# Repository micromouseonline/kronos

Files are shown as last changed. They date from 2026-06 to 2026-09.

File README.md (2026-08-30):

# KRONOS: Hardware-Synchronized Robotic Timing Gates

**KRONOS** is a distributed, microsecond-accurate wireless robotic timing gate ecosystem built on the ESP32 platform. It is designed for high-performance track automation and precision race scoring without the need for physical connection cables.

---

## Technical Highlights

* **Hardware-Level Precision:** Achieves an average tracking accuracy gap of $2.36\,\mu\text{s}$ (with a worst-case variance of $55\,\mu\text{s}$) by anchoring remote nodes to the 1 MHz Timing Synchronization Function (TSF) clock embedded directly within Wi-Fi beacon frames.
* **Self-Healing Clock Recovery:** Eradicates tracking errors from network drops or stack resets. If a node misses AP beacons, an autonomous audit engine seamlessly reconstructs missing timestamps using a disciplined internal monotonic processor clock (`esp_timer_get_time()`).
* **Asynchronous FreeRTOS Queues:** Decouples physical event capturing from network transmission. Pins use high-speed hardware interrupts to instantly cache telemetry into RAM queues, safely buffering rapid-fire bursts down to $35\text{ ms}$ intervals.
* **Resilient Network Architecture:** Uses HTTP over TCP (`HERMES` protocol) to guarantee delivery. Variable transport latencies or retransmission lags become irrelevant because the hardware event timestamp is baked directly into the packet payload.

---

## Naming Conventions & System Layers

* **KRONOS:** The overall distributed wireless network topology and codebase.
* **HADES:** The central PC software hosting the database, event management and scoring system. *(planned, not in this repo)*
* **ATLAS:** The standalone Wi-Fi Access Point acting as the authoritative field master clock, and providing a private WiFi BSSID.
* **CERBERUS:** The multi-threaded gate edge hardware/software handling gate messages and clock audits.
* **HESPERUS:** The physical maze/track gate sensor modules.
* **HERMES:** The concise HTTP application-layer packet payload protocol.
* **ARES:** The pulse generator that stimulates the gates during testing.
* **ARGUS:** The hundred-eyed giant that collects and analyses gate data. *(planned, not in this repo)*

---

## Quick Start & Hardware Setup

### 1. Prerequisites

* **Access Point (`ATLAS`):** Any standard domestic or portable router configured as a standalone network subnet.
* **Gate Nodes:** Dual-core ESP32 or ESP32-S3 boards (standard single-core variants like the C3 require Level 2+ high-priority interrupt configurations to minimize jitter).
* **Sensors (`HESPERUS`):** Photodiode or laser break-beam circuits wired to the designated edge input pins.

### 2. Network Provisioning

The central `HADES` web server must be mapped to a fixed, unmoving network coordinate via a DHCP reservation or static IP mapping. Alternatively, the system might use multicast DNS (`mDNS`), allowing gates to dynamically connect via a hostname (e.g., `http://timing.local`).

### 3. Visual Diagnostics on Track

Onboard LEDs can provide real-time state confirmation without an attached serial monitor e.g.
* **LED Off:** System operating normally; network clearing traffic flawlessly.
* **LED Solid On:** Wi-Fi link down or server stalling; data packets are currently backing up safely inside the internal FreeRTOS memory queue.

The gate hardware supports BLE - this could be used as an independent diagnostic channel.

---

## For More Information

For detailed clock calibration formulas, circuit diagrams, power management deep-dives (Wi-Fi Modem Sleep configurations), and field-trial telemetry logs, please refer to our full [**System Architecture Documentation Page**](docs/KRONOS-SYNCHRONIZED-TIMING-GATES-ARCHITECTURE.md).

For the network provisioning approach (config-portal Wi-Fi setup, mDNS discovery), see [**docs/PROVISIONING.md**](docs/PROVISIONING.md). For the proposed application-level delivery-reliability scheme, see [**docs/RELIABILITY.md**](docs/RELIABILITY.md).

For how the PlatformIO build environments are structured and composed (board/feature configuration, adding a new board), see [**PLATFORMIO.md**](PLATFORMIO.md); for the manual Arduino IDE conversion fallback, see [**ARDUINO.md**](ARDUINO.md).

For CERBERUS specifically — the gate controller sub-project, its architecture, race state machine, and an operator's guide to running a race day — see [**cerberus-gate-controller/docs/**](cerberus-gate-controller/docs/), starting with [`SYSTEM-DESCRIPTION.md`](cerberus-gate-controller/docs/SYSTEM-DESCRIPTION.md) and [`OPERATOR-GUIDE.md`](cerberus-gate-controller/docs/OPERATOR-GUIDE.md).

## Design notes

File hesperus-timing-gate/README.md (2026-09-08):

# hesperus-timing-gate

ESP32 firmware for the two-gate infrared timing system's gate boards.
Gates synchronise timing via Wi-Fi TSF and report `TRIGGER_A`/`TRIGGER_B`
events to `cerberus-gate-controller` over a persistent WebSocket
connection, with dynamic EMA-weighted clock disciplining against drift.

See [CLAUDE.md](CLAUDE.md) for firmware design details and
[../PLATFORMIO.md](../PLATFORMIO.md) for the workspace build guide.

## Targets

| PlatformIO env | Board |
|---|---|
| hesperus-gate-s3-zero | Waveshare/generic ESP32-S3-Zero |
| hesperus-gate-s3-super-mini | ESP32-S3 Super Mini |

## Build

```
pio run -e hesperus-gate-s3-zero
pio run -e hesperus-gate-s3-zero -t upload
```
from `firmware/`.

## Flashing and serial access (ESP32-S3 boards)

The S3 boards (`hesperus-gate-s3-zero`, `hesperus-gate-s3-super-mini`) use
native USB CDC rather than a USB-serial bridge chip, so the port can be
fiddly to get back after a reflash. `boards.ini` already sets:

```ini
build_flags =
  -D ARDUINO_USB_CDC_ON_BOOT=1    ; Enable USB CDC (virtual COM port) at boot
  -D ARDUINO_USB_MODE=1           ; Select device mode for USB (value 1 = device)
  -D ARDUINO_TINYUSB=1            ; Use TinyUSB stack for native USB functionality
```

If the port doesn't come back after flashing, a manual reset or power
cycle gets it to a known state.

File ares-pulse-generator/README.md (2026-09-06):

# ares-pulse-generator

ESP32-S3/C3 bench tool that simulates photodiode/beam-break triggers into
a real `hesperus-timing-gate` board under test, by driving three
active-low GPIO outputs (`TRG_ARM`/`TRG_START`/`TRG_GOAL`). Trials are
runtime-selectable over serial (`list`/`run`/`arm`/`status`) or fired by a
physical button against whatever trial is currently armed.

See [CLAUDE.md](CLAUDE.md) for firmware design details and
[../PLATFORMIO.md](../PLATFORMIO.md) for the workspace build guide.

**Note:** since hesperus's `base_s3_zero`/`base_s3_super_mini` boards moved
to the analogue dual-EMA beam-break path (`beam-sensor.h`), ARES's digital
pulse output can no longer trigger those boards — see `TODO.md`'s
`ares-pulse-generator` section.

## Targets

| PlatformIO env | Board |
|---|---|
| ares-pulser-s3-zero | Waveshare/generic ESP32-S3-Zero |
| ares-pulser-s3-super-mini | ESP32-S3 Super Mini |
| ares-pulser-c3-super-mini | ESP32-C3 Super Mini |
| ares-pulser-c3-xiao | Seeed XIAO ESP32-C3 |

## Build

```
pio run -e ares-pulser-s3-zero
pio run -e ares-pulser-s3-zero -t upload
```
from `firmware/`.

## Flashing and serial access (ESP32-S3 boards)

The S3 boards (`ares-pulser-s3-zero`, `ares-pulser-s3-super-mini`) use
native USB CDC rather than a USB-serial bridge chip, so the port can be
fiddly to get back after a reflash. `boards.ini` already sets:

```ini
build_flags =
  -D ARDUINO_USB_CDC_ON_BOOT=1    ; Enable USB CDC (virtual COM port) at boot
  -D ARDUINO_USB_MODE=1           ; Select device mode for USB (value 1 = device)
  -D ARDUINO_TINYUSB=1            ; Use TinyUSB stack for native USB functionality
```

If the port doesn't come back after flashing, a manual reset or power
cycle gets it to a known state. The C3 envs don't set `ARDUINO_TINYUSB`
and aren't affected by this quirk.

**Also note:** resetting the ARES board while wired directly to a pair of
hesperus boards can produce a spurious trigger glitch on both gates — make
sure it has fully reset before starting a trial or a new log (bench-test
tooling only, no bearing on production use; see `TODO.md`).

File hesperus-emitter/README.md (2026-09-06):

# hesperus-emitter

ESP32-S3-Zero bench emitter: a button-driven, deep-sleeping stimulus box
for the emitter side of a Hesperus gate. It shares its enclosure with
`hesperus-timing-gate` but carries a much simpler board.

See [CLAUDE.md](CLAUDE.md) for firmware design details and
[../PLATFORMIO.md](../PLATFORMIO.md) for the workspace build guide.

## Build

```
pio run
pio run -t upload
```
from `firmware/`.

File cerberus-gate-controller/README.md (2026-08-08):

# cerberus-gate-controller

ESP32 gate-timer controller with a touchscreen UI. Race commands (ARM,
START, GOAL, new mouse) are driven by a physical NeoKey 1x4 keypad, or
remotely over serial/HTTP; touch drives on-screen navigation only, not
race commands. Shared input system across four board targets. There is
no Supervisor/menu state machine -- race progress is tracked entirely by
`RaceState`, decoupled from screen navigation.

See `docs/OPERATOR-GUIDE.md` for how to run a race day, and
`docs/SYSTEM-DESCRIPTION.md` for the full architecture.

## What it illustrates

- **Producer-agnostic input dispatch** -- physical NeoKey buttons (and,
  in code, an unused GPIO-button path) all post the same `ButtonID`
  events into one FreeRTOS queue from a Core-1 polling task. The main task
  drains the queue and dispatches through a single handler, so
  application logic never knows which physical device generated a press.
  See `docs/INPUT-SYSTEM.md` for the full design.
- **Runtime hardware presence detection** -- the NeoKey module is optional
  on every board; a background task probes for it non-blockingly and the
  rest of the app degrades to silent no-ops if it's absent or unplugged.
- **Multi-target board config** -- `platformio.ini` extends shared base
  environments from `boards.ini`; board-specific pins and display
  driver selection live in `lib/boards/`.
- **Runtime touch calibration** -- resistive-touch boards (XPT2046) persist
  a calibration to NVS and fall back to an interactive wizard if none is
  stored (`touch-calibration.h`).

## Targets

| PlatformIO env | Board |
|---|---|
| cerberus-esp32-s3-cyd-touch-freenove | Freenove FNK0104B ESP32-S3 CYD |
| cerberus-cyd2usb-diymalls-ili9341 | CYD2USB (DIYMalls, ILI9341 panel) |
| cerberus-cyd2usb-diymalls-st7789 | CYD2USB (DIYMalls, ST7789 panel) |
| cerberus-jc2432w328c | JC2432W328C |

## Build

From the command line, something like:

```
pio run -e cerberus-esp32-s3-cyd-touch-freenove
pio run -e cerberus-esp32-s3-cyd-touch-freenove -t upload
```

See the [workspace build guide](../PLATFORMIO.md) for details on targeting
different boards, and `docs/INPUT-SYSTEM.md` for how the input/dispatch
layer works.

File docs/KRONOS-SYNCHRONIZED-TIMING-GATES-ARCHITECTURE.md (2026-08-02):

# ESP32 Wi-Fi Timing Gates: A Hardware-Synchronized Architecture

> **Abstract** - Distributed timing architectures deployed across wireless networks typically suffer from variable network transport latency and operating system jitter. This paper presents **KRONOS**, a hardware-synchronized, microsecond-accurate robotic timing gate ecosystem built on the ESP32 platform. Rather than relying on standard network time synchronization protocols, the system anchors remote nodes to a centralized hardware clock timeline by capturing raw Timing Synchronization Function (TSF) timestamps embedded directly within local Wi-Fi beacon frames. To mitigate wireless stack resets and airtime contention, the edge firmware (**CERBERUS**) implements a multi-threaded FreeRTOS queue architecture decoupled from a secondary, autonomous self-healing processor clock audit engine. Empirical field trials across a dedicated local access point have demonstrated a system-wide pairing reliability of 100% over extended operational windows, maintaining a mean tracking accuracy gap of $2.36\,\mu\text{s}$ and a worst-case maximum variance of $55\,\mu\text{s}$.

---

**KRONOS** is a highly resilient, distributed hardware-synchronized timing ecosystem engineered for high-performance robotic track automation and precision race scoring. At its core, the system shifts the burden of microsecond synchronization away from complex software algorithms and hands it directly to the physical layer of your wireless infrastructure. By leveraging the native 1 MHz Timing Synchronization Function (TSF) counters broadcast inside standard Wi-Fi beacon frames, the system establishes an immutable, synchronized field timeline. Whether tracking rapid-fire beam breaks on the track surface or bridging asynchronous network outages across the wireless spectrum, this architecture ensures that timing metrics are captured instantly, buffered securely, and recorded accurately. This document outlines the structural framework, naming conventions, firmware logic, and backend configurations that allow the system to maintain a sub-100 microsecond timing accuracy without physical connection cables.

---

## System Hierarchy & Component Roles

To navigate this documentation, the architecture is broken down into eight discrete layers named after classical mythology (because I could), establishing a clear chain of command from physical track sensors to the master scoreboard:

* **KRONOS** (*Keep‑alive Resilient Orchestration for Networked Optical Systems*): **The Overall Ecosystem.** Represents the complete network topology, the combined codebases, and the mathematical clock calibration models working as one unified system.
* **HADES** (*Host Automation, Detection, Event Scoring*): **The Central PC Software.** The lord of the central network; it hosts the database, runs the retrospective sliding-window pairing algorithms, and maintains the official scoreboard.
* **ATLAS** (*Access‑point Time‑Locking and Authoritative Synchronization*): **The Wi-Fi Access Point.** The absolute ruler of time on the track. Through hardware TSF beacon frames, it dictates the master timeline and physically ferries data packets across the air.
* **CERBERUS** (*Clock‑disciplined Event Recorder & Bridge for ESP‑based Race Unit Synchronization*): **The Gate Controller.** The multi-threaded FreeRTOS application monitoring the gates. It handles hardware interrupts, executes continuous clock sanity audits, and caches events in RAM during network drops. It collates raw gate notifications into clean split and lap times. It can act as a stand-alone scoring device if needed.
* **HESPERUS** (Hardware for ESP‑based Sensor Precision Events and Reliable Uplink Signals): **The Physical Sensor Gates.**  The independant gate hardware and edge software. They control and monitor the individual maze/track sensors, tag events with microsecond-accurate timestamps and sends notifications to the gate controller.
* **HERMES** (*Hyper-accurate ESP32 Remote Measurement Exchange System*): **The Communication Protocol.** The application-layer HTTP packet layout that swiftly carries microsecond timestamps from the individual HESPERUS gates to CERBERUS for processing into event times..
* **ARES**: **The Pulse Generator.** Stimulates the gates with reference triggers during testing and calibration.
* **ARGUS**: **The Data Collector.** The hundred-eyed giant that collects and analyses gate data. Not yet implemented.

## Introduction

Wi-Fi Access Points (APs) generate beacon frames to advertise their presence approximately 10 times per second. While this rate is not strictly guaranteed - especially in congested wireless environments - it would be highly unusual not to receive a beacon frame at least once per second.

Among the critical metadata contained within a standard beacon frame is the **Timing Synchronization Function (TSF)** timestamp.

The TSF keeps the internal timers of all client stations (STAs) within the same Basic Service Set Identifier (BSSID) - meaning those connected to the same access point - in close synchronization. The AP and each connected station maintain an internal 64-bit counter that increments at $1\text{ MHz}$. Left unmanaged, these individual clocks would inevitably drift apart due to differences in local crystal oscillators.

However, whenever a station intercepts a beacon frame, it automatically updates its local TSF counter with the authoritative value provided by the AP. This hardware-level mechanism ensures that all stations maintain an internal clock likely to match within a few tens of microseconds, and frequently within less than ten microseconds.

With 64 bits of headroom, this microsecond counter will not wrap around for more than 500,000 years. While the absolute value of the counter holds no useful meaning on its own - typically resetting to zero whenever the AP reboots - its relative value across multiple units is highly valuable for distributed event tracking.

---

## Sources of Error

Maintaining the local TSF counter is handled entirely at the silicon and network-stack layer; client software requires no manual overhead to ensure correct operation. As noted, although beacon frames may arrive irregularly due to airtime contention, an individual station's clock will not drift by more than a few microseconds over a one-second window.

However, capturing this value in software introduces real-world variables:

* **Operating System Jitter:** In standard ESP32 deployments, the Wi-Fi drivers run on FreeRTOS, with the core wireless network components typically bound to Core 0. Because FreeRTOS may be executing an alternate application task at the exact millisecond a physical event occurs, task-switching overhead can introduce a latency of several microseconds.
* **Hardware Interrupt Latency:** Even when bypassing FreeRTOS task scheduling by deploying a direct hardware interrupt service routine (ISR) to detect the gate trigger, a small execution latency remains. Furthermore, fetching the internal counter register itself takes a couple of microseconds. This latency can be drastically minimized by utilizing the `IRAM_ATTR` macro, forcing the compiler to place the ISR code directly into fast internal RAM rather than executing it out of slow flash memory.
* **Single-Core Constraints:** Single-core variants, such as the ESP32-C3, must process all application code and Wi-Fi drivers on the same CPU core. This inherently increases worst-case jitter compared to dual-core architectures like the standard ESP32 or ESP32-S3. To safeguard timing accuracy on single-core variants, it is highly recommended to configure **High-Priority Interrupts** (Level 2 or above) to allow the timing gate to preempt active network stack processes.

Because the counter remains easily readable in code, it serves as an ideal, immutable timestamp for any local client event. Since all stations locked to the same AP share a synchronized hardware counter, the system can reliably determine the exact time delta between widely separated clients to the identical degree of precision.

While individual client latencies and hardware jitter add up mathematically when calculating the true period between remote events, employing standard embedded best practices makes it relatively easy to guarantee an overall system error of less than $100\,\mu\text{s}$, and frequently better than $50\,\mu\text{s}$.

Once the TSF counter value is latched during an event, the remaining application code can take a relaxed approach to processing and transmitting the data - provided a rapid succession of events does not overwhelm the buffer. Even in high-frequency scenarios, a standard FreeRTOS queue can safely buffer timestamps and event IDs to be systematically offloaded by a secondary networking task. The only strict rule is that the long-term average rate of incoming events does not exceed the network's average transmission throughput.

---

## Power Management

Running an ESP32 with its radio continuously enabled draws more current than is preferable for a long-term, battery-powered field deployment. For example, an ESP32-S3 with an active radio transmitting short HTTP requests once per second will draw an average of $50\text{ to }70\text{ mA}$.

If this power load is too steep for the target battery capacity, the remote station can be configured to use **Wi-Fi Modem Sleep**. In this mode, the power-hungry RF circuitry is placed into a low-power state between beacon intervals while keeping the internal hardware TSF counter fully operational. The chip automatically wakes up its receiver just in time to listen for the scheduled beacon frame - a task it coordinates using the TSF clock itself, which is exactly what the feature was natively designed to do.

Utilizing Wi-Fi Modem Sleep can drop average current draw down to as little as a quarter of standard active listening mode. Meanwhile, the localized event detection logic continues to operate unimpeded, instantly waking the radio to transmit logged events before returning the chip safely back to sleep.

---

## Reporting Events

The remote timing gates act as decentralized, battery-operated nodes. Because they rely on a central Wi-Fi access point for microsecond-accurate time synchronization, it is highly practical to use that same established wireless link to report timing data back to a central master station.

These data reports are encapsulated within Transmission Control Protocol (TCP) packets. A defining feature of TCP, compared to the simpler User Datagram Protocol (UDP), is its connection-oriented nature: packets cannot silently vanish without the sender's explicit knowledge. Once sent, the TCP protocol automatically manages handshakes, sequencing, and retransmissions, guaranteeing successful delivery or providing an immediate notification of hardware connection failure.

That absolute transport reliability comes at a chronological cost: there is no obvious way to predict exactly how long a TCP packet takes to arrive and be processed by the receiver, especially if wireless congestion forces packet retransmissions.

However, because the system embeds the locally latched 64-bit TSF event timestamp directly into the packet payload, variable network transport latency becomes completely irrelevant. Whether the message takes $5\text{ milliseconds}$ to clear the air or is delayed by a major network glitch for $500\text{ milliseconds}$, the enclosed timestamp tells the receiver precisely when the physical event occurred.

### Application Layer: HTTP

Knowing that the Wi-Fi stack guarantees data delivery via TCP satisfies only part of the development lifecycle; designing custom, robust communication protocols from scratch is a complex and error-prone engineering challenge. It is far more efficient to layer a highly common, well-established application protocol on top of TCP. For this system, the most logical choice is Hypertext Transfer Protocol (HTTP).

Using a foundational HTTP `GET` request, a remote gate packages its data into a simple, human-readable text URL string containing parameters such as the Gate ID, the microsecond-accurate timestamp, the target BSSID, the calculation clock mode, and the trigger type string. This string is transmitted to a local web server at a known address. The web server parses the incoming request, handles the underlying database or timing logic, and returns a standard response.

This model establishes a double layer of operational guarantees:

1. **The Transport Layer (TCP):** Confirms the physical data packets arrived at the destination network stack.
2. **The Application Layer (HTTP):** Employs standard status codes (e.g., `200 OK`) to confirm that the server software successfully received, interpreted, and validated the data message.

As an added benefit, the server's HTTP reply can pass custom text payloads back to the remote gate, providing a built-in channel for remote commands, status updates, or system diagnostics.

To ensure the remote gate's radio is not powered up any longer than necessary, messages should be kept highly concise. While creating and tearing down a standard TCP/HTTP connection involves a handful of auxiliary overhead packets, the entire transaction should still conclude within a few milliseconds under normal conditions.

### Web Server

With the remote gates successfully capturing and communicating high-accuracy timestamps, the central collecting device functions purely as a web server. In principle, this server could reside anywhere in the world via the internet. Practically, however, it should be deployed locally on the exact same Wi-Fi subnet. A local topology completely eliminates external internet overhead, removes reliance on cellular or WAN connectivity in the field, and ensures a highly secure, closed ecosystem.

The local collecting web server can be tailored precisely to the scope of the event. At its most basic, it can comprise a simple Python script running on a Raspberry Pi or a low-power laptop. Alternatively, it can run efficiently on another microcontroller, such as an ESP32-based **Cheap Yellow Display (CYD)** programmed in C++.

Depending on available processing resources, this web server can host the entire race-management system independently. For more lightweight hardware implementations, it can serve as a local bridge controller, parsing the incoming Wi-Fi messages and streaming them over a physical serial port to a host computer running comprehensive desktop scoring software.

A useful side-effect of deploying an HTTP web server to collect and process data is that other devices on the same local network can seamlessly query the server for parallel applications. Depending on the server's backend configuration, it can concurrently stream data to local secondary displays to show live runtimes, or populate an interactive, real-time leaderboard for spectators and officials.

---

## Provisioning

A dedicated local Wi-Fi network is easy to establish using almost any inexpensive, commercial domestic router configured as a standalone Access Point. The router handles broadcasting the BSSID, managing a clean wireless channel, dynamically allocating local IP addresses to clients, and ensuring seamless device intercommunication.

A dedicated commercial router will offer significantly better antenna arrays and RF performance than a software-defined access point hosted on an embedded computer like a Raspberry Pi. While a single Raspberry Pi *could* technically act as both the network AP and the collecting web server, separating these roles into distinct hardware enclosures enhances overall system resilience and flexibility - even if it makes the physical field setup slightly more burdensome.

Network addressing requires careful design. The remote gates must know the exact IP address of the web server to direct their HTTP requests. Conversely, the web server does not need prior knowledge of the gates' IP addresses because every incoming HTTP message payload includes an identifying token. The management software can dynamically map that unique identifier to a physical track location, such as `"Start Gate"` or `"Finish Gate"`.

Consequently, the web server must be assigned a fixed, unmoving IP address, which is easily configured on any standard access point using a static IP mapping or a DHCP reservation.

An elegant alternative is utilizing a dynamic local protocol such as **multicast DNS (mDNS)**. Under this architecture, the web server advertises its friendly name on the local subnet (e.g., `http://timing.local`). The remote gates locate the server dynamically by its hostname rather than a hardcoded numerical address, making the entire ecosystem truly plug-and-play. Support for mDNS is natively built directly into the core ESP32 Wi-Fi stack.

---

## Initial Baseline Testing

To evaluate empirical system reliability, an isolation test was executed using two identical ESP32-S3 boards connected to a shared 1PPS (Pulse Per Second) hardware signal generator. The boards acted as simulated timing gates, generating an HTTP `GET` request containing a copy of the locally latched TSF counter on every incoming hardware edge.

A host PC running on the same local Wi-Fi network executed a Python script acting as the collection web server. The script evaluated pairing metrics by matching concurrent entries from both gates. A valid pair was defined as two incoming requests (one from each gate) whose internal TSF timestamps differed by less than $200\text{ ms}$. This $200\text{ ms}$ threshold provides a safety buffer orders of magnitude wider than any expected network transmission variance generated by a simultaneous event.

Under this framework, pairing failures indicate lost data payloads or server-side processing bottlenecks. Because the requests travel over TCP, genuine packet drops are managed automatically by the lower-level network interface card (NIC) stacks, making complete message dropouts exceedingly rare.

### Empirical Results and Discovery

Following $14\text{ hours}$ of continuous operation across a standard domestic Wi-Fi network comprising $52,200\text{ successful pairs}$, the system logged **121 failed matches**. While this corresponds to a seemingly minor $0.23\%$ error rate, an ideal hardware-synchronized architecture requires zero systematic failures.

Forensic analysis of the server logs revealed three distinct root causes behind these missed pairings:

1. **Server-Side Thread Bottlenecks:** Standard Python environments are bound by the Global Interpreter Lock (GIL). A combination of console logging bottlenecks and thread scheduling latency can cause the script to momentarily stall, failing to process sequential incoming data within the matching loop window.
2. **Network Layer TCP Retransmission Lag:** In a contested RF environment, momentary Wi-Fi link degradation forces the lower network stack to enter automatic retry loops. While the data is never lost, it can be delayed anywhere from $200\text{ to }1000\text{ ms}$. By the time the delayed request reaches the server, its partner has already been evaluated and flagged as unmatched.
3. **Wi-Fi Subsystem Resets (The Primary Error Source):** The single most disruptive anomaly observed was a localized clock reset within the ESP32 Wi-Fi stack. If a client station misses consecutive AP beacon frames or undergoes an internal radio re-association, the network stack temporarily uninitializes the virtual interface. Upon recovery, the local TSF register is cleared to **zero** while the hardware waits for a fresh beacon frame to resynchronize its timeline. Events recorded during this recovery window contain an invalid TSF value of zero, breaking the server's pairing algorithms and creating cascading tracking errors.

---

## High-Frequency Gate Handling & Time Recovery

A single gate board may support multiple asymmetrical trigger inputs. For example, a start cell controller must process both a proximity/presence detector and an explicit start sensor. Consider a high-performance robot returning to a start cell: accelerating or decelerating at $20\text{ m/s}^2$ allows a vehicle traveling at $2.5\text{ m/s}$ to come to a complete stop within $168\text{ mm}$. Under these real-world mechanics, the robot will trip the presence sensor a mere **$35\text{ ms}$** after cross-cutting the primary start beam.

To handle rapid-fire bursts on the order of a few tens of milliseconds, the gate must decouple physical event recording from data transmission. Pin interrupts must be aggressively debounced within a safe hardware-compatible lockout window ($20\text{ ms}$ or $20,000\,\mu\text{s}$) to avoid missing back-to-back entries while throwing out mechanical contact noise.

Leveraging FreeRTOS, the hardware interrupt service routine (ISR) instantly captures telemetry metrics, packages them into a `GateEvent` data structure, and pushes them onto an internal **FreeRTOS Queue** (`networkQueue`) sizing up to 10 events. A detached network worker task running at an elevated priority (Priority 2) systematically processes this queue at its own pace. This design allows the edge node to capture bursts of events at microsecond intervals, streaming them out over HTTP as network bandwidth permits without stalling the physical sensors.

### Autonomous Self-Healing Clock Recovery

To completely eliminate the temporal errors caused by Wi-Fi stack resets and zeroed counters, the edge firmware employs a continuous timeline audit utilizing a secondary, independent hardware clock: the internal ESP32 64-bit monotonic processor timer (`esp_timer_get_time()`).

Unlike the volatile TSF clock, this processor clock is driven directly by the internal CPU crystal oscillator. It ticks continuously at $1\text{ MHz}$ from the exact microsecond of boot, remaining completely unaffected by radio dropouts, channel switches, or network re-associations. Because both clocks increment at an identical $1\text{ MHz}$ frequency, their relationship is linear and behaves according to a predictable offset.

The self-healing algorithm operates as follows:

1. **Simultaneous Capture:** The hardware ISR captures both the `tsf_observed` value and the `processor_clock` value at the exact microsecond the physical pin drops.
2. **Continuous Sanity Auditing:** On every incoming event, the background worker task calculates the elapsed time since the previous event using the rock-solid processor clock. Multiplying this elapsed time by a dynamically adjusted tracking scale factor (`clock_alpha`) and adding it to the previously recorded TSF baseline establishes an **expected TSF value**.
3. **Drift Evaluation:** The firmware compares the expected TSF value against the raw observed TSF value. If the observed clock matches the expected timeline within a strict pre-determined tolerance margin of **$\le 500\,\mu\text{s}$** (`DRIFT_MARGIN_US`), the Wi-Fi stack is verified healthy.
4. **Live Runtime Calibration:** When the timeline is healthy, if more than 4 seconds have passed since the last step, an updated snapshot is taken. The firmware calculates the instantaneous drift ratio between the actual TSF delta and the processor delta. This is fed into an Exponential Moving Average (EMA) filter using a $10\%$ weight coefficient (`EMA_ALPHA = 0.10`) to update `clock_alpha`, smoothing out localized network beacon jitter:

$$\text{clock\_alpha} = (0.10 \times \text{instant\_alpha}) + (0.90 \times \text{clock\_alpha})$$

5. **Autonomous Synthesis:** If the observed TSF clock reads zero or drifts outside the permitted $500\,\mu\text{s}$ threshold - indicating an active Wi-Fi subsystem reset - the firmware rejects the stack value. It flags the packet mode as `"SYN"` and seamlessly reconstructs the true timestamp using the current monotonic processor clock extrapolated from the last known stable baseline coordinates:

$$\text{TSF}_{\text{synthesized}} = \text{TSF}_{\text{last\_good\_observed}} + (\text{ElapsedProcessorClock} \times \text{clock\_alpha})$$

6. **Circuit Breaker Recovery:** If the router timeline undergoes a genuine hardware step or permanent plateau shift, the audit engine will detect consecutive failures. If the discrepancy persists for **5 consecutive cycles**, the firmware triggers an override recovery mechanism, accepting the new router baseline shift as valid and resetting calibration parameters to clear the lockdown.

---

## Transport Resiliency and Application Timeouts

While the edge-level clock recovery engine ensures flawless timestamp generation, the timing gate must still manage structural communication failures, such as prolonged Wi-Fi unavailability or total server dropouts.

A completely lost message is identified when the background network task fails to receive an HTTP `200 OK` acknowledgment from the server. This recovery path requires a multi-layered timeout strategy:

* **Lower-Level TCP Retries:** The underlying network interface stack (lwIP) automatically handles packet delivery failures in the background. If an individual Wi-Fi frame collides or is dropped due to RF interference, the stack executes an automatic exponential backoff retry loop (retransmitting at roughly $200\text{ ms}$, $1\text{ s}$, $2\text{ s}$, and $4\text{ s}$).
* **Application-Level HTTP Timeouts:** To prevent a stalled server from permanently locking up the background worker task, an application-level HTTP timeout is enforced at **$2500\text{ ms}$**. If the server fails to reply within this window, the gate closes the network socket, flags a transmission error, and retains the event to allow subsequent items in the FreeRTOS queue to process.

### Passive Retry Pacing and the Hard Watchdog Circuit

Rather than saturating the RF space during an active network drop, the system divides connection recovery into two distinct states monitored inside the primary `loop()` thread:

* **Passive Retry Pacing (Standard Outage):** If the connection drops but the total outage window remains under 15 seconds, the gate executes quiet, passive retry print tracking paced at 3000 ms intervals.
* **Hard Stack Watchdog Reset (Zombie State):** If the Wi-Fi status remains disconnected for **more than 15 seconds**, the firmware assumes the underlying wireless stack has entered a fatal zombie state or suffered a lockup. The system fires a hard network teardown command:
```cpp
WiFi.disconnect(true, true); // Turns off the radio and completely purges saved credentials

```

After a $500\text{ ms}$ physical hardware cooling delay, the radio interface is completely rebuilt from scratch and issued a fresh `WiFi.begin(ssid, password, 0, bssid)` command to re-establish communications.

### Real-Time Visual Backlog Indicator

An external indicator LED (`LED_PIN = 2`) provides real-time diagnostic status on the track without requiring a serial connection. By tracking the state transitions of `uxQueueMessagesWaiting(networkQueue)` via a static edge-detection variable, the pin changes state instantly:

* **LED remains OFF:** Normal operations. Data is offloading faster than it is arriving.
* **LED stays solid ON:** The network link is down or the server is stalling. Data packets are building up in RAM, indicating that the network queue is stuck.

---

## Gate Present Heartbeat & Diagnostics

It is possible for a gate to fail or drop out entirely during a contest due to a sudden power failure, localized RF interference, or because the radio temporarily lost contact with the Access Point (AP). To detect these edge faults proactively, each gate transmits an explicit keep-alive heartbeat message (`"HB"`).

To prevent synchronized network collisions where multiple nodes inadvertently flood the access point simultaneously, the heartbeat relies on a unique prime number interval. A FreeRTOS software timer handles the delivery loop, firing exactly every **$5147\text{ ms}$**.

The master server ledger monitors the presence of these incoming heartbeats. If a gate falls silent for a prolonged window exceeding 15 seconds (matching the gate’s internal hard reset threshold), the server immediately flags a system fault to notify the operator.

Field trials demonstrate that a gate may drop out for several seconds after losing contact with the server, but because events remain protected inside the asynchronous queue, it will seamlessly dump its backlog in an automated rapid catch-up burst the absolute millisecond the link re-establishes.

---

## Test Results

One trial conducted over a period of approximately 3 hours collected 11,630 pairs of gate data at a continuous cadence of one pair per second. Throughout this evaluation window, there were zero mismatched or dropped messages. The average hardware gap between the times recorded by the gates was $18.4\,\mu\text{s}$. While this indicates impressive system-wide consistency, the overall metric conceals an insightful observation.

Below is the plotted telemetry showing the hardware timing gap measured across the duration of the test:

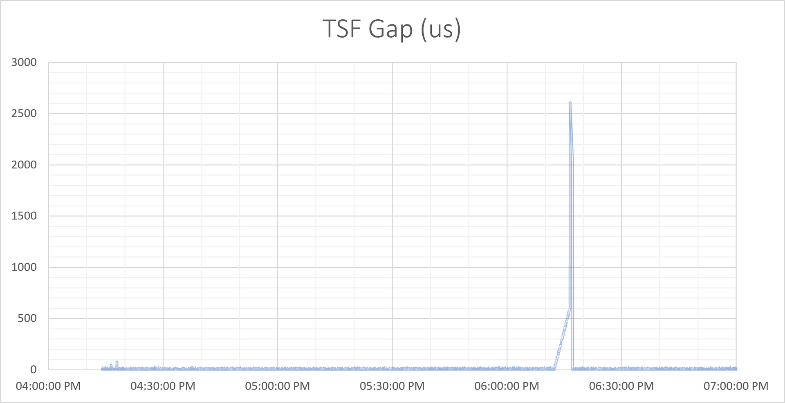
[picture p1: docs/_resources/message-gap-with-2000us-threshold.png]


As illustrated, at approximately 6:10 PM, the calculated gap began to increase perfectly linearly. Shortly thereafter, the gap stepped sharply to roughly $2000\,\mu\text{s}$ before steadily and linearly declining until it returned to near-zero.

The mechanism behind this excursion is that one of the remote gates missed consecutive beacon frames, causing its uncorrected local TSF clock to drift freely on its quartz crystal. Eventually, the variance relative to the expected baseline exceeded the threshold, prompting the timeline audit to reject the volatile network clock and engage the internal monotonic processor clock.

Because the processor clock's drift rate operated on a different slope relative to the alternate gate's clock, the error began to linearly converge. Once the affected gate intercepted a clear beacon frame from the Access Point, it successfully resynchronized its hardware TSF register, satisfied the sanity audit, and seamlessly returned control to the native TSF timeline - instantly restoring near-zero alignment.

The entire temporal excursion lasted just under 5 minutes, and the total drift was securely capped by the system. Consequently, even if a target had tripped the physical sensors during the absolute worst-case peak of this network blackout, the recorded runtime would have been protected and altered by no more than $2\text{ ms}$.

Discounting this single network-induced excursion, the true average TSF tracking gap across the 3-hour trial was an astonishing $1.73\,\mu\text{s}$, and never exceeded $77\,\mu\text{s}$.

Following that test, the additional protections for tracking clock drift and unexpected outages were added and the gates were connected to a more stable dedicated access point. On a domestic mesh network, there is a tendency for the access points to reconfigure arbitrarily during a long tests. However, when connected to a separate, stable portable router, the results are very consistent. Using the same 1PPS simultaneous trigger on two timing gates, the gap between the recorded times from each gate is recorded over a three-hour period (approx 11,000 triggers) and summarized in a histogram:

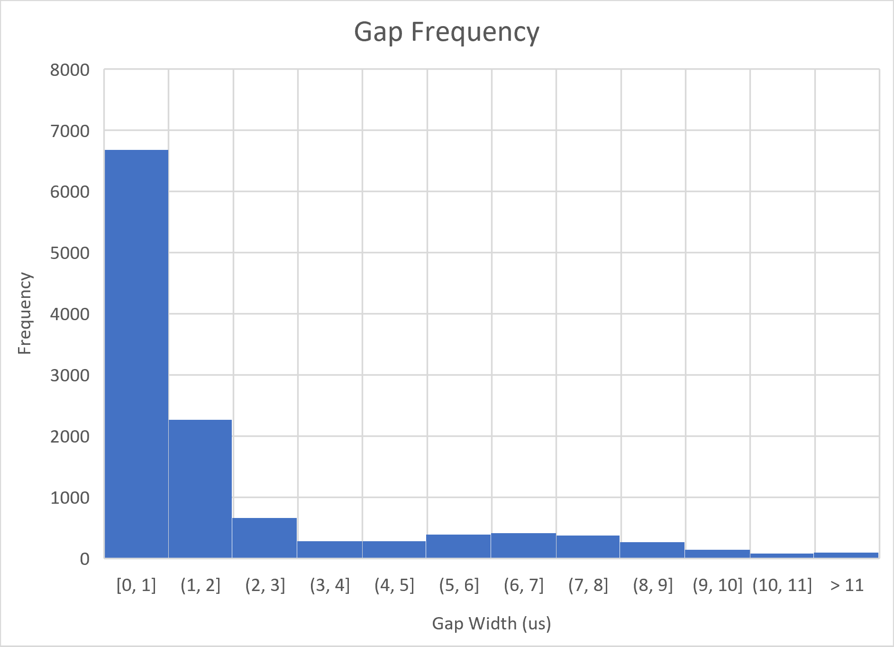
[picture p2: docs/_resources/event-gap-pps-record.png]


Note that the times are in microseconds. During that period, the mean gap was $2.36\,\mu\text{s}$ and the maximum gap was $55\,\mu\text{s}$. There were no lost notifications, no need for the synthetic time and no cumulative drift. There was one occasion where one of the gates was unable to send its notification. However, the event remained queued and was sent a little later. The timing information remained intact.

A further overnight trial generated nearly 60,000 matches. Analysis revealed the following statistics:

TSF Gap Statistics (µs)
| Metric | Value (µs) |
|---|---|
| Mean | 2.63 µs |
| Standard deviation  | 3.41 µs |
| Maximum | 55 µs |
| 99.9th percentile | ≈ 22 µs |

 - The average gap is only ~2.6 µs,
 - 99.9% of all gaps are under ~22 µs,
 - The worst outlier is 55 µs, which is still excellent for Wi‑Fi‑synchronized TSF timing.

---

## Limitations

 - Cheap consumer APs may not be able to look after more than 20-32 clients. Each gate is a client, as would be any remote displays or similar. Unlikely to be a real problem. by the time we have than many clients, we would be paying for more up-market APS that could handle 100 or more clients. For now, limit to 10 clients. Could be tested with a cluster of ESP32 nodes to see what happens.

 - Busy WiFi environments. The gate firmware review has testing schemes to evaluate that.

 - Multiple setups may be a problem because the credentials and identities are compiled in from a single source. Some kind of OTA configuration would be best. 

 - In a fairly quiet environment we should be able to easily run 3-4 independent systems with two gates. We might want, for example, classic maze, half-size maze, line-followers, pursuit, and drag race. That is 5 systems so the experiment needs to be done.

## Power Management and Alternative Transport Methods

### Power saving

Battery operated gates are clearly vulnerable to low-capacity batteries. Left fully operational, an ESP32-S3 might consume an average of 50mA while idde with very short bursts of 100mA or so while transmitting. We can, in our use-case, assume that the 50mA is about average during a session. Even with the processor in full modem-sleep with 
```
   esp_wifi_set_ps(WIFI_PS_MAX_MODEM);
```
the average current consumption is still quite high since the radio will keep waking up every three beacon frames or so to update the TSF clock. It must also wake up every time a broadcast frame arrives just in case it has to do something about it.

On that last issue, There are a surprising number of broadcast frames on any network but we can keep tem to a minimum by using a dedicated AP with the minimum of devices attached.

One obvious improvement might be to use a lower power device in the gate. An ESP32-C3 should be perfectly adequate for the task and might reduce the current draw by some tens of mA though it is hard to get a definite value without testing specific boards.

For significant power savings, we must use more cunning. In the configuration described above, the gates are continuously connected to the AP and listen for beacon frames in order to keep the local TSF counter closely synchronised with the network. If we were to characterise the local drift of the TSF counter and the internal processor clock, it might be possible for the radio to remain completely off for longer periods. Suppose the local clocks drifted by some 10ppm. That would mean a possible drift of 50us over the course of five seconds. This is still not very much. We could disable the radio for 5 second periods and turn it on for just long enough to capture a beacon frame. that contains enough information to re-sync the clocks and calculate an interpolation factor to characterise the drift.

When a physical event occurs during a radio blackout, it is instantly timestamped using the monotonic processor clock. The firmware then applies the drift compensation model to mathematically correct and re-time the event before queuing the notification packet.

Implementing this 5-second polling interval means that telemetry, commands, and heartbeat diagnostic data are systematically batched, introducing a maximum transmission delay of up to 5 seconds without sacrificing sub-microsecond event capture precision.
### Alternate Transport Methods: Connectionless OSI Layer-2 Messaging

Standard Wi-Fi traffic - specifically over TCP - offers the immense advantage of structural reliability. TCP packet delivery is fully guaranteed within a functional network, and the plaintext nature of HTTP payloads makes them simple to observe, interpret, and test. 

However, standard Wi-Fi introduces considerable power and processing overhead during connection creation and teardown. Maintaining an active Wi-Fi connection forces the edge node to participate in background subnet maintenance tasks, such as parsing multi-cast and broadcast frames. This processes unneeded data, places a continuous load on the CPU, and keeps the power-hungry RF circuitry operational.

A significantly leaner transport protocol exists in the form of **ESP-NOW**. Native to the Espressif ecosystem, ESP-NOW sits between UDP and TCP in terms of reliability but bypasses connection complexities. ESP-NOW packets utilize modified IEEE 802.11 vendor-specific action frames. They are directed to an explicit receiver MAC address, carry a concise single-frame payload, and feature built-in hardware acknowledgments (ACKs). 

Because link-layer retries are handled automatically at the silicon layer, an ESP-NOW frame is far more likely to reach its destination quickly than a standard UDP packet. To guarantee absolute transport resilience, a lightweight application-layer confirmation layer can easily be compiled on top. Under this paradigm, there is no network connection state to maintain and no handshake overhead - the firmware simply wakes the radio, fires a single layer-2 frame, verifies the hardware ACK, and instantly powers down.

Crucially, this shift does not sacrifice master timeline synchronization. The edge firmware can still monitor the master BSSID clock by passively capturing standard AP beacon frames. Every 5 seconds, the firmware enables Wi-Fi promiscuous mode, listens on the designated channel for a maximum window of 100ms until a beacon frame arrives from **ATLAS**, and extracts the authoritative TSF timestamp. 

While ESP-NOW requires more manual development overhead to coordinate custom packet sequencing and acknowledgement tracking, its minimal airtime footprint makes it the optimal choice for communicating precision event data within crowded or high-attenuation RF environments.

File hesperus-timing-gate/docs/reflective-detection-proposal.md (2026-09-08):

# Reflective Detection: Proposal and Assessment

> **Never implemented.** The detector actually running today is a dual-EMA
> fast/slow ratio detector over a transmissive break-beam — see
> `detection-mechanism.md`. This document is kept because the architectural
> analysis (Core 0/Core 1 placement, a secondary-processor alternative, real
> profiling data) remains relevant if reflective sensing is ever revisited.

## 1. The proposal

A self-calibrating reflective light gate: an IR LED and IR phototransistor
pair face a reflective baseline (not each other, as the current transmissive
design does) and detect an object passing through the gap with a minimum
dwell time of 7 ms.

To eliminate ambient-light calibration and saturation issues, the LED is
driven via hardware PWM whose duty cycle is dynamically controlled by a
low-pass-filtered feedback loop to hold the phototransistor output at a
target voltage (~35% full-scale deflection). Fast optical transitions
(objects passing) bypass the slow feedback loop and show up as transient
spikes in the error signal.

```
                    +-------------------------------------------------+
                    |                   ESP32-S3                      |
                    |                                                 |
  +--------------+  |  +-----------+    +-------------+               |
  |  IR LED      |<-+--| MCPWM     |    | Dual-Core   |               |
  +--------------+  |  | Timer/Op  |    | FreeRTOS    |               |
         |          |  +-----+-----+    +------+------+               |
   Optical Path     |        | Sync            |                      |
         v          |        v                 | Core 1 High-Pri Task |
  +--------------+  |  +-----------+           v                      |
  | Photo-Trans. |  |  | DIG ADC1  |----> [ Ring Buffer ]             |
  +------+-------+  |  | DMA       |           |                      |
         |          |  +-----------+           v                      |
  +------v-------+  |                 +------------------+            |
  | Hardware LPF |--+---------------->| 4-Tap FIR Notch  |            |
  +--------------+  |                 +--------+---------+            |
                    |                          |                      |
                    |            +-------------+-------------+        |
                    |            |                           |        |
                    |            v                           v        |
                    |  +-------------------+   +-------------------+  |
                    |  | High-Pass / Diff  |   | 2Hz LPF (Feedback)|  |
                    |  +---------+---------+   +---------+---------+  |
                    |            |                       |            |
                    |            v                       v            |
                    |    Threshold Detect         Duty Cycle Adjust   |
                    |   (Object Event >7ms)     (MCPWM Duty Reload)   |
                    +-------------------------------------------------+
```

### 1.1 Hardware interface & pin configuration

- **LED driver pin:** output driving the IR LED via a low-side MOSFET or BJT.
- **Phototransistor input pin:** ADC1 (e.g. `ADC1_CHANNEL_2` / GPIO3).
- **Front-end hardware filter:** passive RC low-pass filter (R = 1.5 kΩ,
  C = 100 nF, fc ≈ 1.06 kHz) between the phototransistor tap and the ADC pin,
  to attenuate high-frequency edges and RF spikes.

### 1.2 Peripheral configuration

**MCPWM (Timer0, Operator0, Generator0):** 20 kHz (50 µs period), initial
duty cycle 25% (adjustable 0.5%–85%). Configure a hardware trigger event at
the center of the active PWM pulse to phase-lock the ADC conversion to the
illumination.

**Continuous ADC with DMA:** ADC1, driven via GDMA/I2S DIG ADC controller
linked to the hardware timer at an effective 4 kHz sample rate, into a
circular DMA buffer (64-sample frames).

### 1.3 Signal processing pipeline

Runs on every incoming DMA buffer frame inside a dedicated, high-priority
FreeRTOS task.

1. **250 Hz/harmonic noise rejection** — 16-tap FIR moving average,
   implemented as an O(1) recursive average (`y[n] = y[n-1] + (x[n]-x[n-16])>>4`)
   so filter length doesn't cost extra per-sample time. Group delay 1.875 ms
   at 4 kHz — subtract this fixed offset from logged event times.
2. **Error signal** — `E[n] = y[n] - V_target` (target ≈ 35% of full scale,
   ~1433 counts at 12-bit).
3. **Fast path (object detection):** trigger when `|E[n]| > V_thresh` for
   ≥8 consecutive samples (~2 ms, to validate a 7 ms event), plus a
   derivative condition (`D[n] = y[n] - y[n-2]`) for leading-edge detection.
   Qualify events sustained for 2–100 ms.
4. **Slow path (closed-loop feedback):** first-order IIR low-pass on `E[n]`
   (α ≈ 0.00313 for fc ≈ 2 Hz at 4 kHz), driving a duty-cycle integrator
   (`Duty[k] = Duty[k-1] - Kp * FilteredError[n]`), soft-clamped to 1.0%–80.0%.

### 1.4 FreeRTOS task architecture (as originally proposed)

- **Optical engine task** — pinned to **Core 1**, `configMAX_PRIORITIES - 2`.
  Blocks on the ADC DMA event queue; on wake, runs the FIR filter, computes
  `E[n]`, runs the 2 Hz IIR control loop, evaluates trigger conditions, and
  dispatches an event on detection.
- **Application/communication tasks** — pinned to **Core 0** (Wi-Fi/BT,
  logging, UI, higher-level state machines), to keep the optical task free
  of interrupt/scheduling jitter.

(§2.2 below covers why this Core 1 placement doesn't fit hesperus's actual
architecture.)

### 1.5 Verification & edge-case requirements

1. The 2 Hz IIR cutoff means any transient under 50 ms (including the 7 ms
   minimum object passage) causes negligible duty-cycle shift, leaving the
   spike fully visible in `E[n]`.
2. ADC DMA queue needs ≥4 frame descriptors to avoid overflow during
   transient system interrupts.
3. Fixed-point/raw integer arithmetic for the FIR/IIR filters in the
   high-frequency ISR/DMA callback path.
4. Saturation guard: if `y[n]` pins at max ADC count even at minimum LED
   duty cycle, flag `AMBIENT_SATURATION_ERROR` and disable auto-tuning
   until light levels drop.

### 1.6 Latency and accuracy (as specified)

- **Detection latency: 2.25–2.5 ms** — RC filter (~0.15 ms) + FIR group
  delay (0.375 ms) + 8-sample threshold verification window (2.0 ms).
- **Timing jitter: ±0.125–0.25 ms** — ±0.25 ms from the 4 kHz sampling
  resolution, halved to ±0.125 ms by derivative-based edge interpolation
  between the two samples straddling the threshold crossing. Software
  jitter is negligible (<1 µs) since ADC conversions are hardware-DMA
  triggered.
- Against a 7 ms dwell time, a 2.5 ms latency flags the event roughly 35%
  of the way through the beam — comfortable margin before the object clears.

## 2. Feasibility assessment

### 2.1 Optical/mechanical

Reflective single-side sensing is a different physical sensing modality
from the current transmissive break-beam design (emitter and receiver on
opposite sides of the gap) — it needs a reflective baseline on the far side
and a different mechanical mount, not just a firmware change. Confirm this
is an intentional requirement (e.g. a mounting constraint) before pursuing
it further, since the proposal itself doesn't state a motivation.

### 2.2 Architecture: where does the DSP task run?

The spec's Core 1 placement for the optical engine task doesn't fit
hesperus's actual firmware architecture: Core 1 already carries the app's
highest-priority task (`TsfCaptureTask`, which does the ISR-unsafe
`esp_wifi_get_tsf_time()` read the cross-gate sync depends on) plus
`WsPump`/`UploadWorker`/`loopTask`. Dropping a new near-max-priority
DMA-driven task there risks contending with `TsfCaptureTask` and
reintroducing the class of Interrupt-WDT panic `main.cpp` was once changed
to avoid. Two architectures resolve this:

**Option A — single-chip (ESP32-S3), DSP task on Core 0 instead of Core 1.**
De-risked by measurement (§2.5): a 1000-simulated-run load trial
(`gather-stats-core0` branch, `test-data/load-tests/`, both gate boards,
~5044 s, Wi-Fi connected and WS session active throughout), profiled with
an `esp_register_freertos_idle_hook_for_cpu` idle-hit counter, found Core 0
idle-hit counts *higher* than Core 1's in both trials (goal board: mean
5312 vs 5165; start board: mean 5311 vs 5170 — ratio ~1.03), with tight
variance and no starvation dips. The trial itself was clean — no
panics/watchdog resets, every WS send acked on the first attempt. This
substantially de-risks placing the DSP task on Core 0, though see the
caveat in §2.5 before relying on these numbers today.

The remaining open question for Option A is whether both channels' ADC
sampling can share ADC1 alone: two channels at 4 kHz each is only ~8 kHz
aggregate, a small fraction of what ADC1's continuous DMA mode should
sustain, which likely removes any need for ADC2 (and ADC2's known conflict
with active Wi-Fi on this chip family). Worth confirming ADC1's actual max
aggregate continuous rate against the TRM before relying on it.

**Option B — secondary dedicated processor**, driving hesperus's existing
active-low sensor-pin interface with a clean pulse, so the ISR →
`triggerCaptureQueue` → `TsfCaptureTask` → `networkQueue` path doesn't
change at all. This removes the Core 0/1 contention question entirely (no
DSP work runs on the Wi-Fi/TSF chip) and leaves the already-validated sync
accuracy (2.36 µs mean / 55 µs max gap) and the ISR-safety fix completely
undisturbed — zero regression risk to the hardest part of the system to get
right. Trade-offs: extra BOM cost/board complexity per gate, inter-board
wiring/power, a second firmware codebase.

An ATtiny1604 (or similar tinyAVR 1-series part) is a comfortable fit for
this role, for reasons specific to how the algorithm is structured:

- The 16-tap FIR is already an O(1) recursive average — one subtract, one
  shift, one add per sample, plus a 32-byte delay line (trivial against
  2 KB SRAM).
- The 2 Hz IIR's fractional multiply (α ≈ 0.00313) can be implemented as
  `y += (x - y) >> k` — an integer shift, sidestepping the question of
  whether the core has hardware `MUL`.
- Threshold/derivative detection is pure compare-and-branch, no multiply.
- At 20 MHz and a 4 kHz per-channel sample rate, roughly 5000 cycles are
  available per sample (≈2500 if one chip time-multiplexes two channels at
  4 kHz each); the actual per-sample workload is on the order of tens of
  cycles — not a close call.
- PWM (TCA0/TCB0) and ADC are both hardware peripherals, so duty-cycle
  updates and sampling don't consume CPU cycles beyond issuing the
  read/write.

Two details worth confirming against the datasheet before committing, not
because either looks like a problem: the ATtiny's ADC is 10-bit rather than
the spec's assumed 12-bit (rescales cleanly — 35% of 1023 instead of 4095 —
but halves raw threshold-margin resolution), and the part's peak achievable
ADC sample rate (tinyAVR 1-series parts are generally well over the
~4–8 kHz aggregate this needs, but not confirmed against the exact figure).

### 2.3 Two channels per gate

Hesperus boards run two independent sensor channels per gate (ARM/START on
a start board, or both to GOAL on a goal board). Reflective detection would
need to replicate the whole emitter/detector/control-loop setup per
channel, which compounds §2.2's concerns rather than adding an unrelated
one: two independent closed-loop DSP pipelines roughly double the
per-sample compute wherever they run, strengthening the case for Option B
(a secondary processor scales by sizing that chip appropriately, without
touching hesperus's Wi-Fi/TSF chip at all).

Optical crosstalk between two reflective pairs mounted close together at
one gate was raised as a candidate new failure mode (no analog in the
current transmissive design) — **ruled out per the existing optical
design**, not a factor in the assessment above.

### 2.4 Latency requirement

Not actually a hard constraint: race timing is gate-to-gate relative, so
absolute detection latency only matters if it differs between gates. The
current microsecond-level sync accuracy is a deliberately stringent design
target, not a hard requirement — sub-millisecond is acceptable in practice.
This significantly de-risks the proposal's ~2.5 ms pipeline latency,
provided it's consistent gate-to-gate.

### 2.5 Caveat: the Core 0 measurement predates the current detector

The Core 0 headroom measurement in §2.2 was taken against the firmware *as
it stood before* the dual-EMA detector existed — Core 0 carried no
app-level task at all at that time. That's no longer true:
`beam-sensor.h`'s `beamSampleTask` now runs pinned to Core 0
(`xTaskCreatePinnedToCore(beamSampleTask, ..., 0)` in `main.cpp`), woken by
a 1 kHz hardware timer. If Option A is ever revisited, **re-profile Core 0
headroom rather than relying on the numbers above** — they no longer
reflect an empty Core 0.

## 3. Recommendation

Both architectures are plausible; Option B (secondary processor) is the
lower-risk one against hesperus's existing, already-validated architecture,
since it requires zero changes to the ISR/timestamp/sync path that took
real effort to get right. Option A (single-chip) is viable too, but needs
Core 0 headroom re-measured on current firmware (§2.5) and ADC1's max
aggregate continuous rate confirmed against the TRM before the task/core
placement question can be answered with confidence.

This is a feasibility read, not an implementation plan. The next step, if
pursued, would be deciding between the two architectures (or scoping
further investigation, e.g. re-profiling Core 0) before any code is written.

## Appendix: per-core responsibility breakdown (at time of this assessment)

For reference, what the assessment above was reasoning about — this
describes the firmware *before* `beam-sensor.h` existed and is not a
current-state description; see `detection-mechanism.md` for that.

**Core 1 — everything the app explicitly created:**
- `TsfCapture` (priority 3, highest in the app) — consumed
  `triggerCaptureQueue` from the ISRs, did the ISR-unsafe
  `esp_wifi_get_tsf_time()` read, assembled the `GateEvent`, pushed to
  `networkQueue`. The task whose scheduling latency the cross-gate sync
  accuracy depends on.
- `WsPump` (priority 2) — sole owner of `wsClient.loop()`.
- `UploadWorker` (priority 2) — consumed `networkQueue`, ran the HTTP/WS
  ack-wait/retry dispatch logic.
- `LED_Task` (priority 1) — consumed `ledQueue`, drove the NeoPixel status
  feedback.
- Arduino's own `loopTask` — also Core 1 by the Arduino-ESP32 default
  (moderate confidence; no explicit `ARDUINO_RUNNING_CORE`/unicore override
  found to confirm this rather than infer it).

**Core 0 — nothing app-level** at the time of this assessment. Presumed to
carry ESP-IDF's own Wi-Fi/lwIP (and possibly BT) housekeeping tasks per
Arduino-ESP32/IDF defaults (inferred from general platform behavior, not an
explicit project setting) — this is exactly what the idle-hit profiling in
§2.2 measured. It now also carries `beamSampleTask` (§2.5).

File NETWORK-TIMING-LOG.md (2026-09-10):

# Network Timing Issue: Observations, Resolutions, and Outstanding Work

Date: 2026-07-30. Restructured 2026-07-31 — see "Restructuring note" at the
bottom for what changed and why.

**What this document is, 2026-08-07.** A chronological investigation log
(lab notebook), not a live issue tracker — dated, session-by-session
findings and decisions from bench-testing the gate/controller network
stack. Entries are historical record: when a later session supersedes an
earlier claim, the old text is struck through and annotated rather than
silently rewritten, so the document stays an honest account of how
understanding changed over time. Because of that, don't treat an
`[OPEN]`/`[RESOLVED]`/`[Reassessed ...]` tag as necessarily *current*
without checking its date against anything later in the same section —
staleness here is a known failure mode, not a hypothetical one (several
tags and cross-references in this doc have been found stale and corrected
after the fact). For genuinely current open work, see `TODO.md`. New bugs
or feature requests going forward are tracked as GitHub Issues, not added
here — this document's job going forward is to stay a record of what was
investigated and found, not a live status board.

## Context

`hesperus-timing-gate` boards report race events (`ARM`, `START`, `GOAL`) to
`cerberus-gate-controller`, with disciplined Wi-Fi-TSF-based microsecond
timestamps carried in the payload. Transport was originally per-event HTTP
(`POST /api/event`); a persistent WebSocket connection (`/ws`) was added
during this investigation and is now the default (see the first issue
below). Bench testing the two boards together (a start board and a goal
board, both clients of a single cerberus controller) surfaced a chain of
related issues in network latency, its effect on displayed race times, and
its effect on race-result correctness. This document records what was
found, why it happens, what's been done about it, and what's still open.

Bench-testing tools referenced throughout (`ares-pulse-generator`'s
`trial_*` functions, `ws_send_event.py`, `cerberus_log_stats.py`, etc.) are
catalogued in `docs/TEST-TOOLING.md` — that doc covers what each tool does
and how to invoke it; this doc only references them by name.

## Acceptance criteria for beacon-spam stress testing

Decided 2026-08-03, after three stress-test sessions (see the beacon-spam
issues below): any lost timing event is a broken system by acceptance-testing
standards, but demanding that in *every conceivable* radio environment isn't
realistic — a pass/fail line has to be drawn somewhere, and where matters
because the stress-test protocol (15 runs no spammer, 15 with one spammer,
then a second spammer added) exercises two very different threat levels in
one script:

- **One beacon spammer is extreme, but not adversarial.** The tool itself is
  nominally an attack device, but the load one produces is plausibly in the
  same range a busy exhibition hall's own ordinary infrastructure could
  generate organically (dozens of exhibitor/vendor APs each beaconing at the
  standard rate — see the SSID-density estimate under the outstanding-work
  item below). It's a severe environment, not a hostile one: nothing about
  it requires a deliberate actor. **This is the pass/fail bar.**
- **Two simultaneous spammers (~1000 beacon frames/sec combined) is
  adversarial** — that combination of severity *and* deliberate placement
  (both devices parked right next to the gate at full signal strength) is
  well beyond what a venue's own organic traffic would reproduce; it
  requires someone deliberately trying to disrupt the system. Every radio on
  the channel still has to process each beacon frame at the hardware/MAC
  level regardless of payload, which is why it hits the ESP32's software
  WiFi stack disproportionately hard (see the `wsClient.loop()`-blocking
  issue below) even though a laptop on the same air noticed nothing. Treated
  as a **smoke test** (does the system degrade gracefully and recover
  automatically, without crashing or corrupting a result) rather than a
  pass/fail gate — zero-loss under deliberate, sustained ~1000fps beacon
  flooding is not a requirement.

**Single-spammer result so far: passes cleanly.** Isolating each stress
session's no-spammer + single-spammer phase (everything before the first
`Resent` line, which lines up almost exactly with the 15+15-run protocol)
and checking committed vs. armed+started: session 3, 29/30 (the one gap is
the session's very first run, a cold-start artifact, not spammer-induced);
session 4, 31/31; session 5, 29/30 (the one gap is the *last* run before
cutoff, whose `GOAL` landed 131ms after the first `Resent` — caught by the
onset of the second spammer, not a failure during clean single-spammer
running). **Zero genuine single-spammer losses across all three
independent sessions** once the cold-start and cutoff-boundary artifacts are
excluded. This held both before and after the 2026-08-03 retry-schedule
mitigation (session 5's session-3-era predecessor already passed too) — the
retry/deadline logic never even engages during single-spammer running (no
`Resent` lines appear until the second spammer goes on), so that mitigation
is aimed entirely at the smoke-test scenario, not the pass bar.

**Practical implication**: further tuning effort aimed specifically at the
two-spammer case (chasing its ~2-3% residual loss, or side-effects like the
`networkQueue`/`ledQueue` overflow seen in session 5) is lower priority than
confirming single-spammer robustness more rigorously — larger sample sizes,
and the more realistic congested-airtime conditions sketched in outstanding-
work item 5 below, rather than continuing to optimize against a scenario
this system isn't required to survive losslessly.

**Large-N no-spammer baseline, 2026-08-03** (`test-data/spam-tests/
{cerberus-6,hesperus-start-6,hesperus-goal-6}.log`, 5000-run trial, no
spammer — the first of a planned pair, single-spammer counterpart still to
come): **5000/5000 ARM, START, and GOAL, zero retries, zero drops, zero
queue overflow, one single WS disconnect/reconnect across the entire
~6-hour test.** A perfect result, as expected for the no-spammer condition,
and a clean baseline to compare the equivalent single-spammer 5000-run trial
against once it's run. (Session did produce one unrelated curiosity ~64-84
minutes after the last logged race, well outside the trial itself — see the
"AP radio interruption" issue's 2026-08-03 addendum below.)

**Planned next steps, 2026-08-03.** The AP has been deliberately placed some
distance from the gates for this round of testing — typical reported `rssi`
sits around -70 to -80dBm, a genuinely weak-to-marginal link (rough rule of
thumb: -50 to -60dBm is good, -60 to -70 usable, -70 to -80 is where 802.11
MAC-layer retransmission rates start climbing on their own, independent of
any beacon-storm software overhead). `rssi` is already carried in every
event payload, so no new instrumentation is needed:

1. Once the current single-spammer 5000-run trial (session 6's counterpart)
   finishes, cross-reference retry/drop occurrences against the `rssi`
   values of the events involved, to check whether failures cluster at the
   low end of the -70/-80dBm range (pointing at marginal signal margin as a
   contributing factor) or look independent of it (supporting the
   beacon-frame-count-overhead theory on its own, per the `wsClient.loop()`
   issue above).
   - **Unconfirmed hunch to check alongside this**: the user suspects their
     own physical position near the test rig during the first ~1000 or so
     runs may itself have been attenuating `rssi` (body blocking
     line-of-sight to the AP), an effect that would fade once they stepped
     away for the remainder of the multi-hour unattended run. Flagged as
     possibly fanciful, not asserted — the way to check it is the plot
     below, not assumption.
   - **Known extra confound, same window**: for this specific trial, the
     user's own BT headphones were also streaming audio within a couple of
     feet of the rig during roughly that same first ~1000 runs, on top of
     the body-proximity hunch above. Mechanistically different from the
     beacon-spam issue this doc otherwise tracks — BT interference would
     show up as ordinary co-channel RF collision/corruption (raised noise
     floor, standard 802.11 MAC retransmissions), not the CPU/management-
     frame-processing overhead the beacon-storm issues are about — so if the
     first ~1000 runs do look worse, it's confounded between body position
     and BT and not attributable to either alone. The following ~2 hours of
     the same trial should be free of both. Noted for the record because
     good experiment hygiene means tracking every condition in play, even
     ones that turn out not to matter.
   - **Curiosity plot, not a formal requirement**: average `rssi` vs. time
     (or run index) across the trial, per board, to see whether there's a
     visible early-run dip/trend consistent with the hunch above, independent
     of the retry/drop correlation in point 1.
2. Afterwards, the AP will be moved to give an `rssi` more representative of
   the planned deployment environment, and the **exact same trial protocol
   re-run** for a direct comparison against the current (deliberately weak
   signal) baseline.

**Results, session 7 (2026-08-03)** — from the single-spammer 5000-run trial
before it was cut short by the ISR/TSF crash bug above (~2882 armed+started
runs completed, 2881 committed, only 1 true loss — see that issue for the
crash itself):

- **RSSI level does not predict retries.** Joining each hesperus-side send
  record to its cerberus-side `rssi` (ordered join per board/event-type,
  tolerant of the one dropped `GOAL`): mean `rssi` for events that needed a
  retry is statistically indistinguishable from events that didn't (ARM:
  -74.9 vs -75.0dBm; START: -75.3 vs -75.0; GOAL: -72.8 vs -73.0). Within
  the -66 to -82dBm range actually seen, `rssi` level itself isn't
  predictive of which specific events fail.
- **Time is a much stronger predictor.** Binning retries by run index:
  ARM retries ran 2.75% in runs 0-800 vs. 0.14% in runs 800-3000 (~20x
  lower); GOAL retries ran 4.5% vs. 0.55% (~8x lower). Essentially all
  retry activity — and the one genuine drop, at run 252 (~20.6 minutes in)
  — falls inside the first ~800-1000 runs (~1-1.2 hours), matching the
  body-position/BT-headphones confound window flagged before this trial.
  The remaining ~2000 runs were close to flawless.
- **This actually points more at the BT headphones specifically than body
  position.** Average `rssi` stayed flat through the early window (no dip)
  — `rssi` measures the WiFi AP signal's own strength, not ambient
  interference, so a body attenuating line-of-sight *would* show up as
  reduced `rssi`; BT co-channel interference degrades packet success
  *without* touching the `rssi` reading at all. Retries elevated with
  `rssi` flat fits "something interfering" better than "something
  attenuating." Not proven (no confound-free control run to compare
  against directly), but a coherent, self-consistent reading of the data.
- Curiosity plot (average `rssi` vs. run index) done as part of the above
  rather than as a separate artifact — see the binned figures; no visible
  early-run dip, per the point above.

**Results, session 8 (2026-08-04)** — the AP-repositioned, confound-free
single-spammer 5000-run trial planned above
(`test-data/spam-tests/{cerberus-8,hesperus-start-8,hesperus-goal-8}.log`),
run to completion (no crash cutoff this time):

- **ISR/TSF crash fix hardware-verified.** Zero panics, zero reboots, on
  both boards, across the full ~6.53-hour, ~5346-run trial under the same
  sustained single-spammer load that surfaced the bug in session 7. See the
  issue below — now marked resolved.
- **Realistic-deployment RSSI, as intended.** Mean `rssi` -65.8dBm (range
  -56 to -76dBm), a clear improvement over session 7's deliberately-weak
  -66 to -82dBm/mean ~-75dBm baseline, confirming the AP repositioning
  worked.
- **Retries near-zero, and — the key check — no longer front-loaded.** Only
  5 distinct events needed a retry out of 16,034 total (0.03%), identified
  via cerberus-side duplicate receipts of the same `tsf_us`. Binned across
  the full trial: **zero retries in the first ~2 hours**, the few that
  occurred fall in hours ~2-4.4, none after. This is the confound-free
  control session 7 lacked: with the body-position/BT-headphones confound
  genuinely absent this time, retries do not show the ~20x/~8x early-window
  spike session 7 saw — supporting the session-7 reading that that spike
  was confound-driven, not RSSI- or time-of-trial-driven. RSSI level still
  isn't predictive of which events retry (e.g. ARM: -67.0dBm retried vs.
  -66.8dBm clean, statistically indistinguishable).
- **Item 1 (ack-path) recurred once, same signature as before.** A burst at
  T≈14.09-14.13M ms: three ARM events needed retries within a 40-second
  window, one needing 9 attempts before succeeding. Cerberus's `[WS-ACK]`
  fired within 3-8ms on every single delivery (again ruling out "cerberus
  is slow"), yet hesperus didn't recognise the ack in time — consistent
  with item 1's still-open two candidate causes, not yet distinguished
  further by this session.
- **Race outcome, once one operator-caused artifact is excluded (confirmed
  with the user, see below): effectively lossless.** Start board
  armed+started 5346 runs; cerberus received 5345 of the ARM+START pairs
  over the network (the one gap lines up exactly with the artifact below);
  goal board sent 5344 GOALs (2 runs left incomplete by the same artifact),
  and cerberus received all 5344 of them — **zero GOAL-side network loss**.
- **Explained anomaly, not a bug.** At T≈2.6M ms (~43 minutes in), both
  hesperus boards and cerberus went completely silent simultaneously for
  ~8.7 minutes (no sends, no receipts, no crash/reboot/disconnect logged by
  any of the three) before resuming cleanly — 2 runs left incomplete (armed
  and started, no GOAL), one of which also never reached cerberus at all.
  **Confirmed with the user**: this was a deliberate mid-trial adjustment,
  with the log not reset before resuming — which also explains the run
  count landing at ~5346 rather than the nominal 5000. Excluded as an
  operator artifact, same treatment as the cold-start/cutoff artifacts
  excluded in sessions 3-5; not a system fault. One of the goal board's
  `[AUDIT ALERT] Temporal Disruption!` self-corrections (see the "AP radio
  interruption" issue's recurrence note) lands at the exact resume instant
  and is fully explained by it (a large TSF gap after 8+ minutes without a
  fresh sample). The other 6 (5 goal-board, 1 start-board) occur during
  otherwise-normal running with no nearby gap — each a single rejected
  sample, immediately self-corrected, no operational impact — extending the
  session-6 recurrence note: this now happens during active running too,
  not just post-trial idle. Still unexplained, still low-priority and
  self-healing.

## Outstanding work, prioritized

1. **[Acks not arriving back at hesperus in time](#issue-acks-not-arriving-back-at-hesperus-in-time-despite-cerberus-receiving-the-event)**
   — **[RESOLVED, tuning applied 2026-08-04, not yet hardware-verified.]**
   End-to-end instrumentation on both boards (cerberus's `pending`/`space`,
   hesperus's `[WS-ACK-RECV]` receive timestamp, both on the shared TSF
   clock) traced all 10 retried events in a two-spammer+BT marginal trial
   start to finish: **every one of them was the original ack arriving
   fine, just with a round trip (258-458ms) that happened to exceed
   hesperus's fixed ~300ms per-attempt timeout.** Not loss, not a stack
   stall on either side (ruled out via `wsPumpTask`'s own blocking canary,
   which fired only once in the whole trial and didn't line up with any of
   the 10), not asymmetric (both legs contribute comparably) — ordinary
   bidirectional jitter under heavy interference, occasionally summing
   past a fixed timeout, most likely at the WiFi MAC layer itself given
   both boards' software was cleared. Retry/dedup already handled it
   correctly throughout (zero data loss in any session this showed up in),
   and it only ever appeared under the explicitly-adversarial two-spammer
   smoke test, not the single-spammer pass bar (0.03% retry rate there).
   **`WS_ACK_TIMEOUT_MS` raised 300→500ms** (jitter and
   `WS_ACK_OVERALL_DEADLINE_MS` scaled proportionally alongside it, so
   `WS_MAX_SEND_ATTEMPTS`'s retry depth for genuine loss isn't quietly
   reduced) rather than the previously-considered redundant-ack-burst
   mitigation, which was built around a loss model this data doesn't
   support. Build-verified; next step is a session-9/10-style marginal
   trial confirming the retry count drops **under `NONE`** — session 13
   (2026-08-05) ran the harsher two-spammer+BT combination but under
   `MIN_MODEM`, so it doesn't isolate this fix cleanly (see item 2); the
   forward-leg delivery held up well there regardless (every genuinely
   transmitted event eventually reached cerberus), which is a good sign
   but not the controlled re-run this item still needs. **Session 15**
   (2026-08-06) attempted this under `NONE` but one spammer dropped out
   ~30 minutes in (equipment issue, not a finding) — both segments'
   retry rates looked healthy, but it's suggestive, not the clean
   confirmation this item needs. **Session 15a** (2026-08-06, the planned
   3000-run re-run) was *also* compromised — BT was found off partway
   through, back on at a known timestamp — but showed sustained stress
   throughout regardless, with overall retry rates (1.46%/9.47%) well
   under session 13's `MIN_MODEM` baseline (4.0%/18.3%) over a comparable
   exposure. Two compromised trials in a row is enough supportive signal
   to lower this item's urgency, but a genuinely clean confound-free run
   still hasn't happened. **Session 16 (2026-08-07) is that clean run**:
   full 5000-run, ~5.97h two-spammer+BT trial under `NONE`, both spammers
   and BT confirmed continuous throughout, no equipment confound. Retry
   rates 4.15%/10.32% (ARM/START vs. GOAL) — of the 923 events that needed
   at least one retry, only 8 exhausted all retries (99.1% recovered).
   **Confirms the fix**: the widened timeout is doing real work under
   sustained real adversarial load, not just the shorter/compromised
   trials this item was leaning on before. Full per-event round-trip
   tracing (the session 9/10-style breakdown showing *why* each retry
   happened) wasn't repeated for this session — the aggregate recovery
   rate is the evidence here, not a re-derivation of the mechanism, which
   sessions 9/10 already established. Full detail in the issue below.
2. **[Wi-Fi power-save vs. battery budget](#issue-wi-fi-power-save-vs-battery-budget)**
   — Measure current draw across `WIFI_PS_NONE`/`MIN_MODEM`/`MAX_MODEM`
   with persistent connections in place. Real, measured 110mA cost today;
   the thing this was explicitly deferred pending (persistent connections)
   has now landed, so this is unblocked. **Decision, 2026-08-04: `NONE`
   stays the shipped default regardless of what the overnight trial
   below shows.** Session 11 found a real, if not-yet-fully-explained,
   `MIN_MODEM` reliability regression (see the issue below); a clean
   overnight repeat wouldn't be enough to overturn that — absence of a
   recurrence in one more trial is not evidence of absence of a rare tail
   risk, and the asymmetry between "run `NONE` at higher power
   indefinitely" and "have an outage during a real contest" clearly favours
   caution. The overnight trial is now diagnostic-only (does the mechanism
   recur, at what rate), not a pass/fail gate for adoption — `MIN_MODEM`
   would need to be root-caused, fixed, and *then* re-verified extensively
   before this decision would be revisited. **Update, 2026-08-05**: session
   12 (single-spammer repeat) showed zero recurrence; session 13
   (two-spammer+BT smoke test) showed the mechanism recurring twice in one
   trial — occurrence count now tracks stress severity directly (0/1/2
   across sessions 12/11/13), which is itself evidence for a genuine
   mechanism rather than coincidence. **Update, same day**: the candidate
   fix (widen `enableHeartbeat()`'s pong-timeout/miss-count) was applied
   and tested (session 14) — it made every measure dramatically worse
   (drops, stalls, disconnects, stale-GOALs, retry rates all 2-136x worse
   per hour than session 13's unmodified baseline), not better. Reverted.
   The mechanism remains unexplained and unmitigated; this specific
   direction (widen tolerance) is now ruled out, not just untried — any
   future attempt needs a different theory of the failure. **Update,
   2026-08-06**: session 15 (`NONE`, same nominal two-spammer+BT stress)
   compromised by a spammer dropping out ~30 minutes in, but the ~30
   minutes of genuine exposure it did get showed no stall approaching the
   5000ms signature that defines the `MIN_MODEM` mechanism — suggestive
   that it's `MIN_MODEM`-specific, on weaker evidence (30min vs. 6h) than
   the recurrence finding it's being weighed against. **Revised, same
   day**: session 15a (the planned clean re-run, also compromised — BT
   found off partway through) recorded one genuine **5002ms** stall under
   `NONE` during its confirmed-no-BT period, hitting the exact
   `WEBSOCKETS_TCP_TIMEOUT` signature. **The severe cascade is not
   `MIN_MODEM`-exclusive after all** — it's a general two-spammer
   WiFi-stack-overhead property `NONE` isn't immune to, just apparently
   less frequent/severe under it (one occurrence in ~3.6h vs. repeated
   occurrences per `MIN_MODEM` trial) rather than absent. Both `NONE`
   trials to date have been confound-compromised; a genuinely clean run
   under either power mode still hasn't happened. **Session 16
   (2026-08-07) is that clean run for `NONE`**: full 5000-run, ~5.97h
   two-spammer+BT trial, both interference sources confirmed continuous
   throughout. **The 5002ms signature is not rare under `NONE` either**
   — 25 of ~~158~~ **79** (see raw-log recount, 2026-08-07, in the issue
   detail below — the 158 figure's source wasn't identified) total stalls
   landed in the 4900-5100ms band across the trial, ~~spread throughout
   rather than clustered in one window (unlike `MIN_MODEM`'s acute
   2-minute/14-15s episodes in sessions 11/13)~~ **actually clustered: ~85%
   of the large stalls fall inside one ~9.7-minute episode at the very
   start of the trial, comparable in kind to `MIN_MODEM`'s acute episodes
   just front-loaded rather than mid-run — see the corrected finding
   below.** 34 WS disconnects total (confirmed correct). Despite that,
   race outcome was 4940
   armed+started, 4911 committed (29 lost, 0.59%) — no crash, no reboot,
   no corrupted result, fully automatic recovery every time. **This is a
   clean pass of the smoke-test bar this trial was always held to**
   ("degrades gracefully and recovers automatically" — not zero-loss,
   see the acceptance-criteria section above) — the first genuinely
   confound-free confirmation that `NONE` survives the harshest tested
   condition without manual intervention. Does not overturn the
   `MIN_MODEM`-stays-unadopted decision (that was never contingent on
   `NONE`'s own smoke-test result) — it closes out the parallel question
   of whether `NONE` itself has ever been cleanly verified under this
   condition. It hadn't been; now it has.
3. **[`wsClient.loop()` blocking under congestion](#issue-wsclientloop-blocking-under-congestion-defeats-the-ackretry-deadline-bound)**
   — confirmed via instrumentation + cross-board log correlation: beacon
   spam causes real TCP-level WS disconnects (up to ~18s outages seen) on
   the hesperus side, with `wsClient.loop()` blocking up to ~9.5s per call,
   silently blowing the 2000ms ack/retry deadline bound. Not classic
   airtime saturation (a laptop held 25Mbps through the same spam) —
   likely ESP32-specific WiFi-stack overhead from beacon-frame volume.
   Undermined the already-shipped retry/dedup mechanism precisely under the
   real-world congestion it exists for. **Resolved and hardware-verified
   2026-08-03** (dedicated `wsPumpTask` + mutexes decouple the socket pump
   from the retry deadline logic) — 5/6 verification deltas landed within
   ~500ms of the 2000ms target, down from the original bug's 7.6s+
   untethered stalls. The two residual outliers are now tracked as item 1
   above, not here. Root RF-level cause (why the outages happen at all)
   remains open too, folded into item 5 below. **Proposed experiment,
   2026-08-07 (not yet run)**: session 16's raw-log recount found the
   severe stalls cluster into episodes rather than spreading evenly, with
   the fastest-onset episodes landing suspiciously close to trial start —
   but not in every session. A cheap two-trial pair (~75min total) is
   designed to isolate whether traffic-onset or connection-freshness (both
   normally coincide at trial start) is the actual trigger — see the
   dedicated write-up at the end of the issue below.
4. **[Duplicate triggers from gapped robot structure](#issue-duplicate-triggers-from-gapped-robot-structure)**
   — **[Reassessed 2026-08-07 — deprioritized, lock-out design not being
   pursued.]** The proposal's own justification (needless network pressure
   from extra events) was written under HTTP's per-event connection cost;
   this issue's own WS re-run data (200/200 arrived, ~7-8ms latency, the
   104ms queueing offset gone) already shows that premise doesn't hold
   anymore. Multiple triggers from one robot are rare in practice, and
   under WS a redundant trigger costs almost nothing to send and is already
   harmlessly ignored once out of `RUNNING` — if anything, sending
   duplicates is closer to a reliability feature (a free extra delivery
   attempt) than a problem worth suppressing at the source. Not formally
   closed (a genuinely gapped robot could still exist), just no longer the
   standing design question it was.
5. **Congested-airtime stress testing** (cross-cutting, not tied to one
   issue) — **[Judged sufficient, 2026-08-04 — deprioritized, not
   formally closed.]** The four stressor layers sketched in
   `hesperus-timing-gate/docs/review.md`: **airtime saturation** has extensive
   coverage (beacon-spam sessions 2-10, up to two simultaneous spammers)
   and **channel interference** partial coverage (BT streaming co-tested
   alongside spammers, sessions 9-10); **bulk throughput contention** and
   **broadband noise** remain genuinely untested. Decision: given the
   system handled the harshest combination actually tested (two spammers +
   BT streaming, deliberately parked next to the gate) with zero drops,
   zero crashes, and the one real issue that surfaced (the ack-path
   timeout mismatch) understood and fixed, further chasing the two
   untested layers is diminishing returns relative to what a real contest
   venue is actually likely to produce — other exhibitors' AP
   beacon/management-frame overhead, not deliberate bulk-throughput
   hogging or broadband jamming. Not pursuing further unless a specific
   venue's known conditions give a concrete reason to.
6. **[Hedged burst sends](#issue-hedged-burst-sends-for-tail-latency)** —
   deprioritized; watch real-world retry counts/rate from the now-shipped
   ack/retry mechanism before building this. No action needed unless that
   telemetry shows frequent retries.
7. **[Unexplained minor WS jitter / reconnect blip](#issue-unexplained-minor-ws-jitter--reconnect-blip)**
   — **[Characterized and closed, 2026-08-04 — no periodic cause found.]**
   Rather than running the proposed purpose-built 10,000-message GOAL-only
   trial, used the existing confound-free 5000-run no-spammer baseline
   (session 6, `test-data/spam-tests/cerberus-6.log`) instead — 5000 real
   `GOAL` events at a uniform ~4.3s cadence, arguably a better substitute
   than the synthetic proposal since it's real protocol traffic, not
   synthetic pulses, and 5000 comfortably exceeds the proposed 10,000
   *messages* once ARM/START are counted too (this pass used `GOAL` alone
   to match the original single-event-type proposal). Latency: mean 8.8ms,
   p90 12.0ms, p95 14.6ms, p99 19.0ms, max 63.8ms; 30/5000 (0.6%) exceeded
   20ms. Checked those 30 outliers' index spacing for periodicity (the
   original leading hypothesis — "a spike every N messages, pointing at a
   fixed-period task like the heartbeat timer or a WS keepalive interval")
   — spacing is irregular (1 to 697 events apart, no repeating interval),
   ruling that out across a sample 25-50x larger than the n=100-200 that
   originally flagged this. Consistent with ordinary non-periodic
   scheduling/RF jitter, not a hidden periodic bug. The original issue's
   own caveat ("would not on its own isolate which stage the delay happens
   in") is now moot rather than resolved — sessions 8-10's ack-path work
   has since added exactly the hesperus-side send/receive timestamp this
   would have needed as a follow-up, but with no pattern found there's
   nothing left to isolate. Closed as characterized-and-benign; watch for
   recurrence rather than investigate further.
8. **[GOAL board retries far more than ARM/START board under heavy
   stress](#issue-goal-board-retries-far-more-than-armstart-board-under-heavy-stress)**
   — **[OPEN, deferred 2026-08-05]** Session 13's two-spammer+BT smoke
   test showed the GOAL board retrying 4.6x more often than the ARM/START
   board (18.3% vs. 4.0%). Cause not yet distinguished between physical
   placement and role/traffic-pattern. The planned start/goal position
   swap is deferred to the production-board testing stage — the current
   hand-wired breadboard rig has too many uncontrolled physical variables
   for a swap result to be trustworthy.

Everything else below this list is either resolved or has no further action
planned. (Explicit HTTP connect/read timeouts, formerly tracked here, turned
out to be N/A rather than just deprioritized — see the first issue below.)

## Issues

### Issue: Per-event connection latency & queueing

**[RESOLVED — persistent WebSocket connections shipped; the one remaining recommendation (explicit HTTP timeouts) is now N/A, see below]**
*(was Observations #1, #2, #3, #8; Recommendation 1, Recommendation 3)*

**Observation.** Every trigger initially produced exactly four identical
`POST /api/event` requests at cerberus, matching `MAX_HTTP_RETRIES`
precisely. Root cause: `HTTP_TIMEOUT_MS` was set to 250ms, which the real
round-trip time consistently exceeded — hesperus exhausted all four retry
attempts on every single event, even though cerberus was receiving and
correctly processing every one of them. Raising `HTTP_TIMEOUT_MS` to 2000ms
initially resolved the duplicate-POST pattern, but didn't fully explain
later data: a "confirmed" event was observed taking 2993ms — longer than
the configured 2000ms timeout, yet still succeeding. Inspecting the ESP32
Arduino `HTTPClient` source
(`framework-arduinoespressif32/libraries/HTTPClient/src/HTTPClient.cpp`)
showed why: `HTTPClient::setTimeout()` only sets `_tcpTimeout`, the
**response-read** timeout, applied only *after* a TCP connection is already
established. The TCP **connect** phase uses a separate `_connectTimeout`,
defaulting to a hardcoded `HTTPCLIENT_DEFAULT_TCP_TIMEOUT = 5000`
(`HTTPClient.h:42`) that nothing in the firmware had ever configured — so
tuning `HTTP_TIMEOUT_MS` never bounded the dominant source of latency at
all.

Both boards were given TSF-based (`esp_wifi_get_tsf_time(WIFI_IF_STA)/1000`)
millisecond timestamps on every debug log line — hesperus and cerberus are
both stations on the same AP, so this is a shared, sub-ms-precision clock
across boards, letting logs from each be correlated directly.
`tsf_us` (captured in hesperus's ISR at the instant of the physical
trigger) against cerberus's own logged receipt time gives the true one-way
"trigger → cerberus received" latency, independent of the return trip:

| Event | One-way (trigger → received) | Full round trip (hesperus-measured) | Implied return leg |
|---|---|---|---|
| GOAL | ~132ms | 146ms | ~14ms |
| START | ~270ms | 284ms | ~14ms |
| ARM | ~267ms | 285ms | ~18ms |

Outliers of 856ms (first-ever connection in a session) and ~2.9s (later in
the same session) were also observed on single attempts that still returned
`httpCode == 200` — consistent with TCP connect-phase trouble (e.g. a lost
SYN packet triggering the underlying stack's own retransmission).
**Conclusion: essentially all latency, and effectively all of its
variance, is attributable to TCP connection establishment**, paid fresh on
every single event, since no connection reuse/keep-alive existed
(`http.begin()`/`http.end()` opened and closed a new connection each time).
Cerberus's own processing (JSON parse, dispatch, queue, respond) is fast
and consistent — the ~14-18ms return leg above — and was never a meaningful
contributor.

Separately, at higher trigger rates, a second effect compounds the first:
two bench tests isolated a queueing theory directly, using the same
`receipt_ms*1000 − tsf_us` method against a rapid sequence of real `GOAL`
triggers. **Test A — rapid-fire triggering (~88 events, spacing mostly
60-800ms):** one-way latency ramped smoothly from ~110ms up to 2773ms over
each ~8s burst, resetting back down whenever a multi-second pause let the
backlog drain. Latency growth per event correlated directly with
inter-trigger spacing: gaps under ~130ms added ~140-190ms of extra latency
each; gaps over ~250ms let latency drain instead of growing. This is a
queueing signature, not network jitter or clock drift (hesperus's own
`tsf_observed` and `processor_clock` tracked each other to within tens of
microseconds throughout). The mechanism: `uploadWorkerTask`
(`hesperus-timing-gate/src/main.cpp:238`) drains `networkQueue` one event at
a time, and each full connect+POST+confirm cycle costs ~230-270ms (matching
the baseline above exactly) — triggers arriving faster than that queue up
and each waits longer than the last for its turn. **Test B — control, same
trigger source, ~1-2s spacing (~87 events):** mean 234.6ms, median 259.5ms,
p90 319ms, p95 345ms, stdev 102ms. Only one outlier, 818.8ms — the very
first request of the session (cold connection). This confirmed Test A's
spike was purely a by-product of sustained rapid-fire triggering outrunning
hesperus's one-event-at-a-time send cycle, not a new or separate network
problem.

**Confirmation.** `networkQueue` is only 10 deep
(`hesperus-timing-gate/src/main.cpp:452`). At a ~250ms service time, a
sustained trigger rate faster than that for more than ~2.5s overflows it —
silently dropping events, not just delaying them. `ares-pulse-generator`'s
`trial_burst` fired 40 `GOAL` pulses at a fixed, known 90ms interval (raw
data in `test-data/trial-burst-20260630-1542*.txt`); only 24 reached
cerberus. The other 16 are independently confirmed dropped two ways at
once: hesperus's own serial log showed `[QUEUE OVERFLOW] N networkQueue
event(s) dropped.` lines summing to exactly 16, and cerberus's received
events show gaps of 180ms/270ms (2x/3x the 90ms send interval) exactly
where pulses are missing. The first ~15-16 pulses got through with no drops
at all, at a clean, unbroken 90ms spacing — but their latency climbed the
whole time, from 272ms to 2726ms, the same ramp signature as Test A. Once
saturated, latency flattened at ~2700-2770ms instead of growing further.
This was no longer an inferred risk: at realistic burst rates, the firmware
was silently losing race events.

**Resolution.** **Persistent connection per gate board (highest leverage),
implemented and merged.** Open one WebSocket connection per hesperus board
once it becomes ready (Wi-Fi connected + cerberus discovered), and hold it
open across all subsequent trigger events instead of opening/closing per
event — eliminates the repeated TCP-handshake cost for every event after
the first. Compatible with Wi-Fi modem sleep: TCP session state persists
across the radio's sleep/wake cycles since they operate at different
layers; only the first transmission after a sleep period pays a smaller,
bounded radio wake-up cost instead of a full handshake (relevant to the
power-save issue below). Two design details settled during implementation:

- **A held-open connection alone does not give rapid failure detection** —
  if the peer silently disappears (power loss, Wi-Fi drop with no clean
  FIN/RST) while the socket is idle, plain TCP has no built-in way to
  notice. A WebSocket gives proactive detection for free via its ping/pong
  control frames and library-level disconnect callbacks
  (`AsyncWebSocket::onDisconnect`), rather than needing hand-built
  keepalive/timeout logic.
- **The gate remains the connection initiator**, matching the existing
  client/server roles and mDNS discovery direction (gate resolves
  `cerberus.local`; cerberus has no equivalent way to discover a gate).
  Who initiates doesn't restrict data direction afterward — a WebSocket is
  full-duplex once established regardless of who dialed.

WebSocket was chosen over a bare kept-open TCP/HTTP socket specifically
because the ping/pong-and-disconnect-detection property comes essentially
free with a library on both ends, `ESPAsyncWebServer` (already a cerberus
dependency) includes `AsyncWebSocket` with no new library needed
server-side, message framing is native, and the existing dispatch logic
(`race_command_from_http()` / JSON schema) didn't need to change at all —
only the transport underneath moved. Honest cost: hesperus had no
WebSocket *client* before this (added `Links2004/arduinoWebSockets`), and a
WS connection still needs an initial HTTP-upgrade handshake, so there's
still a first-connection cost, just paid once per board instead of once per
event.

**N/A (was "Still open")**: the recommendation to configure `HTTPClient`
timeouts explicitly (`http.setConnectTimeout()`, alongside `http.setTimeout()`)
was never implemented, and now never will be — hesperus's runtime code no
longer constructs an `HTTPClient` object at all (verified: `main.cpp` only
mentions it in a historical comment). The WS client library
(`WebSocketsClient`) handles the persistent connection instead, with its own
timeout/heartbeat config (`enableHeartbeat()`), unrelated to `HTTPClient`'s
settings. The two proposed characterization experiments (isolating
connect-phase latency with temporary `WiFiClient::connect()` instrumentation;
injecting packet loss via Linux `netem`) are moot for the same reason — both
targeted the old per-event HTTP connect phase, which no longer exists.

**Verification.** Bench-measured WS latency settled at ~5-12ms typical
(a one-time ~1.1s first-connection warm-up on an early run didn't recur
later), against ~115-560ms for HTTP comparison runs — beat the original
~15-30ms prediction. `trial_burst` re-run under WS (raw data in
`test-data/trial-burst-ws-20260630-1036.txt`): all 40/40 pulses reached
cerberus, zero drops, no `[QUEUE OVERFLOW]` lines. Latency: mean 8.7ms,
median 8.2ms, stdev 2.7ms, min 5.2ms, max 18.2ms, p99 18.2ms — flat
throughout, no climbing/ramp signature. Confirms the mechanism directly:
the persistent connection eliminates the ~250-270ms per-event
connect+POST+confirm service time that was the actual bottleneck, so the
depth-10 `networkQueue` never comes close to saturating at this rate.
Reconnect-after-Wi-Fi-drop and reconnect-after-cerberus-reboot are both
bench-confirmed working (self-healing, no manual intervention needed).
Both physical hesperus test boards flashed and running WS successfully;
the other 3 hesperus board envs share the same firmware so didn't need
separate testing. See also the ARM/START and double-trigger issues below,
whose WS re-runs are further confirmation of the same mechanism.
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

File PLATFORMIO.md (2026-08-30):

# PlatformIO Environment Configuration

How PlatformIO environments are structured across this workspace, using
`cerberus-gate-controller/` as the reference implementation. The other two
embedded firmware projects (`hesperus-timing-gate/`,
`ares-pulse-generator/`) share the same `platformio.ini`/`boards.ini`
composition pattern described below (their `boards.ini` section layout is
close to identical to cerberus's) — cerberus is used throughout as the
worked example because it has the most environments and features.

## Why this exists

Cerberus ships the same firmware to five different display boards (different
SoCs, flash sizes, panels). Rather than five near-duplicate `platformio.ini`
blocks, the config is factored into small reusable pieces and composed with
PlatformIO's `extends` mechanism.
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

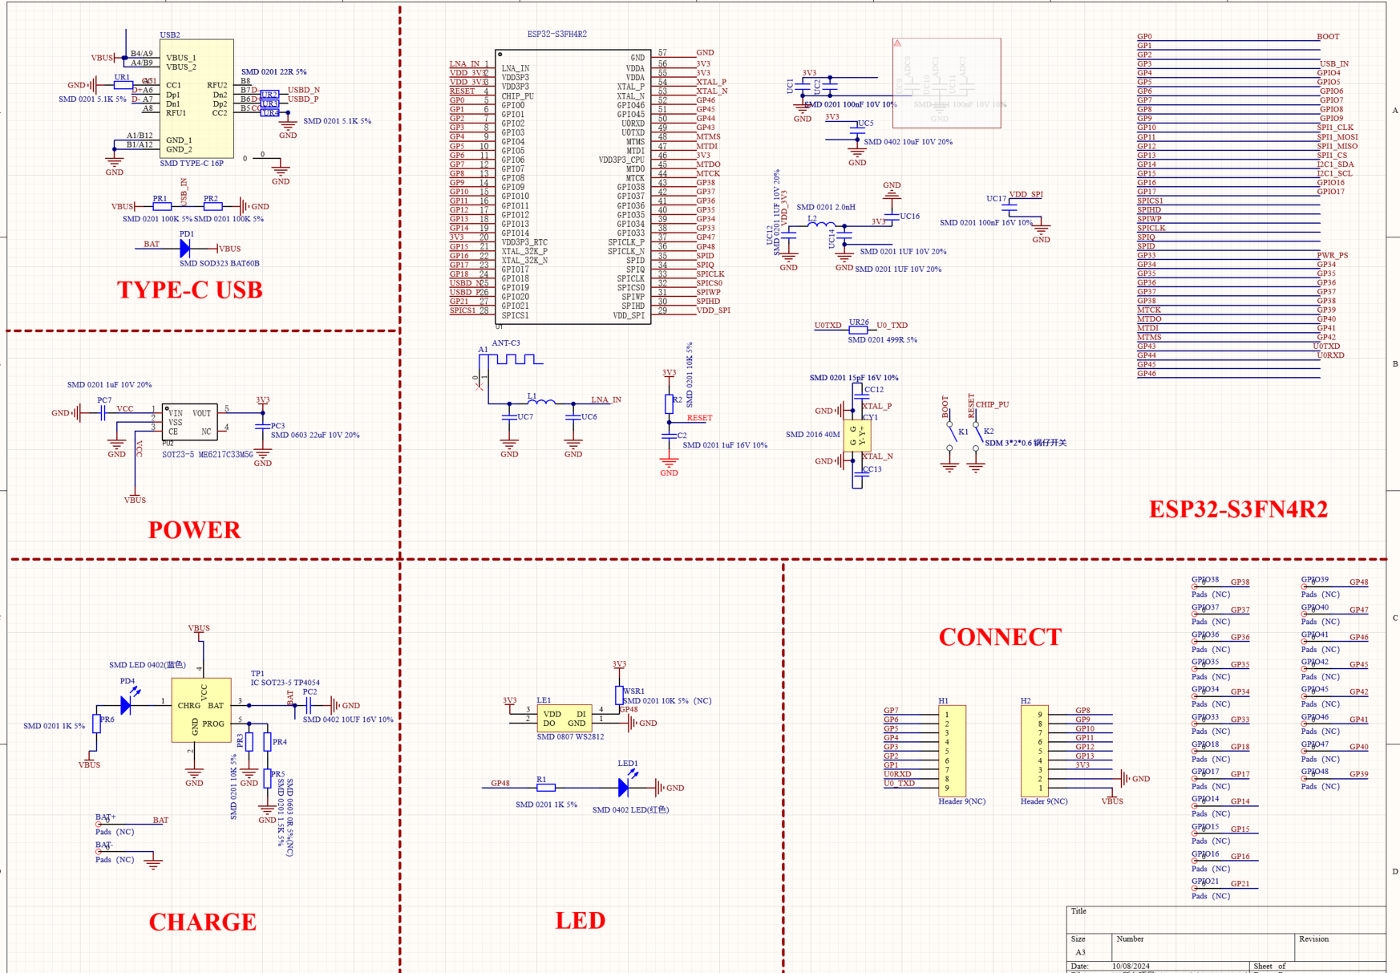
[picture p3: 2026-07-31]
references/ESP32-S3-SUPER-MINI/esp32-s3-super-mini-schematic.png

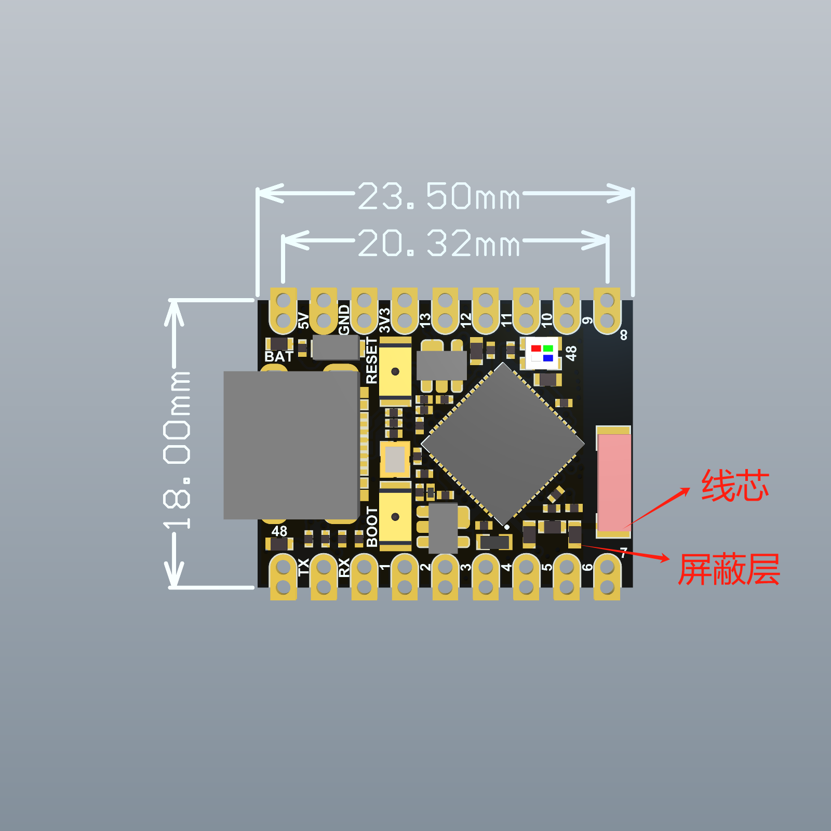
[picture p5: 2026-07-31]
references/ESP32-S3-SUPER-MINI/esp32s31-super-mini.png

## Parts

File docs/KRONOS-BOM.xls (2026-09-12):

HESPERUS WALL PAIR |  | QTY | UNIT COST | TOTAL
Filament (approx) | White PLA Generic | 150 | £0.01 | £1.50
Pogo Pin | https://www.amazon.co.uk/dp/B07FQ52W88 | 4 | £0.10 | £0.40
Magnets, 3mm x 1.5mm | https://www.first4magnets.com/product/3mm-dia-x-15mm-thick-n35-neodymium-magnet-018kg-pull-19188 | 16 | £0.10 | £1.60
IR cut filter discs | https://www.aliexpress.com/item/32884816388.html | 2 | £0.22 | £0.44
ESP32 S3 SuperMini | https://www.amazon.co.uk/Supermini-Development-Bluetooth-Frequency-Compatible/dp/B0H73XM847 | 2 | £5.20 | £10.40
Indicator LED 5mm | https://www.amazon.co.uk/200pcs-Emitting-Diodes-Resistor-Assorted/dp/B0CXDS8LDL | 4 | £0.02 | £0.08
NB11 Battery(2) and charger | https://www.amazon.co.uk/PowerTrust-NB-11L-NB-11LH-Battery-Charger/dp/B07Z7NT96F | 1 | £15.99 | £15.99
NB-11L cells (2) | https://www.amazon.co.uk/DSTE-NB-11LH-Rechargeable-Compatible-PowerShot/dp/B09JBWTGR5 | 1 | £10.99 | £10.99
OVLGC0C6B9 emitter | https://www.digikey.co.uk/en/products/detail/tt-electronics-optek-technology/OVLGC0C6B9 | 2 | £0.42 | £0.84
TEPT5600 phototransistor | https://www.digikey.co.uk/en/products/detail/vishay-semiconductor-opto-division/TEPT5600/1681192 | 2 | £0.64 | £1.28
SS12F15 slide switch | https://www.amazon.co.uk/Position-Vertical-Breadboard-Miniature-SlideSwitch/dp/B09XWHSDD2 | 2 | £0.14 | £0.28
 |  |  |  | £43.80
CERBERUS gate controller |  | QTY | UNIT COST | TOTAL
Filament | PLA Generic | 150 | £0.01 | £1.50
ESP 32 CYD2USB board | https://www.amazon.co.uk/dp/B0CG2WQGP9 | 1 | £17.98 | £17.98
Neokey keyboard PCB | https://www.digikey.co.uk/en/products/detail/adafruit-industries-llc/4980/14319123 | 1 | £8.78 | £8.78
Cherry MX keyswitch | https://www.amazon.co.uk/Mechanical-Keyboard-Switches-Clicky-Puller/dp/B0GJJBYB2V | 4 | £0.17 | £0.68
Speaker, 8 Ohm, 2030 | https://www.amazon.co.uk/dp/B0D4LR9W9D | 1 | £1.35 | £1.35
 |  |  |  | £30.29
CONTEST SET |  | QTY | UNIT COST | TOTAL
GL.iNet GL-SFT1200 Opal AC1200 Dual Band Travel Router | https://www.amazon.co.uk/dp/B09N72FMH5 | 1 | £35.99 | £35.99
CERBERUS Gate Controller |  | 1 | £30.29 | £30.29
HESPERUS Wall Pairs |  | 2 | £43.80 | £87.60
 |  |  |  | £153.88

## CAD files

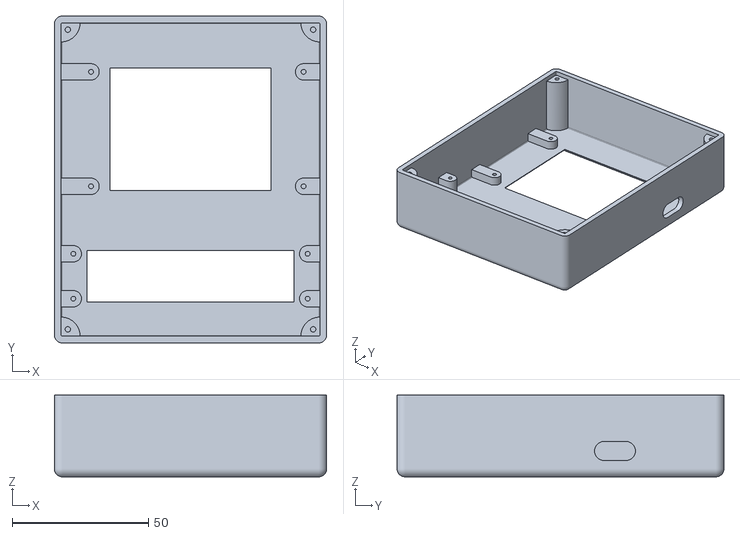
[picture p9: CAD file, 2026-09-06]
cerberus-gate-controller/hardware/mechanical/exports/cerberus-case-body.stl
100.0 x 120.0 x 30.0

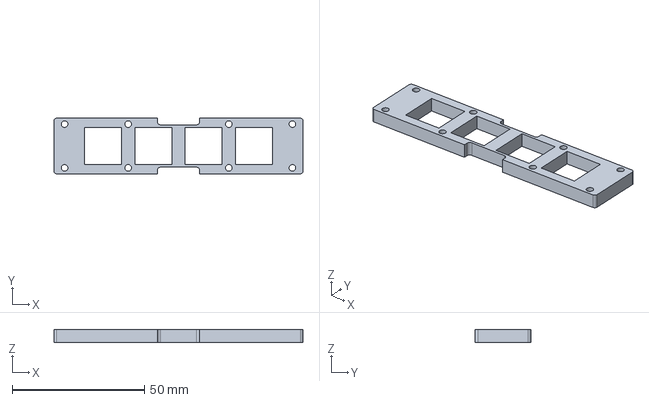
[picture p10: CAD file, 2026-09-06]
cerberus-gate-controller/hardware/mechanical/src/switch-plate.FCStd
94.0 x 21.0 x 4.80 mm

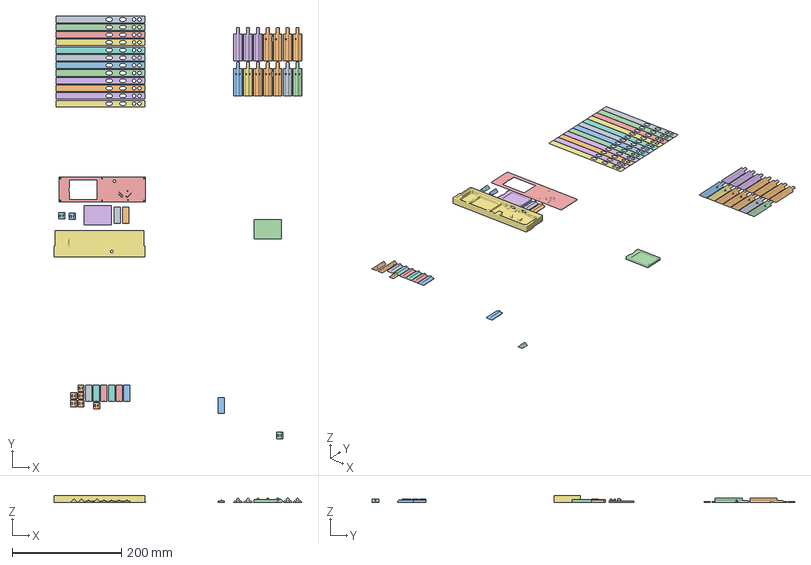
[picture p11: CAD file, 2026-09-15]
hardware-shared/hesperus/exports/hesperus-wall-parts-classic.3mf
454.3 x 774.0 x 12.0 mm
start-gate-wall-wall-cap.stl x 12
classic-sensor-post-half-2026-single-hole.stl x 4
start-gate-detector-3-tab.stl x 6
classic-sensor-post-half-2026-no-hole.stl x 3
classic-sensor-post-half-2026-holes.stl x 7
start-gate-wall-reflector.stl x 9
start-gate-wall-end-tab.stl x 3
hesperus-wall-classic-cover-exit-hole-with-hatch.stl
hesperus-wall-classic-battery-cover.stl x 2
hesperus-wall-classic-nb11-sliced.stl

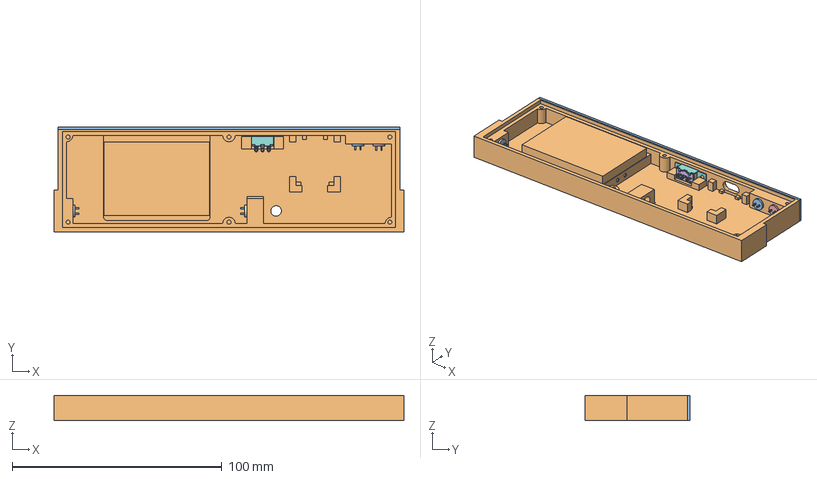
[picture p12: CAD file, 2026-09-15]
hardware-shared/hesperus/src/hesperus-wall-classic.FCStd
167.0 x 50.0 x 12.0 mm
WALL-BODY
BATTERY-HATCH-COVER
Pin003
Pin004
Pin005
Plastic part001
lever
metal-part
leads
leads001
leads002
leads003
Battery-NB11L
sliced-wall-body
sliced-wall-top

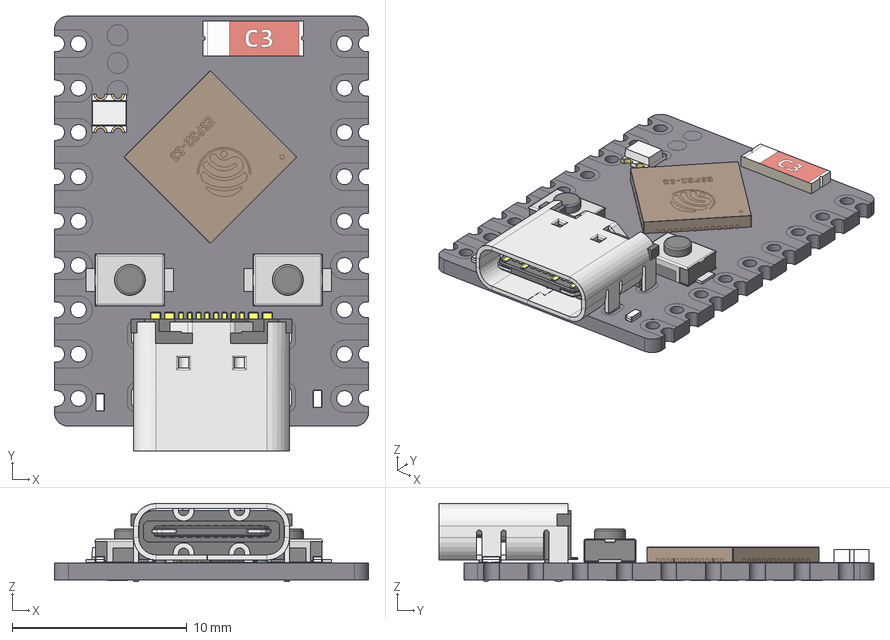
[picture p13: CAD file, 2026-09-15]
hardware-shared/kicad/3dmodels/ESP32-S3-SuperMini.step
18.0 x 24.9 x 4.47 mm
PCB
processor001
USB_type_C_smd_12p v001
SMD Ceramic Antenna v4 v001
Light002
Cathode Mark002
Anode Pin002
Cathode Pin002
Base002
Light003
Cathode Mark003
Anode Pin003
Cathode Pin003
Base003
3x4x2mm - 2 Pad v002
3x4x2mm - 2 Pad v003
WS2812-2020 v001

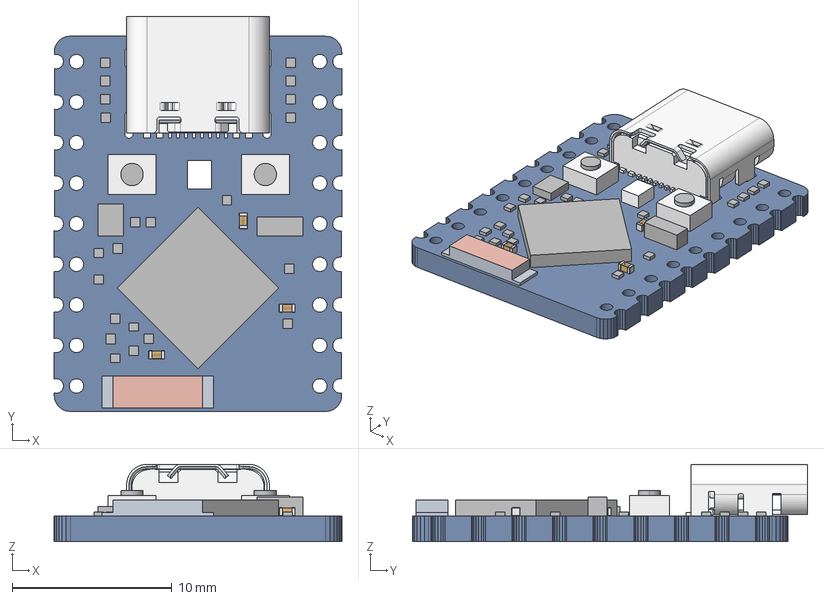
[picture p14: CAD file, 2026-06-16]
references/ESP32-S3-ZERO/ESP32-S3-Zero_v2-138eb3753cf14afa3252058c380ca416.stp
18.0 x 24.7 x 4.85 mm
BOARD
EXTRUDED-21020 x 13
EXTRUDED-21415 x 7
3_1_A x 3
EXTRUDED-58116 x 2
EXTRUDED-58651
EXTRUDED-59046
EXTRUDED-59609
TYPE-C_16PIN-9X3X7_3
PRT0001
C3
BUTTON-2X3XH1_5

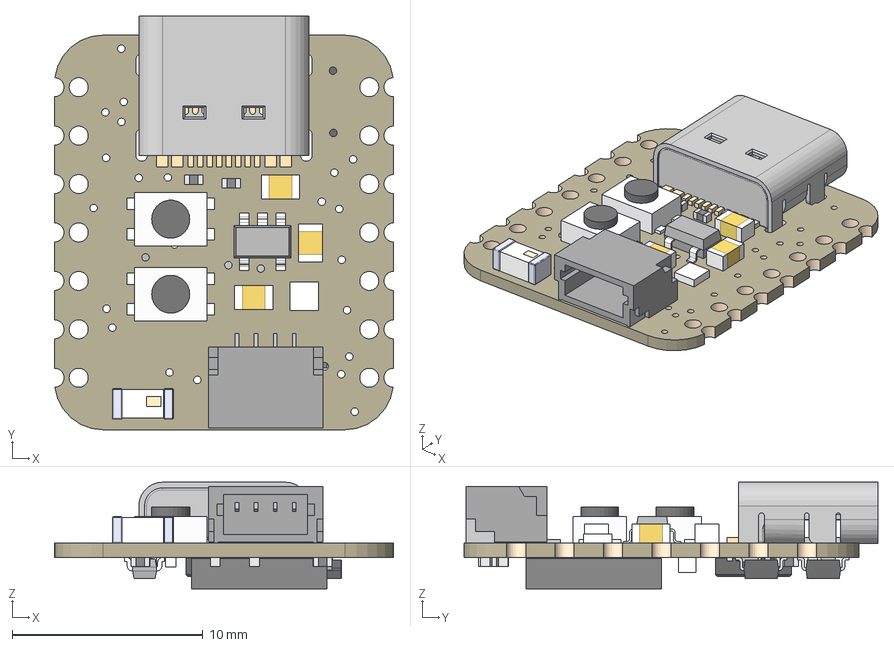
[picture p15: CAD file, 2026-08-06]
references/QtPy-ESP32-PICO/5395 QT Py ESP32 PICO.step
17.8 x 21.7 x 5.59 mm
Board
22uF x 3
BOOT0 x 2
10K x 14
USB TYPE C
STEMMA_I2C_QTSKINNY
AP2112K-3.3
WS2812B_SK6805_1515
NSR0320 x 2
2.2nH
2.4GHz
1uF
ESP-32-PICO-V3-02
CP2102N-24
DUAL NPN

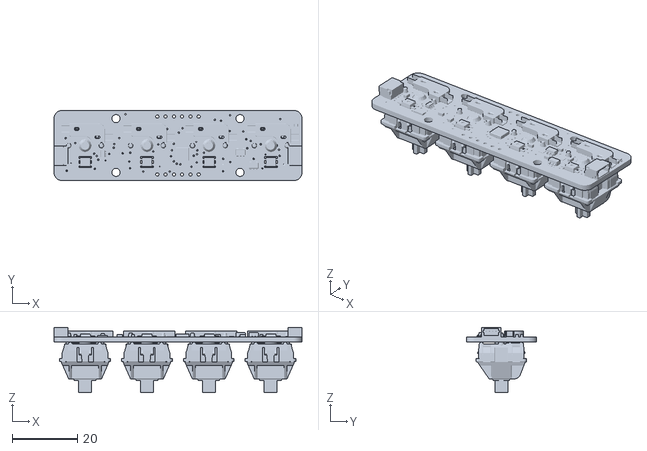
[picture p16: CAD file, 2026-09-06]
cerberus-gate-controller/hardware/mechanical/exports/neokey-4x1-with-switches.stl
76.2 x 21.6 x 20.0

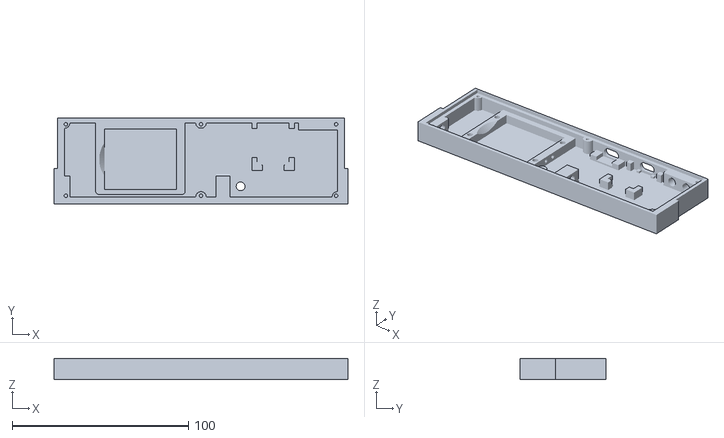
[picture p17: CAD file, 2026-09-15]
hardware-shared/hesperus/exports/hesperus-wall-classic-nb11-sliced.stl
167.0 x 48.8 x 12.0

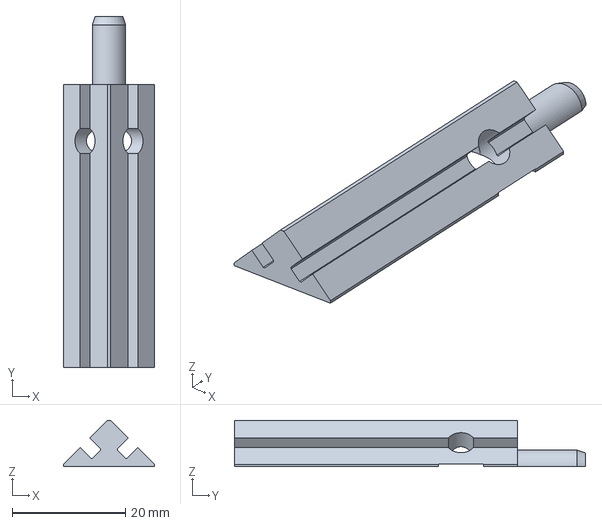
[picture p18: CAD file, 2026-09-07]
hardware-shared/hesperus/src/sensor-post-half-classic-2026.FCStd
16.2 x 62.0 x 8.20 mm

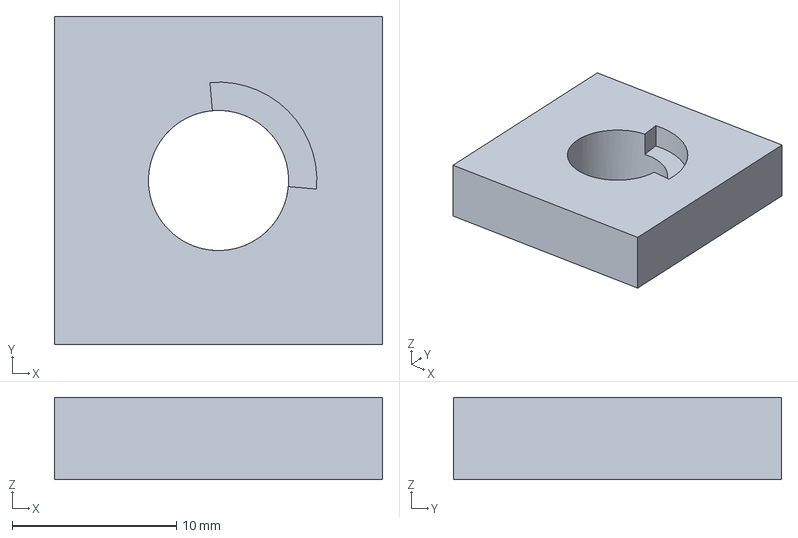
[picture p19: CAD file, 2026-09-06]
cerberus-gate-controller/hardware/mechanical/src/antenna-mount.FCStd
20.0 x 20.0 x 5.00 mm

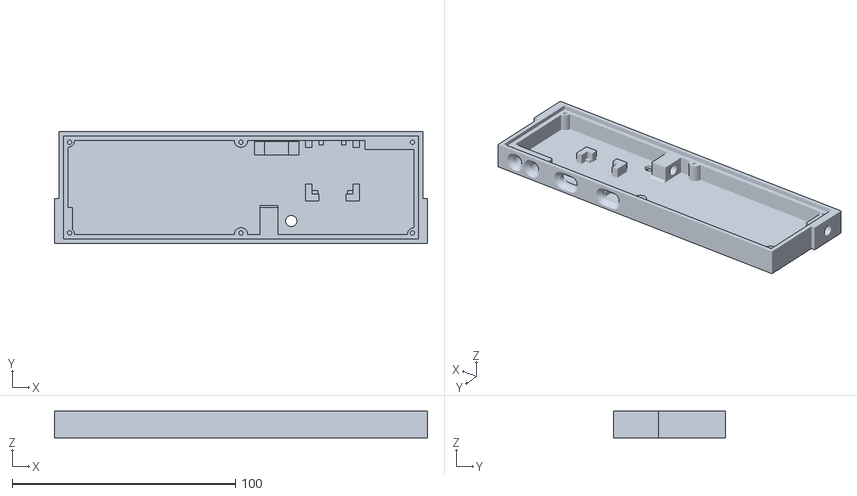
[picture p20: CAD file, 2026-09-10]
hardware-shared/hesperus/exports/hesperus-wall-classic-body.stl
167.0 x 50.0 x 12.0

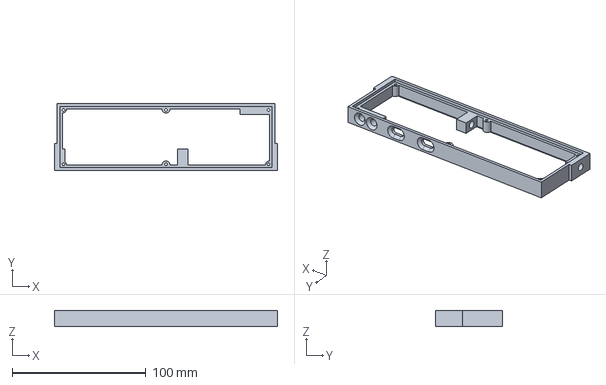
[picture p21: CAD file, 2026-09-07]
hardware-shared/hesperus/src/hesperus-wall-frame-classic.FCStd
167.0 x 50.0 x 12.0 mm

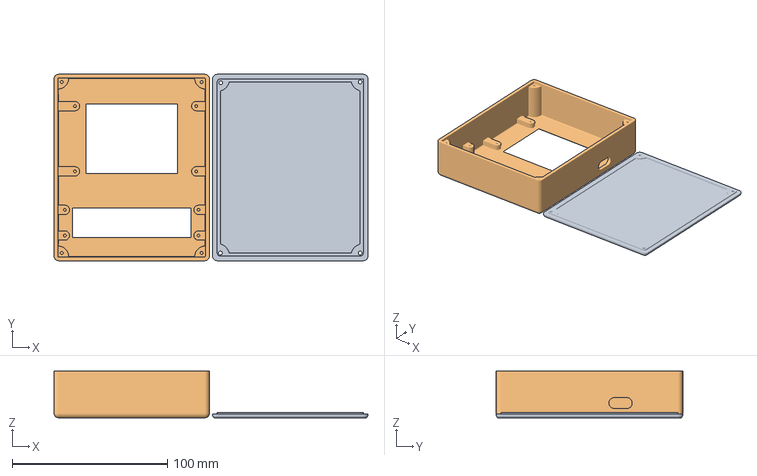
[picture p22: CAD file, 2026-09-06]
cerberus-gate-controller/hardware/mechanical/exports/cerberus-case.3mf
202.0 x 120.0 x 30.0 mm
timer-case-flat-base.stl
timer-case-flat-main-body.stl

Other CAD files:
cerberus-gate-controller/hardware/mechanical/src/cerberus-case.FCStd
cerberus-gate-controller/hardware/mechanical/exports/switch-plate.stl
cerberus-gate-controller/hardware/mechanical/src/neokey-4x1.FCStd
hardware-shared/hesperus/exports/hesperus-wall-classic-nb11.stl
cerberus-gate-controller/hardware/mechanical/exports/XDA_blank_rounded_keycaps.3mf
cerberus-gate-controller/hardware/mechanical/exports/cerberus-case-back.stl
cerberus-gate-controller/hardware/mechanical/exports/cerberus-keycaps.3mf
cerberus-gate-controller/hardware/mechanical/exports/cherry-mx-switch.stl
hardware-shared/hesperus/exports/hesperus-wall-classic-battery-cover.stl
hardware-shared/hesperus/exports/hesperus-wall-classic-cap.stl
hardware-shared/hesperus/exports/hesperus-wall-classic-cover-exit-hole-with-hatch.stl
hardware-shared/hesperus/exports/hesperus-wall-classic-cover-exit-hole.stl
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

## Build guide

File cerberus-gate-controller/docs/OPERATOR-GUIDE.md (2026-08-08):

# Cerberus operator guide

A guide for running a race session on a CERBERUS gate controller — what the
main menu and Wi-Fi setup look like, what the physical buttons and LEDs do,
what the screen shows, and how to work through a normal race day. For how
the software implements any of this, see `docs/RACE-STATE-MACHINE.md`
(state-by-state spec) and `docs/INPUT-SYSTEM.md` (input wiring).

## Contents

- [Cerberus operator guide](#cerberus-operator-guide)
  - [Contents](#contents)
  - [Startup and main menu](#startup-and-main-menu)
  - [Connecting to a Wi-Fi network](#connecting-to-a-wi-fi-network)
  - [Using the box from a PC or phone](#using-the-box-from-a-pc-or-phone)
  - [The physical controls](#the-physical-controls)
  - [What the LEDs mean](#what-the-leds-mean)
  - [Power-on and Calibrating](#power-on-and-calibrating)
  - [Running a race](#running-a-race)
  - [Remote control](#remote-control)
  - [Troubleshooting](#troubleshooting)

## Startup and main menu

On power-up the controller shows a main menu with a 2x3 grid of buttons
(five are active; the sixth slot is currently unused):

| Button | What it does |
|---|---|
| **WiFi SETUP** | Shows the network last joined and the controller's current IP address, and lets you join a different network (see below). |
| **GATE TEST** | Lets you test that the gates respond, without running a full race. |
| **MAZE TIMER** | Goes to the race timer, passing through Calibrating on the way (see "Power-on and Calibrating"). Long-press ARM, or have RATS send a New Mouse message, to get started. |
| **RESET** | Resets the controller. |
| **SETTINGS** | Toggles serial/debug **verbosity** and **watchdog** message output. |

From any race screen, long-press key 3 (TOUCH) to return to this menu at
any time.

## Connecting to a Wi-Fi network

1. From the main menu, press **WiFi SETUP**.
2. Select **Join New Network**.
3. The screen shows the name and password of a temporary access point
   (`CERBERUS-SETUP`).
4. On your phone or laptop, join that network, then browse to
   `192.168.4.1/wifi`. This opens a page where you can enter the SSID and
   password of the network you actually want the controller on.
5. Submit the form. The controller reboots and attempts to join that
   network — the screen flashes briefly while it connects.

If the controller can't reach the saved network at all, key 3 (TOUCH)
blinks cyan indefinitely rather than giving up — see
[Troubleshooting](#troubleshooting).

## Using the box from a PC or phone

Once connected, the controller's IP address is shown on the WiFi Setup
screen. From any device on the same network, browse to:

- `http://<controller-ip>/` — a simple clock, synchronized to the box.
- `http://<controller-ip>/leaderboard` — an automatically updated
  leaderboard.

## The physical controls

CERBERUS is operated with a **NeoKey 1x4** keypad — four buttons, each with
its own LED, wired in a fixed order:

| Key | Label | Short press | Long press (hold) |
|---|---|---|---|
| 0 | **ARM** | Arm — confirms a mouse is in the start cell, ready to run | **Restart** — abandon the current mouse and start a fresh entry from Calibrating/Waiting/Armed/Running/Goal |
| 1 | **START** | Start — the mouse has left the start cell, begin timing | (no effect, except on the main menu screen — see below) |
| 2 | **GOAL** | Goal — the mouse has reached the finish | (no effect) |
| 3 | **TOUCH** | Currently has no effect on race progress | **Return to menu** (leaves the current race screen; does not affect race state) |

The touchscreen itself is **not** used for ARM/START/GOAL during a race —
it only navigates between the menu, main timer, and settings screens.
Tapping the WiFi-status area on the main screen opens the setup menu.

**On the main menu screen only**, long-pressing START launches the touch
calibration wizard — see [Troubleshooting](#troubleshooting) if the
touchscreen is misbehaving.

If the NeoKey module is unplugged or not detected, all four LEDs stay
off and **none of the local buttons work** — the controller still responds
to remote ARM/START/GOAL/new-mouse commands over serial or HTTP (see
[Remote control](#remote-control)) until the keypad is reconnected.

## What the LEDs mean

Keys 0-2 (ARM/START/GOAL) reflect the current race state:

| Race state | Key 0 (ARM) | Key 1 (START) | Key 2 (GOAL) |
|---|---|---|---|
| Calibrating | off | off | off |
| Waiting for robot | green | green | green |
| Armed | green | off | off |
| Running | off | green | off |
| Goal reached | off | off | green |

Key 3 (TOUCH) is reserved for WiFi status but stays off either way — WiFi
connection status is shown on the main screen's status bar instead (WIFI and
a dBm reading when connected, red **MANUAL** when not — see below). The only
exception to key 3 staying off is during Calibrating (see below), where it
briefly reflects a keypress instead.

## Power-on and Calibrating

On power-up (or after a Restart from any other state) the controller
starts in **Calibrating**. This is a self-test screen, not a race state:

- Time display shows `.........`, entry time shows `00:00`, run count
  shows `0/5`, mouse name and run times are blank.
- Pressing any of the four physical keys lights that key's LED **yellow**
  for as long as it's held — use this to confirm each button (and, on
  systems with separate gate hardware, each gate signal feeding this
  controller) is actually registering before a race starts.
- **Calibrating only exits on a genuine "new mouse" event**: a long press
  of ARM, or a `<98,...>` NewMouse message from the host over serial/HTTP.
  A short press of TOUCH does **not** exit Calibrating (it currently has
  no effect in any state — see the controls table above).

## Running a race

1. **Start a new mouse.** Long-press ARM (or send a NewMouse command from
   the host). The controller goes straight to **Waiting**, all three LEDs
   green. The screen shows the mouse's name, the maximum entry time, and a
   `0/5` run counter (defaults; the host can override both via serial/HTTP
   before the first Arm).
2. **Place the mouse in the start cell and press ARM.** The controller
   moves to **Armed** — key 0 (ARM) lights, keys 1/2 go off. The run timer
   is reset and waiting; an overall entry-time countdown starts (only on
   the very first Arm of this mouse, not on re-arms).
3. **Press START when the mouse leaves the start cell.** The controller
   moves to **Running** — key 1 (START) lights, run timer counts up.
4. **Press GOAL when the mouse reaches the finish.** The controller moves
   to **Goal** — key 2 (GOAL) lights, the run time is recorded and sent to
   the host.
   - If the mouse doesn't finish (crashes, needs to be picked up and
     restarted), press **ARM** instead of GOAL — this abandons the current
     attempt and returns to Armed for another try, without recording a
     run.
5. **Press ARM again to continue.** From Goal, ARM re-arms for the next
   run if the mouse hasn't used up its allowed run count, or drops back to
   **Waiting** if it has. There is no automatic advance out of Goal —
   it always waits for an explicit ARM.
6. **Long-press ARM at any point** to abandon the current mouse entirely
   and start a fresh entry (back to step 1). This is also how you recover
   if something has gone wrong mid-run.

A false start can be undone remotely: the host can send an ExtraRun
message (`<92,...>`) to give back a run that shouldn't have counted,
without a local button for it.

## Remote control

Everything above can equally be driven remotely — a host PC connected
over serial (RATS V2 protocol) or another device on the network posting
to the HTTP API produces the exact same ARM/START/GOAL/new-mouse commands
as the physical keypad, and the display/LEDs update the same way
regardless of source. Local and remote control can be mixed freely during
a session; there's no mode switch to select between them.

## Troubleshooting

- **Touchscreen taps land in the wrong place, or don't register at all:**
  from the main menu screen, long-press START (key 1) to re-run the touch
  calibration wizard. This is a physical NeoKey gesture deliberately, so
  it works even when the touchscreen is too miscalibrated to use — no
  flash erase needed.
- **No LEDs at all, buttons don't respond:** the NeoKey module isn't
  detected (unplugged, bad I2C connection). The controller still runs
  and still accepts remote commands; reseat/reconnect the keypad to
  restore local control — no reboot needed, it's detected automatically.
- **Status bar shows red "MANUAL" instead of a dBm reading:** WiFi isn't
  connected. There's no timeout and no forced hand-off to WiFi setup — the
  controller keeps racing on the physical buttons indefinitely, and keeps
  retrying the network in the background on its own. Local racing is
  unaffected (WiFi is only needed for remote gates, the HTTP leaderboard,
  and HTTP-driven remote control). To set up WiFi, hold TOUCH to reach the
  main menu, then press **WiFi SETUP**.
- **Controller stuck showing Calibrating:** it's waiting for a genuine
  new-mouse event — long-press ARM, or send `<98,...>` from the host.
- **Touchscreen unresponsive after a screen change:** there's a brief
  (250ms) lockout after every screen switch to avoid a stray tap
  registering twice; wait a moment and try again.
- **Menu locked out after a botched touch calibration:** this is a known
  gap with no on-device recovery yet — see `docs/PLANNED-UPDATES.md`.
  Race control via the NeoKey keypad is unaffected either way, since it
  doesn't depend on touch.

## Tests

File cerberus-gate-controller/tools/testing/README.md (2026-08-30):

# Gate Event Test Scripts

Manual curl test scripts for the `POST /api/event` endpoint (see
`docs/SYSTEM-DESCRIPTION.md`'s HTTP Server section,
implemented in `firmware/src/net/http-server.h` / `firmware/src/race/race-command-source.h`).
See the bottom of this file for `ws_send_event.py`, the equivalent tool for
the persistent WebSocket endpoint (`/ws`, NETWORK-TIMING-LOG.md
recommendation 1).

## Endpoint

```
POST http://cerberus.local/api/event
Content-Type: application/json

{
  "gate_id": "START_GATE",
  "event": "START",
  "tsf_us": 4321098765,
  "gate_us": 1098765634
}
```

| Field | Type | Meaning |
|---|---|---|
| `gate_id`| string | Free-text label for the sending gate. Not validated against a fixed list -- carried through unchanged into the event queue/payload for logging/display. |
| `event`  | string | One of `ARM`, `START`, `GOAL`, `NEW_MOUSE` (also `RESTART`, accepted but not covered by these scripts). Anything else is rejected. `NEW_MOUSE` is handled identically to `RESTART` internally -- forces a new-mouse selection from any race state, same as an ARM-button long-press or the serial `<98,0>` message. |
| `tsf_us` | uint64 | Gate's local reading of the shared Wi-Fi TSF clock at the moment of the event. |
| `gate_us`| uint64 | Gate's own free-running microsecond timer, used for drift-compensation cross-referencing against `tsf_us`. |

Responses:
- `200 {"status":"ok"}` -- event accepted and queued.
- `400 {"status":"error","reason":"unrecognised event"}` -- `event` didn't match a known command.

## Scripts

- `send-arm-event.sh`
- `send-start-event.sh`
- `send-goal-event.sh`
- `send-new-mouse-event.sh`
- `send-one-mouse.sh` -- scripted multi-event sequence, see below.
- `send-full-race.sh` -- runs `send-one-mouse.sh` repeatedly, see below.

The four single-event scripts each send one event with fixed dummy
`tsf_us`/`gate_us` values (not real TSF/timer readings -- fine for exercising
the HTTP handler and race state machine, not for timing accuracy testing).

### Usage

```
./send-arm-event.sh              # gate_id defaults to ARM_GATE
./send-start-event.sh            # gate_id defaults to START_GATE
./send-goal-event.sh             # gate_id defaults to GOAL_GATE
./send-new-mouse-event.sh        # gate_id defaults to NEW_MOUSE_GATE

./send-start-event.sh MY_GATE_LABEL   # override gate_id

CERBERUS_HOST=192.168.1.50 ./send-arm-event.sh   # override host (default cerberus.local)
```

A typical run sequence to exercise the race state machine end to end:

```
./send-arm-event.sh
./send-start-event.sh
./send-goal-event.sh
```

Then check `http://cerberus.local/leaderboard` to confirm the run was recorded.

## send-one-mouse.sh

Drives a full timed sequence against a live unit, unattended:

```
NEW_MOUSE          (delay 1s)
ARM                (delay 200ms)
START              (delay 4s)
GOAL
-- repeated 3 more times --
ARM                (delay 200ms)
START              (delay random 1-5s)
GOAL
```

Unlike the other scripts, `tsf_us`/`gate_us` are set to the actual current
time (`date +%s%6N`, microseconds since epoch) at the moment each request is
sent, since the delays here are real -- this keeps the dummy timestamps
consistent with wall-clock elapsed time between events.

```
./send-one-mouse.sh                    # gate_id defaults to RACE_SEQUENCE_GATE
./send-one-mouse.sh MY_GATE_LABEL       # override gate_id
CERBERUS_HOST=192.168.1.50 ./send-one-mouse.sh
```

Prints one line per event with a timestamp and the HTTP status returned.
Watch `http://cerberus.local/leaderboard` while it runs to see runs land in
real time.

A dropped/failed request (bad host, timeout, transient network blip) is
logged as `HTTP ERR` rather than aborting the sequence -- the script always
runs all 13 events and prints a `N/13 events failed` summary at the end, so
soak runs survive transient blips instead of dying silently partway through.

## send-full-race.sh

Runs `send-one-mouse.sh` back to back, for soak/stability testing over
many runs. Defaults to 20 repeats (80 total ARM/START/GOAL cycles).

```
./send-full-race.sh                        # 20 repeats, default gate_id
./send-full-race.sh 50                      # 50 repeats
./send-full-race.sh 50 MY_GATE_LABEL        # 50 repeats, custom gate_id
CERBERUS_HOST=192.168.1.50 ./send-full-race.sh
```

At ~20-40s per sequence, 20 repeats takes roughly 7-13 minutes. A failed
sequence (non-zero exit) is logged and the loop continues to the next repeat
rather than stopping the batch.

## ws_send_event.py

Same event schema as the scripts above, but sent over `/ws` (a persistent
WebSocket connection) instead of `POST /api/event` (a fresh HTTP connection
per event) -- the transport recommendation 1 in
`NETWORK-TIMING-LOG.md` introduces. One connection is opened and reused for
every event in a run, matching how a real gate board behaves post-recommendation-1
(unlike the HTTP scripts, which necessarily open a new connection each time).

No response is sent back from cerberus over the socket (fire-and-forget by
design -- see `net/http-server.h`'s `ws_event_handler()` comment), so `sent`
below only confirms the local send succeeded, not that cerberus processed it.
Check cerberus's own debug log for a `[WS] DATA ... body=...` line (with
verbose debug logging on) to confirm that.

Requires the `websocket-client` package: `pip install websocket-client`

```
./ws_send_event.py ARM                          # gate_id defaults to WS_TEST_GATE
./ws_send_event.py START MY_GATE_LABEL           # override gate_id
./ws_send_event.py sequence                      # NEW_MOUSE + 4 ARM/START/GOAL cycles, one connection
./ws_send_event.py sequence --repeats 10         # 1 + 10 cycles instead of 1 + 3
CERBERUS_HOST=192.168.1.50 ./ws_send_event.py GOAL
```

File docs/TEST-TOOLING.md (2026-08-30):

# Test Tooling Reference

An inventory of every test/bench tool in this workspace: what it is, what
it tells you, and how to invoke it. Factual reference only — for the
investigation these tools were built to support (network latency, event
reliability, race-timing correctness), see `NETWORK-TIMING-LOG.md`, which
cross-references specific tools by name from within each issue's
Confirmation/Verification sections.

Two categories: bench/hardware tools (need real gate hardware, exercise
real Wi-Fi/TSF timing) and native unit tests (deterministic, no hardware,
run in CI-style fashion).

## Bench/hardware tools

These require a real `cerberus-gate-controller` board, plus, depending on
the tool, either real `hesperus-timing-gate` boards or `ares-pulse-generator`
standing in for one.

### `ares-pulse-generator` — GPIO trigger simulator

A PlatformIO/Arduino firmware project (`ares-pulse-generator/firmware/src/main.cpp`)
that drives three active-low GPIO outputs (`TRG_ARM`=7, `TRG_START`=6,
`TRG_GOAL`=5) to simulate photodiode/beam-break triggers, wired into a real
`hesperus-timing-gate` board's trigger inputs — bench-tests the gate/
cerberus system without needing a physical robot to run the course
repeatedly.

Build/flash: `pio run -e <env> -t upload` from inside `ares-pulse-generator/`,
one of `ares-pulser-s3-zero`, `ares-pulser-s3-super-mini`,
`ares-pulser-c3-super-mini`, `ares-pulser-c3-xiao`.

**Scenario selection is a runtime serial CLI** (115200 baud, USB serial).
Connect and type `help` (alias: `?`) to see the available commands
(`list`, `run`, `arm`, `status`) with a one-line description of each, or
`list` to see available trial names with a one-line description of each.
`run <name> [count] [interval_ms]` fires a trial immediately (blocks until
done, printing one `RUN <name>` line per rep then `OK <name>`); `arm <name>
[count] [interval_ms]` sets which trial the physical `BTN_IN` (pin 4)
button fires on its next press (`BTN <name>` per rep, `OK <name>` when the
repeats finish); `status` reports what's currently armed and with what
count/interval. `count` and `interval_ms` are both optional, defaulting to
1 rep and 1000ms between reps — pass `count` to reproduce a statistical run
(e.g. the old 100-rep pattern, or several `full_run`s back-to-back, e.g.
`run full_run 4`) without the host having to loop the command itself.
Unknown trial names print `ERR unknown trial: <name>` instead of silently
doing nothing.

| Trial name | Scenario | Key constants |
|---|---|---|
| `arm_pulse` | Single 100ms pulse on `TRG_ARM` — smoke test/baseline. | — |
| `goal_pulse` | Single 100ms pulse on `TRG_GOAL` — smoke test/baseline, and the single-gate `GOAL`-only steady-state traffic for the proposed WS-jitter characterization test (`run goal_pulse 10000 250`, ~42 minutes; see the "Unexplained minor WS jitter" issue in `NETWORK-TIMING-LOG.md`). | — |
| `arm_then_start` | `TRG_ARM` then `TRG_START`, edges 200ms apart — one board serving both ARM and START gates, robot crossing both in quick succession. | `ARM_TO_START_GAP_MS` (200) |
| `burst` | `BURST_COUNT` pulses on `TRG_GOAL`, `BURST_INTERVAL_MS` apart, each `BURST_PULSE_MS` wide — rapid-fire triggering, checks whether the send-side queue overflows/drops. Interval is chosen above the 50ms debounce but well under a ~250-270ms send cycle, so a queue backlog is expected. | `BURST_COUNT` (40), `BURST_INTERVAL_MS` (90ms), `BURST_PULSE_MS` (10ms) |
| `double_trigger` | Two `TRG_GOAL` pulses on the same pin, `DOUBLE_TRIGGER_GAP_MS` apart — a robot with a gapped/slotted structure breaking one gate's beam twice for what should count as one crossing. | `DOUBLE_TRIGGER_GAP_MS` (150ms) |
| `full_run` | One full ARM→START→GOAL sequence, `RUN_DURATION_MS` START-to-GOAL — end-to-end/leaderboard-facing checks (e.g. does the committed time come out exact) rather than a single stress dimension. Fire several with `run full_run <count>` (the old `four_runs` trial's fixed internal 4x-increasing-duration loop is now the caller's choice of count, all runs sharing `RUN_DURATION_MS`). Also the pattern to repeat throughout an external congested-airtime stress window (airtime saturation/bulk throughput/channel interference/broadband noise, see below) once one is running. | `RUN_DURATION_MS` (3000), `ARM_TO_START_GAP_MS` (200) |
| `wake_sweep` | One `TRG_ARM` pulse after each of `WAKE_SWEEP_GAPS_MS`'s idle gaps in turn (1s, 5s, 15s, 30s, 60s), printing the gap before each pulse — the wake-to-first-byte-after-idle-gap sweep the Wi-Fi power-save issue's verification method proposes, for comparing `WIFI_PS_NONE`/`MIN_MODEM`/`MAX_MODEM` modem-sleep wake cost. Takes ~111s (the sum of the gaps) to run. | `WAKE_SWEEP_GAPS_MS` ({1000,5000,15000,30000,60000}) |

Caveats: needs the physical pulser board wired to a real gate's trigger
inputs; no Wi-Fi logic in the pulser itself, it's pure GPIO.

### `cerberus-gate-controller/tools/testing/` — direct HTTP/WS event injection

Sends synthetic gate events straight at cerberus over the network, no
gate/pulser hardware needed at all — useful for exercising cerberus's own
handler/state-machine/dedup logic in isolation, or for crafting scenarios a
real gate could never naturally produce (e.g. a deliberately stale
timestamp). Endpoint schema (both HTTP and WS): `gate_id` (string, free
text), `event` (`ARM`/`START`/`GOAL`/`NEW_MOUSE`/`RESTART`), `tsf_us`
(uint64), `gate_us` (uint64). Full schema/response docs in that directory's
own `README.md`.

- **`send-arm-event.sh` / `send-start-event.sh` / `send-goal-event.sh` /
  `send-new-mouse-event.sh`** — one `curl -i -X POST` to `/api/event` each,
  fixed dummy `tsf_us`/`gate_us` (not real clock readings — fine for
  exercising the handler/state machine, not for timing accuracy).
  `./send-arm-event.sh [gate_id]` (default e.g. `ARM_GATE`),
  `CERBERUS_HOST=<ip>` env var overrides the default host.
- **`send-one-mouse.sh`** — one full unattended timed sequence over HTTP:
  `NEW_MOUSE` (1s) → `ARM` (200ms) → `START` (4s) → `GOAL`, then 3 more
  `ARM`(200ms)/`START`(random 1-5s)/`GOAL` cycles (13 events total).
  `tsf_us`/`gate_us` are stamped with real `date +%s%6N` at send time, so
  timestamps track the real delays. `./send-one-mouse.sh [gate_id]`,
  `CERBERUS_HOST` override. Prints one line per event
  (`HH:MM:SS EVENT HTTP <code>`), continues past failures, ends with an
  `N/13 events failed` summary.
- **`send-full-race.sh`** — runs `send-one-mouse.sh` back-to-back for
  soak/stability testing. `./send-full-race.sh [count] [gate_id]`, default
  20 repeats (80 cycles total), ~20-40s/sequence (~7-13 min for the
  default). A failing sequence is logged; the loop continues.
- **`ws_send_event.py`** — same schema, sent over the persistent `/ws`
  WebSocket endpoint (one held-open connection, matching how a real gate
  behaves post-persistent-connections) instead of a fresh HTTP connection
  per event. Requires `pip install websocket-client`.
  - `./ws_send_event.py ARM|START|GOAL|RESTART|NEW_MOUSE [gate_id]` — single
    event (`gate_id` defaults to `WS_TEST_GATE`).
  - `./ws_send_event.py sequence [--repeats N]` — `NEW_MOUSE` + one fixed
    10s ARM/START/GOAL cycle + `N` more random 3-10s cycles (default 3).
  - `--host HOST` / `CERBERUS_HOST` env var (default `cerberus.local`).
  - `--tsf-us N` — overrides the stamped-`now` `tsf_us` (single-event mode
    only). Used to hand-craft an arbitrarily old `GOAL` on demand — this is
    how the stale-event misattribution scenario is reproduced without
    needing to actually delay a real message in flight.
  - Fire-and-forget: no response comes back over the socket by design, so
    `sent`/`ERROR` in the output only reflects whether the local `send()`
    call succeeded, not that cerberus processed it. Cross-check cerberus's
    own debug log for a `[WS] DATA ... body=...` line to confirm receipt.
- **`SERIAL-TEST-PLAN.md`** (same directory) — a manual, checklist-style
  test plan for the host-PC serial link (RATS V2 protocol), not an
  executable tool. Requires a serial terminal at 9600 baud, CR+LF line
  ending, and a physical board.

### `tools/cerberus_log_stats.py` — latency/gap analysis

The primary bench-data analysis tool. Extracts event-receipt lines from a
cerberus debug log and computes one-way trigger-to-receipt latency as
`recv_ms*1000 - tsf_us` — valid without NTP or any clock sync, since
cerberus and hesperus share the Wi-Fi TSF timeline as stations on the same
AP. Matches on `#[recv_ms] ... body={...}` — deliberately loose about
what precedes `body=`, so it works unmodified on both `[HTTP] POST
/api/event` lines and `[WS] DATA` lines.

```
python3 tools/cerberus_log_stats.py LOGFILE [--event GOAL] [--csv out.csv] [--gaps] [--no-table]
python3 tools/cerberus_log_stats.py -              # read from stdin
```

- `--event TYPE` — filter to one event type (`GOAL`, `START`, `ARM`, …).
- `--gaps` — print consecutive `d_gate_ms`/`d_latency_ms` deltas between
  events (the burst/queueing diagnostic — a growing `d_latency_ms` against
  a roughly-constant `d_gate_ms` is the queueing signature).
- `--csv PATH` — write rows (`line, recv_ms, gate_id, event, tsf_us,
  gate_us, latency_us`) to CSV.
- `--no-table` — suppress the per-row table, stats only.

Output: a per-row table (`recv_ms, event, tsf_us, gate_us, latency_ms`),
then per-event-type and overall latency stats — mean/median/stdev/min/max/
p90/p95/p99, all in ms. This exact format is what appears in the
`*-analysis.txt` companion files in `test-data/` (see below).

### `test-data/` — raw captures and their analysis

Bench-run artifacts live at the workspace root, as paired files:
`<scenario>[-ws]-<YYYYMMDD>-<HHMM>.txt` (raw cerberus debug-log capture)
and, for most, a companion `<same-name>-analysis.txt` (the literal stdout
of `cerberus_log_stats.py` run against it). The `-ws` suffix marks a
WebSocket-transport run, distinguishing it from the HTTP-default baseline
of the same scenario — used throughout `NETWORK-TIMING-LOG.md` to compare
before/after a transport change.

## Native unit tests

Deterministic, hardware-free — validate firmware logic in isolation, not
real Wi-Fi/TSF timing or network transport. Run from inside
`cerberus-gate-controller/`:

```
pio test -e native
```

Uses `platform = native` / `test_framework = unity` with mock headers in
`test/native_mocks/` (`Arduino.h`, `debug-log.h`) so firmware logic
compiles and runs on the host, no board needed.

- **`test_race_timer`** (`test/test_race_timer/test_race_timer.cpp`) —
  `race/race-timer.h`: time-formatting helpers, leaderboard construction/
  sorting/tie-handling/truncation, and the full race state machine
  transition table (`CALIBRATE`→`WAITING`→`ARMED`→`RUNNING`→`GOAL`,
  RESTART/NEW_MOUSE handling, stale-GOAL rejection, the exact-start-tsf
  zero-time edge case, max-runs-exhausted behaviour).
- **`test_gate_event_dedup`** (`test/test_gate_event_dedup/test_gate_event_dedup.cpp`) —
  `net/gate-event-dedup.h`'s `gate_event_is_duplicate()`: first-sighting
  vs. exact-repeat, new-tsf-on-same-key, different-gate-id/different-event
  collisions, and round-robin table-wraparound past capacity.

## Not yet built: congested-airtime stress testing

Sketched in `hesperus-timing-gate/docs/review.md`'s "Possible stress tests"
section, referenced from `NETWORK-TIMING-LOG.md`'s outstanding-work list,
but no script/tool exists for any of these yet — manual setup only:

- **Airtime saturation** — several extra ESP32s (or laptops) running a
  tight HTTP-request loop against a local server, associated to the same AP.
- **Bulk throughput** — `iperf3 -s` on one machine, `iperf3 -c <ip> -t 300`
  from another, same AP.
- **Channel interference** — a second router broadcasting on an
  overlapping channel.
- **Broadband noise** — a 2.4GHz noise source (a microwave oven ~30cm from
  the AP is noted as a surprisingly effective blunt stressor).

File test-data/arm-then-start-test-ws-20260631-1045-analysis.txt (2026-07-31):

   #       recv_ms  event             tsf_us       gate_us  latency_ms
   0      39462745  ARM          39462736526     959802122         8.5
   1      39462950  START        39462936246     960001841        13.8
   2      39463742  ARM          39463736165     960801757         5.8
   3      39463945  START        39463936241     961001835         8.8
   4      39464741  ARM          39464736165     961801749         4.8
   5      39464942  START        39464936242     962001829         5.8
   6      39465742  ARM          39465736164     962801743         5.8
   7      39465945  START        39465936247     963001823         8.8
   8      39466741  ARM          39466736165     963801737         4.8
   9      39466945  START        39466936246     964001817         8.8
  10      39467742  ARM          39467736166     964801731         5.8
  11      39467943  START        39467936240     965001811         6.8
  12      39468744  ARM          39468736167     965801725         7.8
  13      39468945  START        39468936243     966001805         8.8
  14      39469743  ARM          39469736166     966801719         6.8
  15      39469947  START        39469936248     967001798        10.8
  16      39470744  ARM          39470736167     967801713         7.8
  17      39470945  START        39470936248     968001792         8.8
  18      39471742  ARM          39471736169     968801707         5.8
  19      39471948  START        39471936246     969001786        11.8
  20      39472741  ARM          39472736168     969801701         4.8
  21      39472946  START        39472936241     970001780         9.8
  22      39473742  ARM          39473736164     970801694         5.8
  23      39473942  START        39473936248     971001774         5.8
  24      39474743  ARM          39474736168     971801688         6.8
  25      39474955  START        39474936249     972001768        18.8
  26      39475750  ARM          39475736169     972801682        13.8
  27      39475944  START        39475936248     973001761         7.8
  28      39476744  ARM          39476736168     973801676         7.8
  29      39476947  START        39476936250     974001755        10.8
  30      39477741  ARM          39477736168     974801670         4.8
  31      39477942  START        39477936249     975001749         5.8
  32      39478743  ARM          39478736167     975801663         6.8
  33      39478945  START        39478936249     976001743         8.8
  34      39479742  ARM          39479736168     976801657         5.8
  35      39479951  START        39479936248     977001737        14.8
  36      39480744  ARM          39480736170     977801651         7.8
  37      39480942  START        39480936249     978001730         5.8
  38      39481741  ARM          39481736171     978801645         4.8
  39      39481944  START        39481936249     979001724         7.8
  40      39482741  ARM          39482736170     979801638         4.8
  41      39482944  START        39482936250     980001718         7.8
  42      39483746  ARM          39483736170     980801632         9.8
  43      39483943  START        39483936252     981001712         6.7
  44      39484742  ARM          39484736172     981801626         5.8
  45      39484943  START        39484936252     982001705         6.7
  46      39485742  ARM          39485736170     982801620         5.8
  47      39485945  START        39485936252     983001699         8.7
  48      39486744  ARM          39486736171     983801613         7.8
  49      39486942  START        39486936252     984001693         5.7
  50      39487741  ARM          39487736172     984801607         4.8
  51      39487943  START        39487936249     985001687         6.8
  52      39488743  ARM          39488736166     985801601         6.8
  53      39488942  START        39488936252     986001680         5.7
  54      39489742  ARM          39489736171     986801595         5.8
  55      39489943  START        39489936252     987001674         6.7
  56      39490742  ARM          39490736172     987801588         5.8
  57      39490943  START        39490936251     988001668         6.7
  58      39491744  ARM          39491736174     988801582         7.8
  59      39491944  START        39491936250     989001661         7.8
  60      39492750  ARM          39492736167     989801576        13.8
  61      39492955  START        39492936253     990001655        18.7
  62      39493742  ARM          39493736161     990801569         5.8
  63      39493945  START        39493936254     991001649         8.7
  64      39494742  ARM          39494736173     991801563         5.8
  65      39494944  START        39494936253     992001642         7.7
  66      39495742  ARM          39495736171     992801557         5.8
  67      39495943  START        39495936250     993001636         6.8
  68      39496742  ARM          39496736172     993801550         5.8
  69      39496947  START        39496936254     994001630        10.7
  70      39497743  ARM          39497736170     994801544         6.8
  71      39497944  START        39497936249     995001623         7.8
  72      39498741  ARM          39498736168     995801538         4.8
  73      39498944  START        39498936249     996001617         7.8
  74      39499741  ARM          39499736174     996801531         4.8
  75      39499943  START        39499936246     997001611         6.8
  76      39500743  ARM          39500736174     997801525         6.8
  77      39500974  START        39500936254     998001604        37.7
  78      39501744  ARM          39501736174     998801519         7.8
  79      39501944  START        39501936255     999001598         7.7
  80      39502744  ARM          39502736173     999801512         7.8
  81      39502943  START        39502936255    1000001592         6.7
  82      39503743  ARM          39503736173    1000801506         6.8
  83      39503942  START        39503936247    1001001585         5.8
  84      39504744  ARM          39504736173    1001801500         7.8
  85      39504942  START        39504936250    1002001579         5.8
  86      39505742  ARM          39505736174    1002801493         5.8
  87      39505943  START        39505936256    1003001573         6.7
  88      39506746  ARM          39506736174    1003801487         9.8
  89      39506943  START        39506936256    1004001566         6.7
  90      39507741  ARM          39507736173    1004801485         4.8
  91      39507943  START        39507936254    1005001560         6.7
  92      39508743  ARM          39508736175    1005801474         6.8
  93      39508945  START        39508936256    1006001554         8.7
  94      39509745  ARM          39509736175    1006801468         8.8
  95      39509943  START        39509936255    1007001547         6.7
  96      39510745  ARM          39510736176    1007801462         8.8
  97      39510945  START        39510936255    1008001541         8.7
  98      39511744  ARM          39511736175    1008801455         7.8
  99      39511945  START        39511936256    1009001535         8.7
 100      39512741  ARM          39512736174    1009801449         4.8
 101      39512942  START        39512936257    1010001528         5.7
 102      39513741  ARM          39513736169    1010801442         4.8
 103      39513946  START        39513936255    1011001522         9.7
 104      39514744  ARM          39514736176    1011801436         7.8
 105      39514942  START        39514936256    1012001515         5.7
 106      39515742  ARM          39515736176    1012801430         5.8
 107      39515943  START        39515936256    1013001509         6.7
 108      39516741  ARM          39516736175    1013801423         4.8
 109      39516943  START        39516936255    1014001503         6.7
 110      39517743  ARM          39517736176    1014801417         6.8
 111      39517943  START        39517936251    1015001496         6.7
 112      39518742  ARM          39518736176    1015801411         5.8
 113      39518945  START        39518936255    1016001490         8.7
 114      39519745  ARM          39519736171    1016801404         8.8
 115      39519944  START        39519936254    1017001485         7.7
 116      39520742  ARM          39520736174    1017801398         5.8
 117      39520943  START        39520936255    1018001477         6.7
 118      39521744  ARM          39521736176    1018801391         7.8
 119      39521947  START        39521936256    1019001471        10.7
 120      39522752  ARM          39522736174    1019801385        15.8
 121      39522944  START        39522936257    1020001464         7.7
 122      39523744  ARM          39523736172    1020801379         7.8
 123      39523944  START        39523936255    1021001458         7.7
 124      39524741  ARM          39524736169    1021801372         4.8
 125      39524943  START        39524936257    1022001452         6.7
 126      39525742  ARM          39525736172    1022801366         5.8
 127      39525943  START        39525936256    1023001445         6.7
 128      39526744  ARM          39526736176    1023801359         7.8
 129      39526950  START        39526936253    1024001439        13.7
 130      39527744  ARM          39527736177    1024801353         7.8
 131      39527944  START        39527936253    1025001432         7.7
 132      39528742  ARM          39528736177    1025801347         5.8
 133      39528943  START        39528936256    1026001426         6.7
 134      39529741  ARM          39529736170    1026801340         4.8
 135      39529942  START        39529936252    1027001420         5.7
 136      39530742  ARM          39530736176    1027801334         5.8
 137      39530946  START        39530936258    1028001413         9.7
 138      39531742  ARM          39531736171    1028801327         5.8
 139      39531942  START        39531936258    1029001407         5.7
 140      39532742  ARM          39532736171    1029801321         5.8
 141      39532943  START        39532936251    1030001400         6.7
 142      39533744  ARM          39533736178    1030801315         7.8
 143      39533942  START        39533936258    1031001394         5.7
 144      39534743  ARM          39534736172    1031801308         6.8
 145      39534943  START        39534936253    1032001388         6.7
 146      39535742  ARM          39535736178    1032801302         5.8
 147      39535942  START        39535936257    1033001381         5.7
 148      39536743  ARM          39536736177    1033801295         6.8
 149      39536944  START        39536936258    1034001375         7.7
 150      39537741  ARM          39537736178    1034801289         4.8
 151      39537942  START        39537936257    1035001368         5.7
 152      39538742  ARM          39538736174    1035801282         5.8
 153      39538946  START        39538936257    1036001362         9.7
 154      39539748  ARM          39539736177    1036801276        11.8
 155      39539943  START        39539936258    1037001355         6.7
 156      39540743  ARM          39540736176    1037801270         6.8
 157      39540943  START        39540936177    1038001349         6.8
 158      39541741  ARM          39541736175    1038801263         4.8
 159      39541943  START        39541936259    1039001343         6.7
 160      39542742  ARM          39542736178    1039801257         5.8
 161      39542942  START        39542936258    1040001336         5.7
 162      39543742  ARM          39543736178    1040801250         5.8
 163      39543950  START        39543936257    1041001330        13.7
 164      39544742  ARM          39544736178    1041801244         5.8
 165      39544943  START        39544936257    1042001323         6.7
 166      39545741  ARM          39545736170    1042801237         4.8
 167      39545943  START        39545936252    1043001317         6.7
 168      39546741  ARM          39546736178    1043801231         4.8
 169      39546943  START        39546936256    1044001310         6.7
 170      39547742  ARM          39547736177    1044801225         5.8
 171      39547943  START        39547936259    1045001304         6.7
 172      39548742  ARM          39548736177    1045801218         5.8
 173      39548943  START        39548936258    1046001298         6.7
 174      39549741  ARM          39549736176    1046801212         4.8
 175      39549943  START        39549936257    1047001291         6.7
 176      39550743  ARM          39550736172    1047801205         6.8
 177      39550942  START        39550936259    1048001285         5.7
 178      39551744  ARM          39551736179    1048801199         7.8
 179      39551943  START        39551936257    1049001278         6.7
 180      39552741  ARM          39552736174    1049801192         4.8
 181      39552942  START        39552936257    1050001272         5.7
 182      39553744  ARM          39553736174    1050801186         7.8
 183      39553943  START        39553936256    1051001265         6.7
 184      39554741  ARM          39554736178    1051801179         4.8
 185      39554944  START        39554936256    1052001259         7.7
 186      39555742  ARM          39555736176    1052801173         5.8
 187      39555943  START        39555936258    1053001252         6.7
 188      39556748  ARM          39556736177    1053801167        11.8
 189      39556943  START        39556936259    1054001246         6.7
 190      39557742  ARM          39557736177    1054801160         5.8
 191      39557944  START        39557936253    1055001241         7.7
 192      39558741  ARM          39558736177    1055801154         4.8
 193      39558943  START        39558936255    1056001233         6.7
 194      39559743  ARM          39559736177    1056801147         6.8
 195      39559945  START        39559936260    1057001227         8.7
 196      39560743  ARM          39560736172    1057801141         6.8
 197      39560946  START        39560936257    1058001220         9.7
 198      39561742  ARM          39561736179    1058801134         5.8
 199      39561942  START        39561936256    1059001214         5.7

-- ARM (n=100) --
  mean        6.7 ms
  median      5.8 ms
  stdev       2.0 ms
  min         4.8 ms
  max        15.8 ms
  p90         8.8 ms
  p95        11.8 ms
  p99        15.8 ms

-- START (n=100) --
  mean        8.2 ms
  median      6.7 ms
  stdev       3.9 ms
  min         5.7 ms
  max        37.7 ms
  p90        10.8 ms
  p95        13.8 ms
  p99        37.7 ms

-- all (n=200) --
  mean        7.4 ms
  median      6.7 ms
  stdev       3.2 ms
  min         4.8 ms
  max        37.7 ms
  p90         9.8 ms
  p95        13.7 ms
  p99        18.8 ms

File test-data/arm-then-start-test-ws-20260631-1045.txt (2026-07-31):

#[39462745] [WS] DATA from 192.168.0.6 body={"gate_id":"UNKNOWN","event":"ARM","tsf_us":39462736526,"gate_us":959802122}
#[39462950] [WS] DATA from 192.168.0.6 body={"gate_id":"UNKNOWN","event":"START","tsf_us":39462936246,"gate_us":960001841}
#[39463742] [WS] DATA from 192.168.0.6 body={"gate_id":"UNKNOWN","event":"ARM","tsf_us":39463736165,"gate_us":960801757}
#[39463945] [WS] DATA from 192.168.0.6 body={"gate_id":"UNKNOWN","event":"START","tsf_us":39463936241,"gate_us":961001835}
#[39464741] [WS] DATA from 192.168.0.6 body={"gate_id":"UNKNOWN","event":"ARM","tsf_us":39464736165,"gate_us":961801749}
#[39464942] [WS] DATA from 192.168.0.6 body={"gate_id":"UNKNOWN","event":"START","tsf_us":39464936242,"gate_us":962001829}
#[39465742] [WS] DATA from 192.168.0.6 body={"gate_id":"UNKNOWN","event":"ARM","tsf_us":39465736164,"gate_us":962801743}
#[39465945] [WS] DATA from 192.168.0.6 body={"gate_id":"UNKNOWN","event":"START","tsf_us":39465936247,"gate_us":963001823}
#[39466741] [WS] DATA from 192.168.0.6 body={"gate_id":"UNKNOWN","event":"ARM","tsf_us":39466736165,"gate_us":963801737}
#[39466945] [WS] DATA from 192.168.0.6 body={"gate_id":"UNKNOWN","event":"START","tsf_us":39466936246,"gate_us":964001817}
#[39467742] [WS] DATA from 192.168.0.6 body={"gate_id":"UNKNOWN","event":"ARM","tsf_us":39467736166,"gate_us":964801731}
#[39467943] [WS] DATA from 192.168.0.6 body={"gate_id":"UNKNOWN","event":"START","tsf_us":39467936240,"gate_us":965001811}
#[39468744] [WS] DATA from 192.168.0.6 body={"gate_id":"UNKNOWN","event":"ARM","tsf_us":39468736167,"gate_us":965801725}
#[39468945] [WS] DATA from 192.168.0.6 body={"gate_id":"UNKNOWN","event":"START","tsf_us":39468936243,"gate_us":966001805}
#[39469743] [WS] DATA from 192.168.0.6 body={"gate_id":"UNKNOWN","event":"ARM","tsf_us":39469736166,"gate_us":966801719}
#[39469947] [WS] DATA from 192.168.0.6 body={"gate_id":"UNKNOWN","event":"START","tsf_us":39469936248,"gate_us":967001798}
#[39470744] [WS] DATA from 192.168.0.6 body={"gate_id":"UNKNOWN","event":"ARM","tsf_us":39470736167,"gate_us":967801713}
#[39470945] [WS] DATA from 192.168.0.6 body={"gate_id":"UNKNOWN","event":"START","tsf_us":39470936248,"gate_us":968001792}
#[39471742] [WS] DATA from 192.168.0.6 body={"gate_id":"UNKNOWN","event":"ARM","tsf_us":39471736169,"gate_us":968801707}
#[39471948] [WS] DATA from 192.168.0.6 body={"gate_id":"UNKNOWN","event":"START","tsf_us":39471936246,"gate_us":969001786}
#[39472741] [WS] DATA from 192.168.0.6 body={"gate_id":"UNKNOWN","event":"ARM","tsf_us":39472736168,"gate_us":969801701}
#[39472946] [WS] DATA from 192.168.0.6 body={"gate_id":"UNKNOWN","event":"START","tsf_us":39472936241,"gate_us":970001780}
#[39473742] [WS] DATA from 192.168.0.6 body={"gate_id":"UNKNOWN","event":"ARM","tsf_us":39473736164,"gate_us":970801694}
#[39473942] [WS] DATA from 192.168.0.6 body={"gate_id":"UNKNOWN","event":"START","tsf_us":39473936248,"gate_us":971001774}
#[39474743] [WS] DATA from 192.168.0.6 body={"gate_id":"UNKNOWN","event":"ARM","tsf_us":39474736168,"gate_us":971801688}
#[39474955] [WS] DATA from 192.168.0.6 body={"gate_id":"UNKNOWN","event":"START","tsf_us":39474936249,"gate_us":972001768}
#[39475750] [WS] DATA from 192.168.0.6 body={"gate_id":"UNKNOWN","event":"ARM","tsf_us":39475736169,"gate_us":972801682}
#[39475944] [WS] DATA from 192.168.0.6 body={"gate_id":"UNKNOWN","event":"START","tsf_us":39475936248,"gate_us":973001761}
#[39476744] [WS] DATA from 192.168.0.6 body={"gate_id":"UNKNOWN","event":"ARM","tsf_us":39476736168,"gate_us":973801676}
#[39476947] [WS] DATA from 192.168.0.6 body={"gate_id":"UNKNOWN","event":"START","tsf_us":39476936250,"gate_us":974001755}
#[39477741] [WS] DATA from 192.168.0.6 body={"gate_id":"UNKNOWN","event":"ARM","tsf_us":39477736168,"gate_us":974801670}
#[39477942] [WS] DATA from 192.168.0.6 body={"gate_id":"UNKNOWN","event":"START","tsf_us":39477936249,"gate_us":975001749}
#[39478743] [WS] DATA from 192.168.0.6 body={"gate_id":"UNKNOWN","event":"ARM","tsf_us":39478736167,"gate_us":975801663}
#[39478945] [WS] DATA from 192.168.0.6 body={"gate_id":"UNKNOWN","event":"START","tsf_us":39478936249,"gate_us":976001743}
#[39479742] [WS] DATA from 192.168.0.6 body={"gate_id":"UNKNOWN","event":"ARM","tsf_us":39479736168,"gate_us":976801657}
#[39479951] [WS] DATA from 192.168.0.6 body={"gate_id":"UNKNOWN","event":"START","tsf_us":39479936248,"gate_us":977001737}
#[39480744] [WS] DATA from 192.168.0.6 body={"gate_id":"UNKNOWN","event":"ARM","tsf_us":39480736170,"gate_us":977801651}
#[39480942] [WS] DATA from 192.168.0.6 body={"gate_id":"UNKNOWN","event":"START","tsf_us":39480936249,"gate_us":978001730}
#[39481741] [WS] DATA from 192.168.0.6 body={"gate_id":"UNKNOWN","event":"ARM","tsf_us":39481736171,"gate_us":978801645}
#[39481944] [WS] DATA from 192.168.0.6 body={"gate_id":"UNKNOWN","event":"START","tsf_us":39481936249,"gate_us":979001724}
#[39482741] [WS] DATA from 192.168.0.6 body={"gate_id":"UNKNOWN","event":"ARM","tsf_us":39482736170,"gate_us":979801638}
#[39482944] [WS] DATA from 192.168.0.6 body={"gate_id":"UNKNOWN","event":"START","tsf_us":39482936250,"gate_us":980001718}
#[39483746] [WS] DATA from 192.168.0.6 body={"gate_id":"UNKNOWN","event":"ARM","tsf_us":39483736170,"gate_us":980801632}
#[39483943] [WS] DATA from 192.168.0.6 body={"gate_id":"UNKNOWN","event":"START","tsf_us":39483936252,"gate_us":981001712}
#[39484742] [WS] DATA from 192.168.0.6 body={"gate_id":"UNKNOWN","event":"ARM","tsf_us":39484736172,"gate_us":981801626}
#[39484943] [WS] DATA from 192.168.0.6 body={"gate_id":"UNKNOWN","event":"START","tsf_us":39484936252,"gate_us":982001705}
#[39485742] [WS] DATA from 192.168.0.6 body={"gate_id":"UNKNOWN","event":"ARM","tsf_us":39485736170,"gate_us":982801620}
#[39485945] [WS] DATA from 192.168.0.6 body={"gate_id":"UNKNOWN","event":"START","tsf_us":39485936252,"gate_us":983001699}
#[39486744] [WS] DATA from 192.168.0.6 body={"gate_id":"UNKNOWN","event":"ARM","tsf_us":39486736171,"gate_us":983801613}
#[39486942] [WS] DATA from 192.168.0.6 body={"gate_id":"UNKNOWN","event":"START","tsf_us":39486936252,"gate_us":984001693}
#[39487741] [WS] DATA from 192.168.0.6 body={"gate_id":"UNKNOWN","event":"ARM","tsf_us":39487736172,"gate_us":984801607}
#[39487943] [WS] DATA from 192.168.0.6 body={"gate_id":"UNKNOWN","event":"START","tsf_us":39487936249,"gate_us":985001687}
#[39488743] [WS] DATA from 192.168.0.6 body={"gate_id":"UNKNOWN","event":"ARM","tsf_us":39488736166,"gate_us":985801601}
#[39488942] [WS] DATA from 192.168.0.6 body={"gate_id":"UNKNOWN","event":"START","tsf_us":39488936252,"gate_us":986001680}
#[39489742] [WS] DATA from 192.168.0.6 body={"gate_id":"UNKNOWN","event":"ARM","tsf_us":39489736171,"gate_us":986801595}
#[39489943] [WS] DATA from 192.168.0.6 body={"gate_id":"UNKNOWN","event":"START","tsf_us":39489936252,"gate_us":987001674}
#[39490742] [WS] DATA from 192.168.0.6 body={"gate_id":"UNKNOWN","event":"ARM","tsf_us":39490736172,"gate_us":987801588}
#[39490943] [WS] DATA from 192.168.0.6 body={"gate_id":"UNKNOWN","event":"START","tsf_us":39490936251,"gate_us":988001668}
#[39491744] [WS] DATA from 192.168.0.6 body={"gate_id":"UNKNOWN","event":"ARM","tsf_us":39491736174,"gate_us":988801582}
#[39491944] [WS] DATA from 192.168.0.6 body={"gate_id":"UNKNOWN","event":"START","tsf_us":39491936250,"gate_us":989001661}
#[39492750] [WS] DATA from 192.168.0.6 body={"gate_id":"UNKNOWN","event":"ARM","tsf_us":39492736167,"gate_us":989801576}
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

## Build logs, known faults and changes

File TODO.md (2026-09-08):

# Kronos Workspace TODO

Index of planned work across the workspace. Each sub-project keeps its own
task/planning docs; this file doesn't duplicate their content, it just
points at them and tracks the cross-project (interoperability, testing)
items that don't belong to any single sub-project.

Current focus: with the core network-timing/reliability work settled (see
`NETWORK-TIMING-LOG.md`), the shift is toward planned per-project features
and enhancements.

**What this document is, 2026-08-07.** An index of *planned* work —
features and enhancements not yet built, kept short enough to scan at a
glance. Bug fixes and external feature requests are tracked as GitHub
Issues instead, not duplicated here. Investigation history and analysis
(what was tried, what the data showed, why a decision was made) lives in
`NETWORK-TIMING-LOG.md`'s lab notebook, not here — this file links to
specific findings there rather than restating them.

---

## Open bugs / investigation gaps

Not planned-work in the sense this file otherwise tracks — these are
tracked properly in `NETWORK-TIMING-LOG.md`'s own "Outstanding work,
prioritized" section (kept up to date there, not mirrored here) and will
move to GitHub Issues going forward. 

As of 2026-08-07: 
 - GOAL board retry asymmetry under heavy stress (deferred to production-board 
 testing), 
 - the two untested congested-airtime stressor layers (bulk-throughput contention,
broadband noise — deprioritized, not formally closed), 
 - hedged burst sends for tail latency (deprioritized, watching retry telemetry).

Not a task, just a standing note: the ARES pulse generator can produce a
spurious trigger on both gates if reset while wired directly to a pair of
hesperus boards — reset it fully before starting a trial or a new log. See
[ares-pulse-generator](#ares-pulse-generator) below. Bench-test tooling
only, no bearing on production use.

---

## Cross-project planned work

- **ARGUS** (data collector/analysis layer) — not started at all. See `docs/KRONOS-SYNCHRONIZED-TIMING-GATES-ARCHITECTURE.md`.
- **Provisioning** — sensor-side mDNS discovery and Wi-Fi credential override are already implemented (`resolveCerberus()`, serial `wifi` command + NVS on hesperus); only deep-sleep power cycling and the sensor registration/auth-token handshake remain proposed. See `docs/PROVISIONING.md`, which now also has a "Recovery from Failure" section (per-scenario: what's automatic vs. needs manual action, including the known "cerberus restarts on a new IP" gap — untested, no repro yet).
- **Reliability: congestion avoidance** (exponential backoff+jitter) — proposed design only, not implemented. See `docs/RELIABILITY.md` (section 2). (`TCP_NODELAY`, formerly listed alongside this, turned out to already be enabled by default via the WebSockets/ESPAsyncWebServer library versions in use — no action needed, see that doc's section 3.)

---

## ALL boards

 - Add non volatile run logs. Cerberus can use an SD card. Hesperus can easily store perhaps 8000 runs at full logging

## cerberus-gate-controller

Full list: **`cerberus-gate-controller/docs/PLANNED-UPDATES.md`** —
supervisor state machine, SD-card CSV logging, HTTP log streaming/
MAINTENANCE mode, `race_runs[]` concurrency guard.

## hesperus-timing-gate

Full list: **`hesperus-timing-gate/docs/review.md`**'s "Future Development Path"
table — Wi-Fi modem sleep, NVS config store, configurable confirm-sample
count, OTA update, SSD1306 display, stack telemetry, NVS event buffering,
multi-AP BSSID fallback, local standalone scoring.

## ares-pulse-generator

- **Note, not an open task** (removed from the priorities list 2026-08-07):
  resetting the ARES board while wired directly to a pair of hesperus
  boards can produce a spurious trigger glitch on both gates. Just make
  sure the board has fully reset before starting a trial or a new log —
  ARES is bench-test tooling only, this has no bearing on production use.
  (originally noted 2026-08-02)
- Now that hesperus's `base_s3_zero`/`base_s3_super_mini` boards detect
  beam-breaks via the analogue dual-EMA path (`beam-sensor.h`, 2026-08-30)
  instead of the digital `GATE_PIN_A`/`GATE_PIN_B` interrupt path, ARES's
  digital pulse output can no longer trigger those boards directly. Design
  for an analogue-equivalent test-signal path (pull-up + MOSFET tap, or
  direct substitution with the phototransistor disconnected) is written up
  in `hesperus-timing-gate/docs/detection-mechanism.md`'s "Bench stimulus
  injection" section — not yet built on real hardware.

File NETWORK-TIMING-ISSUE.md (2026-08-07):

# Network Timing Issue: Observations, Resolutions, and Outstanding Work

Date: 2026-07-30. Restructured 2026-07-31 — see "Restructuring note" at the
bottom for what changed and why.

## Context

`hesperus-timing-gate` boards report race events (`ARM`, `START`, `GOAL`) to
`cerberus-gate-controller`, with disciplined Wi-Fi-TSF-based microsecond
timestamps carried in the payload. Transport was originally per-event HTTP
(`POST /api/event`); a persistent WebSocket connection (`/ws`) was added
during this investigation and is now the default (see the first issue
below). Bench testing the two boards together (a start board and a goal
board, both clients of a single cerberus controller) surfaced a chain of
related issues in network latency, its effect on displayed race times, and
its effect on race-result correctness. This document records what was
found, why it happens, what's been done about it, and what's still open.

Bench-testing tools referenced throughout (`ares-pulse-generator`'s
`trial_*` functions, `ws_send_event.py`, `cerberus_log_stats.py`, etc.) are
catalogued in `docs/TEST-TOOLING.md` — that doc covers what each tool does
and how to invoke it; this doc only references them by name.

## Acceptance criteria for beacon-spam stress testing

Decided 2026-08-03, after three stress-test sessions (see the beacon-spam
issues below): any lost timing event is a broken system by acceptance-testing
standards, but demanding that in *every conceivable* radio environment isn't
realistic — a pass/fail line has to be drawn somewhere, and where matters
because the stress-test protocol (15 runs no spammer, 15 with one spammer,
then a second spammer added) exercises two very different threat levels in
one script:

- **One beacon spammer is extreme, but not adversarial.** The tool itself is
  nominally an attack device, but the load one produces is plausibly in the
  same range a busy exhibition hall's own ordinary infrastructure could
  generate organically (dozens of exhibitor/vendor APs each beaconing at the
  standard rate — see the SSID-density estimate under the outstanding-work
  item below). It's a severe environment, not a hostile one: nothing about
  it requires a deliberate actor. **This is the pass/fail bar.**
- **Two simultaneous spammers (~1000 beacon frames/sec combined) is
  adversarial** — that combination of severity *and* deliberate placement
  (both devices parked right next to the gate at full signal strength) is
  well beyond what a venue's own organic traffic would reproduce; it
  requires someone deliberately trying to disrupt the system. Every radio on
  the channel still has to process each beacon frame at the hardware/MAC
  level regardless of payload, which is why it hits the ESP32's software
  WiFi stack disproportionately hard (see the `wsClient.loop()`-blocking
  issue below) even though a laptop on the same air noticed nothing. Treated
  as a **smoke test** (does the system degrade gracefully and recover
  automatically, without crashing or corrupting a result) rather than a
  pass/fail gate — zero-loss under deliberate, sustained ~1000fps beacon
  flooding is not a requirement.

**Single-spammer result so far: passes cleanly.** Isolating each stress
session's no-spammer + single-spammer phase (everything before the first
`Resent` line, which lines up almost exactly with the 15+15-run protocol)
and checking committed vs. armed+started: session 3, 29/30 (the one gap is
the session's very first run, a cold-start artifact, not spammer-induced);
session 4, 31/31; session 5, 29/30 (the one gap is the *last* run before
cutoff, whose `GOAL` landed 131ms after the first `Resent` — caught by the
onset of the second spammer, not a failure during clean single-spammer
running). **Zero genuine single-spammer losses across all three
independent sessions** once the cold-start and cutoff-boundary artifacts are
excluded. This held both before and after the 2026-08-03 retry-schedule
mitigation (session 5's session-3-era predecessor already passed too) — the
retry/deadline logic never even engages during single-spammer running (no
`Resent` lines appear until the second spammer goes on), so that mitigation
is aimed entirely at the smoke-test scenario, not the pass bar.

**Practical implication**: further tuning effort aimed specifically at the
two-spammer case (chasing its ~2-3% residual loss, or side-effects like the
`networkQueue`/`ledQueue` overflow seen in session 5) is lower priority than
confirming single-spammer robustness more rigorously — larger sample sizes,
and the more realistic congested-airtime conditions sketched in outstanding-
work item 5 below, rather than continuing to optimize against a scenario
this system isn't required to survive losslessly.

**Large-N no-spammer baseline, 2026-08-03** (`test-data/spam-tests/
{cerberus-6,hesperus-start-6,hesperus-goal-6}.log`, 5000-run trial, no
spammer — the first of a planned pair, single-spammer counterpart still to
come): **5000/5000 ARM, START, and GOAL, zero retries, zero drops, zero
queue overflow, one single WS disconnect/reconnect across the entire
~6-hour test.** A perfect result, as expected for the no-spammer condition,
and a clean baseline to compare the equivalent single-spammer 5000-run trial
against once it's run. (Session did produce one unrelated curiosity ~64-84
minutes after the last logged race, well outside the trial itself — see the
"AP radio interruption" issue's 2026-08-03 addendum below.)

**Planned next steps, 2026-08-03.** The AP has been deliberately placed some
distance from the gates for this round of testing — typical reported `rssi`
sits around -70 to -80dBm, a genuinely weak-to-marginal link (rough rule of
thumb: -50 to -60dBm is good, -60 to -70 usable, -70 to -80 is where 802.11
MAC-layer retransmission rates start climbing on their own, independent of
any beacon-storm software overhead). `rssi` is already carried in every
event payload, so no new instrumentation is needed:

1. Once the current single-spammer 5000-run trial (session 6's counterpart)
   finishes, cross-reference retry/drop occurrences against the `rssi`
   values of the events involved, to check whether failures cluster at the
   low end of the -70/-80dBm range (pointing at marginal signal margin as a
   contributing factor) or look independent of it (supporting the
   beacon-frame-count-overhead theory on its own, per the `wsClient.loop()`
   issue above).
   - **Unconfirmed hunch to check alongside this**: the user suspects their
     own physical position near the test rig during the first ~1000 or so
     runs may itself have been attenuating `rssi` (body blocking
     line-of-sight to the AP), an effect that would fade once they stepped
     away for the remainder of the multi-hour unattended run. Flagged as
     possibly fanciful, not asserted — the way to check it is the plot
     below, not assumption.
   - **Known extra confound, same window**: for this specific trial, the
     user's own BT headphones were also streaming audio within a couple of
     feet of the rig during roughly that same first ~1000 runs, on top of
     the body-proximity hunch above. Mechanistically different from the
     beacon-spam issue this doc otherwise tracks — BT interference would
     show up as ordinary co-channel RF collision/corruption (raised noise
     floor, standard 802.11 MAC retransmissions), not the CPU/management-
     frame-processing overhead the beacon-storm issues are about — so if the
     first ~1000 runs do look worse, it's confounded between body position
     and BT and not attributable to either alone. The following ~2 hours of
     the same trial should be free of both. Noted for the record because
     good experiment hygiene means tracking every condition in play, even
     ones that turn out not to matter.
   - **Curiosity plot, not a formal requirement**: average `rssi` vs. time
     (or run index) across the trial, per board, to see whether there's a
     visible early-run dip/trend consistent with the hunch above, independent
     of the retry/drop correlation in point 1.
2. Afterwards, the AP will be moved to give an `rssi` more representative of
   the planned deployment environment, and the **exact same trial protocol
   re-run** for a direct comparison against the current (deliberately weak
   signal) baseline.

**Results, session 7 (2026-08-03)** — from the single-spammer 5000-run trial
before it was cut short by the ISR/TSF crash bug above (~2882 armed+started
runs completed, 2881 committed, only 1 true loss — see that issue for the
crash itself):

- **RSSI level does not predict retries.** Joining each hesperus-side send
  record to its cerberus-side `rssi` (ordered join per board/event-type,
  tolerant of the one dropped `GOAL`): mean `rssi` for events that needed a
  retry is statistically indistinguishable from events that didn't (ARM:
  -74.9 vs -75.0dBm; START: -75.3 vs -75.0; GOAL: -72.8 vs -73.0). Within
  the -66 to -82dBm range actually seen, `rssi` level itself isn't
  predictive of which specific events fail.
- **Time is a much stronger predictor.** Binning retries by run index:
  ARM retries ran 2.75% in runs 0-800 vs. 0.14% in runs 800-3000 (~20x
  lower); GOAL retries ran 4.5% vs. 0.55% (~8x lower). Essentially all
  retry activity — and the one genuine drop, at run 252 (~20.6 minutes in)
  — falls inside the first ~800-1000 runs (~1-1.2 hours), matching the
  body-position/BT-headphones confound window flagged before this trial.
  The remaining ~2000 runs were close to flawless.
- **This actually points more at the BT headphones specifically than body
  position.** Average `rssi` stayed flat through the early window (no dip)
  — `rssi` measures the WiFi AP signal's own strength, not ambient
  interference, so a body attenuating line-of-sight *would* show up as
  reduced `rssi`; BT co-channel interference degrades packet success
  *without* touching the `rssi` reading at all. Retries elevated with
  `rssi` flat fits "something interfering" better than "something
  attenuating." Not proven (no confound-free control run to compare
  against directly), but a coherent, self-consistent reading of the data.
- Curiosity plot (average `rssi` vs. run index) done as part of the above
  rather than as a separate artifact — see the binned figures; no visible
  early-run dip, per the point above.

**Results, session 8 (2026-08-04)** — the AP-repositioned, confound-free
single-spammer 5000-run trial planned above
(`test-data/spam-tests/{cerberus-8,hesperus-start-8,hesperus-goal-8}.log`),
run to completion (no crash cutoff this time):

- **ISR/TSF crash fix hardware-verified.** Zero panics, zero reboots, on
  both boards, across the full ~6.53-hour, ~5346-run trial under the same
  sustained single-spammer load that surfaced the bug in session 7. See the
  issue below — now marked resolved.
- **Realistic-deployment RSSI, as intended.** Mean `rssi` -65.8dBm (range
  -56 to -76dBm), a clear improvement over session 7's deliberately-weak
  -66 to -82dBm/mean ~-75dBm baseline, confirming the AP repositioning
  worked.
- **Retries near-zero, and — the key check — no longer front-loaded.** Only
  5 distinct events needed a retry out of 16,034 total (0.03%), identified
  via cerberus-side duplicate receipts of the same `tsf_us`. Binned across
  the full trial: **zero retries in the first ~2 hours**, the few that
  occurred fall in hours ~2-4.4, none after. This is the confound-free
  control session 7 lacked: with the body-position/BT-headphones confound
  genuinely absent this time, retries do not show the ~20x/~8x early-window
  spike session 7 saw — supporting the session-7 reading that that spike
  was confound-driven, not RSSI- or time-of-trial-driven. RSSI level still
  isn't predictive of which events retry (e.g. ARM: -67.0dBm retried vs.
  -66.8dBm clean, statistically indistinguishable).
- **Item 1 (ack-path) recurred once, same signature as before.** A burst at
  T≈14.09-14.13M ms: three ARM events needed retries within a 40-second
  window, one needing 9 attempts before succeeding. Cerberus's `[WS-ACK]`
  fired within 3-8ms on every single delivery (again ruling out "cerberus
  is slow"), yet hesperus didn't recognise the ack in time — consistent
  with item 1's still-open two candidate causes, not yet distinguished
  further by this session.
- **Race outcome, once one operator-caused artifact is excluded (confirmed
  with the user, see below): effectively lossless.** Start board
  armed+started 5346 runs; cerberus received 5345 of the ARM+START pairs
  over the network (the one gap lines up exactly with the artifact below);
  goal board sent 5344 GOALs (2 runs left incomplete by the same artifact),
  and cerberus received all 5344 of them — **zero GOAL-side network loss**.
- **Explained anomaly, not a bug.** At T≈2.6M ms (~43 minutes in), both
  hesperus boards and cerberus went completely silent simultaneously for
  ~8.7 minutes (no sends, no receipts, no crash/reboot/disconnect logged by
  any of the three) before resuming cleanly — 2 runs left incomplete (armed
  and started, no GOAL), one of which also never reached cerberus at all.
  **Confirmed with the user**: this was a deliberate mid-trial adjustment,
  with the log not reset before resuming — which also explains the run
  count landing at ~5346 rather than the nominal 5000. Excluded as an
  operator artifact, same treatment as the cold-start/cutoff artifacts
  excluded in sessions 3-5; not a system fault. One of the goal board's
  `[AUDIT ALERT] Temporal Disruption!` self-corrections (see the "AP radio
  interruption" issue's recurrence note) lands at the exact resume instant
  and is fully explained by it (a large TSF gap after 8+ minutes without a
  fresh sample). The other 6 (5 goal-board, 1 start-board) occur during
  otherwise-normal running with no nearby gap — each a single rejected
  sample, immediately self-corrected, no operational impact — extending the
  session-6 recurrence note: this now happens during active running too,
  not just post-trial idle. Still unexplained, still low-priority and
  self-healing.

## Outstanding work, prioritized

1. **[Acks not arriving back at hesperus in time](#issue-acks-not-arriving-back-at-hesperus-in-time-despite-cerberus-receiving-the-event)**
   — **[RESOLVED, tuning applied 2026-08-04, not yet hardware-verified.]**
   End-to-end instrumentation on both boards (cerberus's `pending`/`space`,
   hesperus's `[WS-ACK-RECV]` receive timestamp, both on the shared TSF
   clock) traced all 10 retried events in a two-spammer+BT marginal trial
   start to finish: **every one of them was the original ack arriving
   fine, just with a round trip (258-458ms) that happened to exceed
   hesperus's fixed ~300ms per-attempt timeout.** Not loss, not a stack
   stall on either side (ruled out via `wsPumpTask`'s own blocking canary,
   which fired only once in the whole trial and didn't line up with any of
   the 10), not asymmetric (both legs contribute comparably) — ordinary
   bidirectional jitter under heavy interference, occasionally summing
   past a fixed timeout, most likely at the WiFi MAC layer itself given
   both boards' software was cleared. Retry/dedup already handled it
   correctly throughout (zero data loss in any session this showed up in),
   and it only ever appeared under the explicitly-adversarial two-spammer
   smoke test, not the single-spammer pass bar (0.03% retry rate there).
   **`WS_ACK_TIMEOUT_MS` raised 300→500ms** (jitter and
   `WS_ACK_OVERALL_DEADLINE_MS` scaled proportionally alongside it, so
   `WS_MAX_SEND_ATTEMPTS`'s retry depth for genuine loss isn't quietly
   reduced) rather than the previously-considered redundant-ack-burst
   mitigation, which was built around a loss model this data doesn't
   support. Build-verified; next step is a session-9/10-style marginal
   trial confirming the retry count drops **under `NONE`** — session 13
   (2026-08-05) ran the harsher two-spammer+BT combination but under
   `MIN_MODEM`, so it doesn't isolate this fix cleanly (see item 2); the
   forward-leg delivery held up well there regardless (every genuinely
   transmitted event eventually reached cerberus), which is a good sign
   but not the controlled re-run this item still needs. **Session 15**
   (2026-08-06) attempted this under `NONE` but one spammer dropped out
   ~30 minutes in (equipment issue, not a finding) — both segments'
   retry rates looked healthy, but it's suggestive, not the clean
   confirmation this item needs. **Session 15a** (2026-08-06, the planned
   3000-run re-run) was *also* compromised — BT was found off partway
   through, back on at a known timestamp — but showed sustained stress
   throughout regardless, with overall retry rates (1.46%/9.47%) well
   under session 13's `MIN_MODEM` baseline (4.0%/18.3%) over a comparable
   exposure. Two compromised trials in a row is enough supportive signal
   to lower this item's urgency, but a genuinely clean confound-free run
   still hasn't happened. **Session 16 (2026-08-07) is that clean run**:
   full 5000-run, ~5.97h two-spammer+BT trial under `NONE`, both spammers
   and BT confirmed continuous throughout, no equipment confound. Retry
   rates 4.15%/10.32% (ARM/START vs. GOAL) — of the 923 events that needed
   at least one retry, only 8 exhausted all retries (99.1% recovered).
   **Confirms the fix**: the widened timeout is doing real work under
   sustained real adversarial load, not just the shorter/compromised
   trials this item was leaning on before. Full per-event round-trip
   tracing (the session 9/10-style breakdown showing *why* each retry
   happened) wasn't repeated for this session — the aggregate recovery
   rate is the evidence here, not a re-derivation of the mechanism, which
   sessions 9/10 already established. Full detail in the issue below.
2. **[Wi-Fi power-save vs. battery budget](#issue-wi-fi-power-save-vs-battery-budget)**
   — Measure current draw across `WIFI_PS_NONE`/`MIN_MODEM`/`MAX_MODEM`
   with persistent connections in place. Real, measured 110mA cost today;
   the thing this was explicitly deferred pending (persistent connections)
   has now landed, so this is unblocked. **Decision, 2026-08-04: `NONE`
   stays the shipped default regardless of what the overnight trial
   below shows.** Session 11 found a real, if not-yet-fully-explained,
   `MIN_MODEM` reliability regression (see the issue below); a clean
   overnight repeat wouldn't be enough to overturn that — absence of a
   recurrence in one more trial is not evidence of absence of a rare tail
   risk, and the asymmetry between "run `NONE` at higher power
   indefinitely" and "have an outage during a real contest" clearly favours
   caution. The overnight trial is now diagnostic-only (does the mechanism
   recur, at what rate), not a pass/fail gate for adoption — `MIN_MODEM`
   would need to be root-caused, fixed, and *then* re-verified extensively
   before this decision would be revisited. **Update, 2026-08-05**: session
   12 (single-spammer repeat) showed zero recurrence; session 13
   (two-spammer+BT smoke test) showed the mechanism recurring twice in one
   trial — occurrence count now tracks stress severity directly (0/1/2
   across sessions 12/11/13), which is itself evidence for a genuine
   mechanism rather than coincidence. **Update, same day**: the candidate
   fix (widen `enableHeartbeat()`'s pong-timeout/miss-count) was applied
   and tested (session 14) — it made every measure dramatically worse
   (drops, stalls, disconnects, stale-GOALs, retry rates all 2-136x worse
   per hour than session 13's unmodified baseline), not better. Reverted.
   The mechanism remains unexplained and unmitigated; this specific
   direction (widen tolerance) is now ruled out, not just untried — any
   future attempt needs a different theory of the failure. **Update,
   2026-08-06**: session 15 (`NONE`, same nominal two-spammer+BT stress)
   compromised by a spammer dropping out ~30 minutes in, but the ~30
   minutes of genuine exposure it did get showed no stall approaching the
   5000ms signature that defines the `MIN_MODEM` mechanism — suggestive
   that it's `MIN_MODEM`-specific, on weaker evidence (30min vs. 6h) than
   the recurrence finding it's being weighed against. **Revised, same
   day**: session 15a (the planned clean re-run, also compromised — BT
   found off partway through) recorded one genuine **5002ms** stall under
   `NONE` during its confirmed-no-BT period, hitting the exact
   `WEBSOCKETS_TCP_TIMEOUT` signature. **The severe cascade is not
   `MIN_MODEM`-exclusive after all** — it's a general two-spammer
   WiFi-stack-overhead property `NONE` isn't immune to, just apparently
   less frequent/severe under it (one occurrence in ~3.6h vs. repeated
   occurrences per `MIN_MODEM` trial) rather than absent. Both `NONE`
   trials to date have been confound-compromised; a genuinely clean run
   under either power mode still hasn't happened. **Session 16
   (2026-08-07) is that clean run for `NONE`**: full 5000-run, ~5.97h
   two-spammer+BT trial, both interference sources confirmed continuous
   throughout. **The 5002ms signature is not rare under `NONE` either**
   — 25 of ~~158~~ **79** (see raw-log recount, 2026-08-07, in the issue
   detail below — the 158 figure's source wasn't identified) total stalls
   landed in the 4900-5100ms band across the trial, ~~spread throughout
   rather than clustered in one window (unlike `MIN_MODEM`'s acute
   2-minute/14-15s episodes in sessions 11/13)~~ **actually clustered: ~85%
   of the large stalls fall inside one ~9.7-minute episode at the very
   start of the trial, comparable in kind to `MIN_MODEM`'s acute episodes
   just front-loaded rather than mid-run — see the corrected finding
   below.** 34 WS disconnects total (confirmed correct). Despite that,
   race outcome was 4940
   armed+started, 4911 committed (29 lost, 0.59%) — no crash, no reboot,
   no corrupted result, fully automatic recovery every time. **This is a
   clean pass of the smoke-test bar this trial was always held to**
   ("degrades gracefully and recovers automatically" — not zero-loss,
   see the acceptance-criteria section above) — the first genuinely
   confound-free confirmation that `NONE` survives the harshest tested
   condition without manual intervention. Does not overturn the
   `MIN_MODEM`-stays-unadopted decision (that was never contingent on
   `NONE`'s own smoke-test result) — it closes out the parallel question
   of whether `NONE` itself has ever been cleanly verified under this
   condition. It hadn't been; now it has.
3. **[`wsClient.loop()` blocking under congestion](#issue-wsclientloop-blocking-under-congestion-defeats-the-ackretry-deadline-bound)**
   — confirmed via instrumentation + cross-board log correlation: beacon
   spam causes real TCP-level WS disconnects (up to ~18s outages seen) on
   the hesperus side, with `wsClient.loop()` blocking up to ~9.5s per call,
   silently blowing the 2000ms ack/retry deadline bound. Not classic
   airtime saturation (a laptop held 25Mbps through the same spam) —
   likely ESP32-specific WiFi-stack overhead from beacon-frame volume.
   Undermined the already-shipped retry/dedup mechanism precisely under the
   real-world congestion it exists for. **Resolved and hardware-verified
   2026-08-03** (dedicated `wsPumpTask` + mutexes decouple the socket pump
   from the retry deadline logic) — 5/6 verification deltas landed within
   ~500ms of the 2000ms target, down from the original bug's 7.6s+
   untethered stalls. The two residual outliers are now tracked as item 1
   above, not here. Root RF-level cause (why the outages happen at all)
   remains open too, folded into item 5 below. **Proposed experiment,
   2026-08-07 (not yet run)**: session 16's raw-log recount found the
   severe stalls cluster into episodes rather than spreading evenly, with
   the fastest-onset episodes landing suspiciously close to trial start —
   but not in every session. A cheap two-trial pair (~75min total) is
   designed to isolate whether traffic-onset or connection-freshness (both
   normally coincide at trial start) is the actual trigger — see the
   dedicated write-up at the end of the issue below.
4. **[Duplicate triggers from gapped robot structure](#issue-duplicate-triggers-from-gapped-robot-structure)**
   — **[Reassessed 2026-08-07 — deprioritized, lock-out design not being
   pursued.]** The proposal's own justification (needless network pressure
   from extra events) was written under HTTP's per-event connection cost;
   this issue's own WS re-run data (200/200 arrived, ~7-8ms latency, the
   104ms queueing offset gone) already shows that premise doesn't hold
   anymore. Multiple triggers from one robot are rare in practice, and
   under WS a redundant trigger costs almost nothing to send and is already
   harmlessly ignored once out of `RUNNING` — if anything, sending
   duplicates is closer to a reliability feature (a free extra delivery
   attempt) than a problem worth suppressing at the source. Not formally
   closed (a genuinely gapped robot could still exist), just no longer the
   standing design question it was.
5. **Congested-airtime stress testing** (cross-cutting, not tied to one
   issue) — **[Judged sufficient, 2026-08-04 — deprioritized, not
   formally closed.]** The four stressor layers sketched in
   `hesperus-timing-gate/review.md`: **airtime saturation** has extensive
   coverage (beacon-spam sessions 2-10, up to two simultaneous spammers)
   and **channel interference** partial coverage (BT streaming co-tested
   alongside spammers, sessions 9-10); **bulk throughput contention** and
   **broadband noise** remain genuinely untested. Decision: given the
   system handled the harshest combination actually tested (two spammers +
   BT streaming, deliberately parked next to the gate) with zero drops,
   zero crashes, and the one real issue that surfaced (the ack-path
   timeout mismatch) understood and fixed, further chasing the two
   untested layers is diminishing returns relative to what a real contest
   venue is actually likely to produce — other exhibitors' AP
   beacon/management-frame overhead, not deliberate bulk-throughput
   hogging or broadband jamming. Not pursuing further unless a specific
   venue's known conditions give a concrete reason to.
6. **[Hedged burst sends](#issue-hedged-burst-sends-for-tail-latency)** —
   deprioritized; watch real-world retry counts/rate from the now-shipped
   ack/retry mechanism before building this. No action needed unless that
   telemetry shows frequent retries.
7. **[Unexplained minor WS jitter / reconnect blip](#issue-unexplained-minor-ws-jitter--reconnect-blip)**
   — **[Characterized and closed, 2026-08-04 — no periodic cause found.]**
   Rather than running the proposed purpose-built 10,000-message GOAL-only
   trial, used the existing confound-free 5000-run no-spammer baseline
   (session 6, `test-data/spam-tests/cerberus-6.log`) instead — 5000 real
   `GOAL` events at a uniform ~4.3s cadence, arguably a better substitute
   than the synthetic proposal since it's real protocol traffic, not
   synthetic pulses, and 5000 comfortably exceeds the proposed 10,000
   *messages* once ARM/START are counted too (this pass used `GOAL` alone
   to match the original single-event-type proposal). Latency: mean 8.8ms,
   p90 12.0ms, p95 14.6ms, p99 19.0ms, max 63.8ms; 30/5000 (0.6%) exceeded
   20ms. Checked those 30 outliers' index spacing for periodicity (the
   original leading hypothesis — "a spike every N messages, pointing at a
   fixed-period task like the heartbeat timer or a WS keepalive interval")
   — spacing is irregular (1 to 697 events apart, no repeating interval),
   ruling that out across a sample 25-50x larger than the n=100-200 that
   originally flagged this. Consistent with ordinary non-periodic
   scheduling/RF jitter, not a hidden periodic bug. The original issue's
   own caveat ("would not on its own isolate which stage the delay happens
   in") is now moot rather than resolved — sessions 8-10's ack-path work
   has since added exactly the hesperus-side send/receive timestamp this
   would have needed as a follow-up, but with no pattern found there's
   nothing left to isolate. Closed as characterized-and-benign; watch for
   recurrence rather than investigate further.
8. **[GOAL board retries far more than ARM/START board under heavy
   stress](#issue-goal-board-retries-far-more-than-armstart-board-under-heavy-stress)**
   — **[OPEN, deferred 2026-08-05]** Session 13's two-spammer+BT smoke
   test showed the GOAL board retrying 4.6x more often than the ARM/START
   board (18.3% vs. 4.0%). Cause not yet distinguished between physical
   placement and role/traffic-pattern. The planned start/goal position
   swap is deferred to the production-board testing stage — the current
   hand-wired breadboard rig has too many uncontrolled physical variables
   for a swap result to be trustworthy.

Everything else below this list is either resolved or has no further action
planned. (Explicit HTTP connect/read timeouts, formerly tracked here, turned
out to be N/A rather than just deprioritized — see the first issue below.)

## Issues

### Issue: Per-event connection latency & queueing

**[RESOLVED — persistent WebSocket connections shipped; the one remaining recommendation (explicit HTTP timeouts) is now N/A, see below]**
*(was Observations #1, #2, #3, #8; Recommendation 1, Recommendation 3)*

**Observation.** Every trigger initially produced exactly four identical
`POST /api/event` requests at cerberus, matching `MAX_HTTP_RETRIES`
precisely. Root cause: `HTTP_TIMEOUT_MS` was set to 250ms, which the real
round-trip time consistently exceeded — hesperus exhausted all four retry
attempts on every single event, even though cerberus was receiving and
correctly processing every one of them. Raising `HTTP_TIMEOUT_MS` to 2000ms
initially resolved the duplicate-POST pattern, but didn't fully explain
later data: a "confirmed" event was observed taking 2993ms — longer than
the configured 2000ms timeout, yet still succeeding. Inspecting the ESP32
Arduino `HTTPClient` source
(`framework-arduinoespressif32/libraries/HTTPClient/src/HTTPClient.cpp`)
showed why: `HTTPClient::setTimeout()` only sets `_tcpTimeout`, the
**response-read** timeout, applied only *after* a TCP connection is already
established. The TCP **connect** phase uses a separate `_connectTimeout`,
defaulting to a hardcoded `HTTPCLIENT_DEFAULT_TCP_TIMEOUT = 5000`
(`HTTPClient.h:42`) that nothing in the firmware had ever configured — so
tuning `HTTP_TIMEOUT_MS` never bounded the dominant source of latency at
all.

Both boards were given TSF-based (`esp_wifi_get_tsf_time(WIFI_IF_STA)/1000`)
millisecond timestamps on every debug log line — hesperus and cerberus are
both stations on the same AP, so this is a shared, sub-ms-precision clock
across boards, letting logs from each be correlated directly.
`tsf_us` (captured in hesperus's ISR at the instant of the physical
trigger) against cerberus's own logged receipt time gives the true one-way
"trigger → cerberus received" latency, independent of the return trip:

| Event | One-way (trigger → received) | Full round trip (hesperus-measured) | Implied return leg |
|---|---|---|---|
| GOAL | ~132ms | 146ms | ~14ms |
| START | ~270ms | 284ms | ~14ms |
| ARM | ~267ms | 285ms | ~18ms |

Outliers of 856ms (first-ever connection in a session) and ~2.9s (later in
the same session) were also observed on single attempts that still returned
`httpCode == 200` — consistent with TCP connect-phase trouble (e.g. a lost
SYN packet triggering the underlying stack's own retransmission).
**Conclusion: essentially all latency, and effectively all of its
variance, is attributable to TCP connection establishment**, paid fresh on
every single event, since no connection reuse/keep-alive existed
(`http.begin()`/`http.end()` opened and closed a new connection each time).
Cerberus's own processing (JSON parse, dispatch, queue, respond) is fast
and consistent — the ~14-18ms return leg above — and was never a meaningful
contributor.

Separately, at higher trigger rates, a second effect compounds the first:
two bench tests isolated a queueing theory directly, using the same
`receipt_ms*1000 − tsf_us` method against a rapid sequence of real `GOAL`
triggers. **Test A — rapid-fire triggering (~88 events, spacing mostly
60-800ms):** one-way latency ramped smoothly from ~110ms up to 2773ms over
each ~8s burst, resetting back down whenever a multi-second pause let the
backlog drain. Latency growth per event correlated directly with
inter-trigger spacing: gaps under ~130ms added ~140-190ms of extra latency
each; gaps over ~250ms let latency drain instead of growing. This is a
queueing signature, not network jitter or clock drift (hesperus's own
`tsf_observed` and `processor_clock` tracked each other to within tens of
microseconds throughout). The mechanism: `uploadWorkerTask`
(`hesperus-timing-gate/src/main.cpp:238`) drains `networkQueue` one event at
a time, and each full connect+POST+confirm cycle costs ~230-270ms (matching
the baseline above exactly) — triggers arriving faster than that queue up
and each waits longer than the last for its turn. **Test B — control, same
trigger source, ~1-2s spacing (~87 events):** mean 234.6ms, median 259.5ms,
p90 319ms, p95 345ms, stdev 102ms. Only one outlier, 818.8ms — the very
first request of the session (cold connection). This confirmed Test A's
spike was purely a by-product of sustained rapid-fire triggering outrunning
hesperus's one-event-at-a-time send cycle, not a new or separate network
problem.

**Confirmation.** `networkQueue` is only 10 deep
(`hesperus-timing-gate/src/main.cpp:452`). At a ~250ms service time, a
sustained trigger rate faster than that for more than ~2.5s overflows it —
silently dropping events, not just delaying them. `ares-pulse-generator`'s
`trial_burst` fired 40 `GOAL` pulses at a fixed, known 90ms interval (raw
data in `test-data/trial-burst-20260630-1542*.txt`); only 24 reached
cerberus. The other 16 are independently confirmed dropped two ways at
once: hesperus's own serial log showed `[QUEUE OVERFLOW] N networkQueue
event(s) dropped.` lines summing to exactly 16, and cerberus's received
events show gaps of 180ms/270ms (2x/3x the 90ms send interval) exactly
where pulses are missing. The first ~15-16 pulses got through with no drops
at all, at a clean, unbroken 90ms spacing — but their latency climbed the
whole time, from 272ms to 2726ms, the same ramp signature as Test A. Once
saturated, latency flattened at ~2700-2770ms instead of growing further.
This was no longer an inferred risk: at realistic burst rates, the firmware
was silently losing race events.

**Resolution.** **Persistent connection per gate board (highest leverage),
implemented and merged.** Open one WebSocket connection per hesperus board
once it becomes ready (Wi-Fi connected + cerberus discovered), and hold it
open across all subsequent trigger events instead of opening/closing per
event — eliminates the repeated TCP-handshake cost for every event after
the first. Compatible with Wi-Fi modem sleep: TCP session state persists
across the radio's sleep/wake cycles since they operate at different
layers; only the first transmission after a sleep period pays a smaller,
bounded radio wake-up cost instead of a full handshake (relevant to the
power-save issue below). Two design details settled during implementation:

- **A held-open connection alone does not give rapid failure detection** —
  if the peer silently disappears (power loss, Wi-Fi drop with no clean
  FIN/RST) while the socket is idle, plain TCP has no built-in way to
  notice. A WebSocket gives proactive detection for free via its ping/pong
  control frames and library-level disconnect callbacks
  (`AsyncWebSocket::onDisconnect`), rather than needing hand-built
  keepalive/timeout logic.
- **The gate remains the connection initiator**, matching the existing
  client/server roles and mDNS discovery direction (gate resolves
  `cerberus.local`; cerberus has no equivalent way to discover a gate).
  Who initiates doesn't restrict data direction afterward — a WebSocket is
  full-duplex once established regardless of who dialed.

WebSocket was chosen over a bare kept-open TCP/HTTP socket specifically
because the ping/pong-and-disconnect-detection property comes essentially
free with a library on both ends, `ESPAsyncWebServer` (already a cerberus
dependency) includes `AsyncWebSocket` with no new library needed
server-side, message framing is native, and the existing dispatch logic
(`race_command_from_http()` / JSON schema) didn't need to change at all —
only the transport underneath moved. Honest cost: hesperus had no
WebSocket *client* before this (added `Links2004/arduinoWebSockets`), and a
WS connection still needs an initial HTTP-upgrade handshake, so there's
still a first-connection cost, just paid once per board instead of once per
event.

**N/A (was "Still open")**: the recommendation to configure `HTTPClient`
timeouts explicitly (`http.setConnectTimeout()`, alongside `http.setTimeout()`)
was never implemented, and now never will be — hesperus's runtime code no
longer constructs an `HTTPClient` object at all (verified: `main.cpp` only
mentions it in a historical comment). The WS client library
(`WebSocketsClient`) handles the persistent connection instead, with its own
timeout/heartbeat config (`enableHeartbeat()`), unrelated to `HTTPClient`'s
settings. The two proposed characterization experiments (isolating
connect-phase latency with temporary `WiFiClient::connect()` instrumentation;
injecting packet loss via Linux `netem`) are moot for the same reason — both
targeted the old per-event HTTP connect phase, which no longer exists.

**Verification.** Bench-measured WS latency settled at ~5-12ms typical
(a one-time ~1.1s first-connection warm-up on an early run didn't recur
later), against ~115-560ms for HTTP comparison runs — beat the original
~15-30ms prediction. `trial_burst` re-run under WS (raw data in
`test-data/trial-burst-ws-20260630-1036.txt`): all 40/40 pulses reached
cerberus, zero drops, no `[QUEUE OVERFLOW]` lines. Latency: mean 8.7ms,
median 8.2ms, stdev 2.7ms, min 5.2ms, max 18.2ms, p99 18.2ms — flat
throughout, no climbing/ramp signature. Confirms the mechanism directly:
the persistent connection eliminates the ~250-270ms per-event
connect+POST+confirm service time that was the actual bottleneck, so the
depth-10 `networkQueue` never comes close to saturating at this rate.
Reconnect-after-Wi-Fi-drop and reconnect-after-cerberus-reboot are both
bench-confirmed working (self-healing, no manual intervention needed).
Both physical hesperus test boards flashed and running WS successfully;
the other 3 hesperus board envs share the same firmware so didn't need
separate testing. See also the ARM/START and double-trigger issues below,
whose WS re-runs are further confirmation of the same mechanism.

### Issue: Wi-Fi power-save vs. battery budget

**[OPEN — see outstanding-work #1]**
*(was Observations #4, #5; Recommendation 2)*

**Observation.** Hesperus originally used `WIFI_PS_MAX_MODEM` (aggressive
power saving). A ~2.9s latency spike was traced to modem-sleep wake-up: the
radio sleeps between sparse events — exactly the ARM/START/GOAL spacing of
a real race — and must wake before it can transmit. Cerberus's own code
already disables power-save (`WIFI_PS_NONE` in `net/wifi-manager.h`) for
this same reason; hesperus was changed to match. However, a subsequent test
*after* switching to `WIFI_PS_NONE` still showed a ~2993ms outlier —
confirming modem sleep was not the sole cause; the TCP connect-phase issue
above is a separate, additional contributor that disabling power-save alone
doesn't fix.

Gates are battery-powered, and batteries above 500mAh are hard to fit
physically. `WIFI_PS_NONE`'s continuously-active radio draws considerably
more current than a modem-sleep mode — generic ESP32 figures put
power-save-off in the 80-150mA range versus roughly 15-30mA average with
modem sleep enabled (generic chip figures, not measured on this
hardware/firmware at the time). Against a sub-500mAh budget, that's
plausibly the difference between a few hours and most of a day of runtime.

**Confirmation.** Measured 2026-07-31: current `WIFI_PS_NONE` draw is
**~110mA average on a gate** — a real, non-hypothetical cost, now
confirmed for this actual hardware rather than inferred from generic
figures.

**Revised, 2026-08-07** (more accurate monitoring): **113mA**, not 110mA
— a small (~2.7%) upward correction to the baseline above. Every
`MIN_MODEM`-vs-`NONE` percentage-reduction figure elsewhere in this issue
(sessions 11/12: ~34%/~42% reduction, etc.) was computed against the
original 110mA figure and hasn't been recalculated against 113mA — treat
those percentages as slightly optimistic (by roughly this same ~2.7%)
rather than re-deriving each one for a correction this small.

**Resolution.** Not yet resolved. Decided direction: reintroduce a lighter
modem-sleep mode now that persistent connections exist —
`WIFI_PS_NONE` was originally adopted to fix a problem a persistent
connection now addresses more directly and without the full power cost.
`WIFI_PS_MIN_MODEM` (wakes every beacon interval, ~100ms typically) is a
reasonable middle ground to test empirically against `MAX_MODEM` and
`NONE` for both latency and current draw — this was explicitly deferred
(2026-07-30) until persistent connections landed, since that's the
configuration it's actually meant to be measured under; they've now
landed, so this is unblocked. Keep the `NONE` baseline figure (110mA)
alongside whatever `MIN_MODEM` measures — "we cut power" needs both
numbers to mean anything, not just the new one.

**Verification.** None yet. Proposed method (never run): for each of
`WIFI_PS_NONE`, `WIFI_PS_MIN_MODEM`, `WIFI_PS_MAX_MODEM`, with a persistent
connection open, measure (a) current draw via a USB power meter or
multimeter, at idle and during a trigger, and (b) wake-to-first-byte
latency for a trigger fired after a range of idle gaps (1s, 5s, 15s, 30s,
60s+, spanning realistic ARM-to-START and START-to-GOAL spacing). The WS
ack/retry mechanism (see the reliable-delivery issue below) now also gives
a concrete pass/fail signal that didn't exist when this was first
proposed: run the existing multi-run trial suite under `MIN_MODEM` and
check retry counts/rate against the `NONE` baseline, not just whether runs
complete — a real regression (missed beacon wake windows delaying sends)
would show up as elevated retries before it shows up as a visible fault.
`MAX_MODEM` is not part of this round of testing — already ruled out (see
Observation above).

**`WIFI_PS_MIN_MODEM` enabled for testing, 2026-08-04**
(`hesperus-timing-gate/src/main.cpp`, one-line change from the existing
`esp_wifi_set_ps(WIFI_PS_NONE)`). Build-verified (`pio run -e
hesperus-gate-s3-zero`); not yet hardware-verified. Plan: (1) current-draw
comparison against the 110mA `NONE` baseline (user, physical measurement);
(2) a single-spammer trial — deliberately the established pass-bar
condition (session 8's confound-free baseline: 0.03% retry rate), not a
harsher one, since the question here is specifically whether `MIN_MODEM`
regresses the already-accepted baseline, not a fresh stress
characterization — checking retry rate for a regression signal. **Both
hesperus units (start and goal) need reflashing** — this line is in the
shared `main.cpp`, not board-role-specific code. Revert to
`esp_wifi_set_ps(WIFI_PS_NONE)` if either measurement doesn't support
keeping it.

**Session 11 results (2026-08-04)** (`test-data/spam-tests/{cerberus-11,
hesperus-start-11,hesperus-goal-11}.log`) — single-spammer, `MIN_MODEM`,
~5h active + ~90min idle (~6h34m total, 14,968 total ARM+START+GOAL
events):

- **Current draw: 480mAh / 6h34m ≈ 73mA average** — a real ~34% reduction
  from the 110mA `NONE` baseline. Blended across active + idle time, not a
  clean single-condition number — a dedicated idle-only baseline is the
  planned next measurement.
- **Ordinary retry rate elevated ~47x.** Excluding the acute episode below,
  210/14,968 events (1.4%) needed a retry, vs. session 8's confound-free
  `NONE` baseline of 0.03% under the same single-spammer condition. All
  still succeeded (same harmless jitter-vs-timeout mechanism session 10
  characterized) — consistent with modem sleep adding latency to most wake
  cycles, not just rare outliers, so more events graze the timeout even
  though `WS_ACK_TIMEOUT_MS` was already widened.
- **One acute ~2-minute episode broke the single-spammer zero-loss bar.**
  At T≈50.66M-50.79M ms, both boards simultaneously logged repeated
  `wsClient.loop()` stalls from 217ms up to **7.6 seconds**
  (`wifi_status=3`/WiFi-associated, `ws_connected=0`), 6 WS disconnects,
  and **8 genuine event drops** (`"dropped after ack deadline"`/`"after
  max retries"`). This exact `wsClient.loop()`-blocking signature (the
  same one from the original congestion investigation) occurred **zero
  times** in session 8's equivalent-length `NONE` single-spammer baseline.
  Every single-spammer trial to date has been zero-loss until this one.
  Not proven causal from a single trial (can't fully rule out an
  unrelated environmental event coinciding with this run), but the
  contrast with session 8 makes `MIN_MODEM` the leading suspect, not a
  coincidence, pending a repeat trial.
- **Reading**: `MIN_MODEM`'s ~34% power saving currently comes with a real
  reliability cost that breaks the established single-spammer pass bar —
  not yet a case for adopting it as-is. Next steps before any decision:
  the clean idle-only current-draw baseline (in progress), and ideally a
  second single-spammer `MIN_MODEM` trial to see whether the acute-episode
  pattern recurs (systematic problem) or was a one-off (still concerning
  given the elevated ordinary retry rate regardless, but a different
  severity picture).
- **Mechanism, on closer look — not just "channel congestion."** The 17
  stall durations aren't uniformly random: 8 of them land within 2ms of
  exactly **5000ms** (5001-5002ms, one outlier at 4880ms). Checked the
  actual `links2004/WebSockets` library source (pinned `^2.4.1`, resolved
  to 2.7.x) rather than guessing: `WEBSOCKETS_TCP_TIMEOUT = 5000`
  (`WebSockets.h`) is the library's own hardcoded TCP socket timeout,
  applied during connect/reconnect. Combined with hesperus's own heartbeat
  config (`main.cpp:936`, `enableHeartbeat(5000ms ping, 3000ms pong
  timeout, disconnect after 2 misses)`), a coherent chain emerges: (1)
  **trigger** — `MIN_MODEM`'s sleep window is a liability only if it
  happens to coincide with a burst of missed/corrupted real-AP beacons
  severe enough to blow through the 3s pong timeout twice in a row (a rare
  probabilistic coincidence with the already-documented beacon-processing-
  overhead effect, not a standing condition — `WIFI_PS_NONE` is never
  exposed to this since it's always listening); (2) **cascade** — once
  disconnected, several consecutive *reconnect* attempts can each
  independently hit the library's fixed 5s TCP timeout if conditions are
  still degraded, chaining into the observed ~2-minute total outage — a
  `WebSockets`-library property, not firmware-specific; (3) **why it
  doesn't recur** — it needs that specific rare coincidence, so going
  quiet for the remaining hours is consistent with a low-probability tail
  event, not evidence against the mechanism. Still a hypothesis, not
  proof — the overnight repeat trial is the actual test: recurrence at
  some low rate supports it, continued absence over a much longer run
  weakens it.

**Decision: `NONE` stays the shipped default, 2026-08-04.** Decided
*before* running the overnight trial, deliberately, to avoid rationalizing
a marginal result after the fact: given the asymmetric stakes (extra
~35-55mA running `NONE` indefinitely vs. a genuine outage during a real
contest), a clean overnight trial would not be sufficient evidence to
adopt `MIN_MODEM` — absence of a recurrence in one more trial is not
evidence of absence of a rare tail risk, especially given the mechanism
above is understood well enough to predict occasional low-probability
recurrence, not ruled out entirely. The overnight trial's role from here
is diagnostic only (does it recur, at roughly what rate, does the
5000ms-timeout signature repeat) — not a pass/fail gate for production
adoption. `MIN_MODEM` would need the mechanism actually fixed (e.g. a
widened heartbeat pong-timeout/miss-count, discussed but deliberately not
yet applied so as not to confound this trial) and then re-verified
extensively before this decision would be revisited.

**Idle-only current draw, 2026-08-04**: 17mAh over 18 minutes ≈ **56mA**
average idle draw under `MIN_MODEM` (short sample, but a real number, and
cleaner than the blended 73mA above since no spammer or events were
active). Of that, the status NeoPixel (solid green when `READY`, `main.cpp`'s
`ledDiagnosticTask`) accounts for ~20mA — over a third of total idle draw.
**Considered and declined, 2026-08-04**: reducing it via a duty-cycled
flash (e.g. 100ms on/900ms off, ~10% duty, ~2mA) instead of solid-on.
Decision: keep it solid — the LED is the operator's at-a-glance
"gate alive" signal, and a brief once-a-second flash trades real
visibility (especially in bright outdoor daylight at an actual contest)
for a comparatively small (~18mA) saving next to the larger open question
above (the `MIN_MODEM` reliability regression). Not revisited unless the
power budget becomes tight enough that every mA matters.

**Scope note applying to every current-draw figure in this issue**
(110mA `NONE` baseline, 73mA/63.6mA/62.8mA `MIN_MODEM` blended figures,
56mA idle-only): each includes this same ~20mA constant for the single
WS2812 status NeoPixel, held solid (green or red) continuously regardless
of power-save mode or trial condition — it's gate electronics, not radio
behaviour, so it's a fixed offset present in every measurement here, not
something that varies with `NONE` vs. `MIN_MODEM` or with trial severity.
The radio+MCU portion alone is therefore each headline figure minus ~20mA
(e.g. `NONE`: ~90mA; `MIN_MODEM` idle-only: ~36mA) — worth keeping in mind
before comparing these numbers to any other project's bare radio power
figures.

**Session 12 results (2026-08-05)** (`test-data/spam-tests/{cerberus-12,
hesperus-start-12,hesperus-goal-12}.log`) — the planned second single-spammer
`MIN_MODEM` repeat, checking whether session 11's acute episode recurs:
9999 runs, ~11.94 hours.

- **Current draw: 769mAh / 12h6m ≈ 63.6mA average** — closer to the ~56mA
  idle-only figure than session 11's 73mA blended figure (this trial's
  active/idle mix differed), and still a clear ~42% reduction from the
  110mA `NONE` baseline.
- **Session 11's acute episode did not recur.** Zero `wsClient.loop()`
  stalls, zero WS disconnects, zero "dropped after ack deadline"/"max
  retries" lines in either hesperus log. Ordinary retry rate 222/29,997
  events (0.74%) — elevated vs. session 8's `NONE` baseline (0.03%) but
  roughly half session 11's ordinary rate (1.4%); no front-loaded confound
  pattern in the binned breakdown. Max attempts needed to succeed: 4 (two
  events).
- **One race-outcome loss, judged a trial-protocol artifact, not a system
  fault (confirmed with the user).** A GOAL (`tsf_us=89063696892`) needed 4
  retry attempts spanning ~1.69s before its ack landed; by the time it
  reached cerberus the same pulser had already fired ARM+START for the
  *next* run (`start_tsf_us=89064996879`, ~1.1s after the GOAL trigger), so
  the stale-GOAL guard correctly rejected it (`[RACE] rejected stale GOAL:
  tsf_us=89063696892 < start_tsf_us=89064996879`) — working as designed,
  the first time this guard has fired on a real congestion-delayed event
  rather than a synthetic `--tsf-us` test. **Not counted against the
  single-spammer pass bar**: no real run can have a GOAL followed by the
  next ARM within ~1 second — the trial's rapid-fire back-to-back cycling
  is purely a convenience of the test protocol, not a scenario the system
  needs to survive. A different failure mode from session 11's (a single
  retry-delay outrunning the next run's own ARM/START, not a
  stall/disconnect cascade), so this doesn't confirm session 11's
  `wsClient.loop()`/5000ms-timeout mechanism recurring — it's a separate,
  narrower way `MIN_MODEM`'s added latency can bite, and one that requires
  unrealistically fast run cycling to trigger.
- **Reading**: strengthens the case that session 11's acute episode was a
  rare tail event rather than a standing `MIN_MODEM` property, and adds a
  second independent current-draw data point in the low-60s mA range. Does
  not change the 2026-08-04 decision (`NONE` stays shipped default) —
  that decision explicitly treats repeat trials as diagnostic, not a
  pass/fail gate; `MIN_MODEM` still needs the session-11 mechanism
  root-caused and fixed before re-adoption is reconsidered.

**Session 13 results (2026-08-05)** (`test-data/spam-tests/{cerberus-13,
hesperus-start-13,hesperus-goal-13}.log`) — a deliberately adversarial
smoke test, not a pass-bar trial: `MIN_MODEM`, two spammers + BT
streaming simultaneously (the harshest condition in the acceptance
criteria), current firmware as-shipped (500ms/5200ms ack-timeout
settings from the item-1 fix). 5000 runs, ~6.06 hours. Current draw not
measured this run (reliability-only).

- **Session 11's acute stall/disconnect mechanism recurred, twice, and
  worse.** Two episodes (T is approx 146744-146758ms, ~14s;
  T is approx 148894-148909ms, ~15s), both boards hitting the same 5002ms
  `wsClient.loop()` block signature session 11 identified (the
  `WebSockets` library's hardcoded `WEBSOCKETS_TCP_TIMEOUT`),
  disconnect/reconnect on both boards, some events exhausting all 10
  retry attempts. 17 genuine network-level event losses total (12
  ARM/START-side, 5 GOAL-side) out of 15,000 physical triggers,
  concentrated in these two windows.
- **Conclusion: this is a real, stress-scaling mechanism, not a rare
  coincidence.** Occurrence count tracks stress severity directly across
  the three `MIN_MODEM` trials to date: 0 times (session 12,
  single-spammer), 1 time (session 11, single-spammer), 2 times (session
  13, two-spammer+BT). That gradient is itself evidence for a genuine
  congestion-triggered mechanism, not an unrelated coincidence.
- **Mitigation available, not yet applied: widen the heartbeat
  pong-timeout/miss-count** (`enableHeartbeat()`,
  `hesperus-timing-gate/src/main.cpp:936`). Proposed when session 11 first
  found this, deliberately withheld through sessions 12-13 so those trials
  would cleanly show whether the mechanism recurs unmodified. It now has:
  applying it and re-running a comparable two-spammer+BT trial is the
  concrete next step, not further unmodified repeats.
- **New, unexplained finding: the GOAL board retried 4.6x more often than
  the ARM/START board under this specific stress combination** (18.3% vs.
  4.0%, 912/4993 vs. 403/9984). Not seen at this magnitude in any prior
  session. Two live hypotheses, not yet distinguished: physical placement
  relative to the spammers/BT source (RF-level; would predict the
  asymmetry follows *position*, not the specific board unit), or something
  about the GOAL board's single-event-type send pattern versus the
  ARM/START board's interleaved two-event pattern (would predict the
  asymmetry follows *role*, which is coupled to position in the current
  rig wiring and can't be fully separated from it by a swap alone). A
  physical position swap (start/goal roles exchanged between the two
  physical hesperus units) is planned to test whether the asymmetry moves
  with the position or stays with the specific board — won't fully isolate
  role from position, but will rule out "specific unit's hardware" as the
  sole cause either way.
- **Objection-#4-relevant data point, still bounded.** The stale-GOAL
  misattribution mechanism (see that issue below) fired 3 times this
  trial; worst resolution time for anything that actually succeeded was
  2.39s (5 attempts) — under the roughly-3s assumed-safe goal-to-rearm
  gap, but closer to it than anything seen pre-fix (session 10: 462ms
  max). **Conclusion: doesn't yet justify widening the ack timeout/deadline
  further** (nothing observed exceeded the current safe margin), but does
  confirm the risk is real under this specific adversarial combination,
  not hypothetical. See the stale-event-misattribution issue below for a
  more targeted fix under consideration instead of a further timeout
  widening.
- **Caveat, explicitly**: this was the deliberately harshest condition in
  the acceptance-criteria framework (two-spammer+BT), run specifically to
  surface issues that might not appear under realistic load — none of
  these findings say anything about behaviour under the single-spammer
  pass bar (sessions 3/4/5/8/12, still the operative standard) or normal
  contest conditions. Treat as smoke-test diagnostics, not a reason to
  revisit the pass-bar conclusion.

**Session 14 results (2026-08-05)** (`test-data/spam-tests/{cerberus-14,
hesperus-start-14,hesperus-goal-14}.log`) — the heartbeat-widening fix
proposed above (`enableHeartbeat` pong-timeout 3000ms→5000ms, miss-count
2→3), tested under the same `MIN_MODEM` + two-spammer+BT smoke test as
session 13, ~2900-3000 runs, 3.58 hours.

- **The fix made things dramatically worse, not better — tested and
  rejected.** Every measure moved the wrong way versus session 13's
  unmodified baseline (normalized per-hour, since durations differ):
  genuine drops 3.8→63.7/hour (16.8x), `wsClient.loop()` stalls
  2.6→27.4/hour (10.4x, max single stall 5002ms→**15,968ms**), WS
  disconnects 0.8→4.6/hour (5.5x), stale-GOAL rejections 0.5→67.3/hour
  (136x), ARM/START retry rate 4.0%→9.9%, GOAL retry rate 18.3%→**42.6%**.
  Live-observed by the user mid-trial before the full-log analysis
  confirmed it at scale.
- **Coherent mechanism, not noise**: widening the pong-timeout/miss-count
  only changes how long hesperus tolerates silence before declaring the
  link dead and forcing a reconnect — it doesn't improve connection
  *quality*. Against a genuinely degraded (not merely jittery) connection,
  a longer tolerance window means hesperus sits on a zombie connection
  longer before tearing it down and recovering, which is consistent with
  the 3x jump in max stall duration and the explosion in drops/stale-GOALs
  (more retries and more late GOALs piling up during a now-longer
  not-yet-recognized-as-dead window, instead of a faster clean reconnect).
  The mitigation optimized for the wrong side of the tradeoff: it aimed to
  stop a merely-jittery connection being killed unnecessarily, but this
  stress condition is dominated by the opposite case (genuinely dead
  connections recovering slower).
- **Reverted, 2026-08-05** (`hesperus-timing-gate/src/main.cpp:936`), back
  to `(5000, 3000, 2)`. Build-verified. Both boards need reflashing before
  any further `MIN_MODEM` trial — session 14's build should not be reused.
- **Where this leaves the `MIN_MODEM` mechanism**: still unexplained,
  still unmitigated. The heartbeat-widening hypothesis is now
  disconfirmed, not just unconfirmed — this was a real test of a real
  candidate fix, and it failed clearly enough to rule out "just widen the
  tolerance" as a viable direction. Any future mitigation attempt needs a
  different theory of the failure, not a bigger version of this one.

**25-hour blended current draw, 2026-08-06** (spanning sessions 11-14
continuously, `MIN_MODEM`, gates never powered off between trials, mixed
single-spammer/two-spammer+BT conditions plus idle gaps): **1569mAh over
25h ≈ 62.8mA average.** Consistent with session 12's 63.6mA and the
dedicated 56mA idle-only baseline — reinforces the ~55-65mA range as
`MIN_MODEM`'s real-world draw regardless of stress condition, including
across session 14's reconnect-heavy pathological period.

**`NONE` blended current draw, 2026-08-06** (spanning sessions 15/15a,
`WIFI_PS_NONE`, two-spammer+BT stress): **1202mAh over 12h15m ≈ 98.1mA
average.** A real-conditions `NONE` figure to set directly against the
`MIN_MODEM` one above, both measured the same way (blended across actual
stress trials, not a clean single-condition bench figure) — refines the
power-saving estimate to **~36%** (98.1→62.8mA) under comparably harsh
conditions, close to but a bit under the original ~40%+ figure derived
from the 2026-07-31 110mA idle/light-load baseline. Either way, the
open question stays reliability, not power — power was never in doubt.

**Session 15 results (2026-08-06)** (`test-data/spam-tests/{cerberus-15,
hesperus-start-15,hesperus-goal-15}.log`) — `WIFI_PS_NONE` (heartbeat
reverted to `(5000,3000,2)`), intended two-spammer+BT, 5000 runs, ~5.97h.
**Compromised trial: one spammer went offline partway through** (confirmed
by the user; not caught until after the run). Written up anyway with the
caveat stated plainly, per the same treatment past confounded sessions
(5, 7, 8) got — a spotted, locatable confound doesn't make the data
meaningless, it just changes what question it can answer. **A clean
same-condition re-run (3000 runs) is planned.**

- **The dropout is precisely locatable.** Nearly all problems (11/16 WS
  disconnects, 13/18 drops, 4/5 stale-GOAL rejections) cluster into one
  ~17.7-minute window, T≈13.5-31 minutes into the trial — matching the
  user's own estimate ("possibly within the first 30 minutes") almost
  exactly. Outside that window, the remaining ~5.7h has only two small
  isolated blips, no clustering.
- **Segmenting at that boundary gives two genuine (if unplanned) results**,
  not one intended one:
  - **First ~30min (genuine two-spammer+BT+`NONE`)**: ARM/START retry 4.20%
    (n=858), GOAL retry 6.73% (n=431), max `wsClient.loop()` stall ~1.2s,
    zero "dropped after max retries" (only ack-deadline/link-down). Against
    session 13 (`MIN_MODEM`, full 6h, same nominal stress): ARM/START retry
    is almost identical (4.20% vs 4.0%) — that side of the congestion hit
    seems power-save-independent — but GOAL retry is much lower (6.73% vs
    18.3%) and, most notably, **no stall ever approached the 5000ms
    `WEBSOCKETS_TCP_TIMEOUT` signature** that defined sessions 11/13/14.
    Supportive of the acute cascade being `MIN_MODEM`-specific (or at least
    far less severe under `NONE`) — but resting on ~30 minutes of exposure
    against sessions 13/14's full 6h+3.6h, so much weaker evidence than the
    `MIN_MODEM`-recurs finding it's being compared against.
  - **Remaining ~5.7h (one spammer + BT only, `NONE`)**: retry rates crash
    to 0.02%/0.09% (n=9127/4566) — at or below the single-spammer `NONE`
    pass-bar baseline (session 8: 0.03%). Not the intended two-spammer
    condition, but a real, fairly large single-spammer+BT+`NONE` data
    point that hadn't specifically been characterized at this scale before
    (prior single-spammer pass-bar sessions didn't run BT alongside) —
    incidental value, not wasted.
- **Item 1 (ack-path fix) still not cleanly verified.** This was supposed
  to be the controlled two-spammer+BT re-run confirming the retry-count
  drop under `NONE`; the shortened hard-stress window means it's
  suggestive (both segments' retry rates look healthy) rather than the
  clean confirmation intended. Remains open pending the planned re-run.

**Session 15a results (2026-08-06)** (`test-data/spam-tests/{cerberus-15a,
hesperus-start-15a,hesperus-goal-15a}.log`) — the planned clean re-run,
`WIFI_PS_NONE`, two spammers + BT, 3000 runs, ~3.58h. **Also compromised**:
the BT stream was found not running partway through and switched back on
at T=208430864 (user-confirmed); exact off-start time unknown, both
WiFi spammers were verified operational from ~5 minutes in per the trial's
own setup procedure. Written up anyway, same reasoning as session 15 — the
confound is identified and bounded, so the data isn't meaningless, just
answering a slightly different question than intended.

- **Different character from session 15**: instead of one brief severe
  cluster followed by calm, this trial shows **sustained, continuous
  churn across nearly the entire run** — disconnects from ~5 minutes in
  through to near the end, not a localized spike. Whole-session (~3000
  runs): 43 genuine drops, 22 stale-GOAL rejections, 33 stalls, retry
  rate 1.46% (ARM/START) / 9.47% (GOAL).
- **Splitting at the BT-resume timestamp shows no clear worsening from
  BT** — if anything several metrics improve after it comes on
  (disconnects/hour 18.1→12.5, ARM/START retry 2.72%→0.37%; GOAL retry
  roughly flat at ~9.5% either way). **Not read as "BT doesn't matter"** —
  this isn't a controlled comparison (true BT-off start unknown, RF
  conditions drift over hours regardless, n=1 trial) — read as "two
  spammers alone already produce sustained meaningful stress under
  `NONE`," which the data does support regardless of BT's contribution.
- **The one finding that changes prior conclusions**: a genuine **5002ms**
  `wsClient.loop()` stall (T=202785556) — the exact `WEBSOCKETS_TCP_TIMEOUT`
  signature that defined the `MIN_MODEM` cascade in sessions 11/13/14 —
  occurred here under `NONE`, during the confirmed-no-BT period. **Revises
  session 15's tentative "maybe `MIN_MODEM`-specific" reading**: the severe
  stall signature is not exclusive to `MIN_MODEM`, it's evidently a general
  two-spammer WiFi-stack-overhead property that `NONE` is not immune to —
  just apparently less frequent/severe under `NONE` (one occurrence here
  vs. repeated occurrences per trial under `MIN_MODEM`) rather than absent.
- **Item 1 (ack-path fix)**: overall retry rates (1.46%/9.47%) are
  meaningfully lower than session 13's `MIN_MODEM` full-6h rates
  (4.0%/18.3%) over a comparable (if shorter, ~3.6h) exposure — reasonably
  supportive the fix is working, still not the fully clean, confound-free
  confirmation this item has been waiting on since session 10.

**Session 16 results (2026-08-07)** (`test-data/spam-tests/{cerberus-16,
hesperus-start-16,hesperus-goal-16}.log`) — the clean re-run sessions 15
and 15a couldn't deliver: `WIFI_PS_NONE`, two spammers + BT, 5000 runs,
~5.97h (T=244434923→265930842ms). Both spammers and the BT stream
confirmed continuous throughout, no dropout or equipment issue on any
interference source — the first genuinely confound-free two-spammer+BT
`NONE` trial to date.

- **Race outcome: 4940 armed+started, 4911 committed — 29 lost (0.59%).**
  Higher than session 13's `MIN_MODEM` loss rate (17/15,000 physical
  triggers, ~0.11%) by count, though on a smaller physical-trigger base
  here (~14,868) the two aren't a strictly like-for-like comparison. No
  crash, no reboot, on either board, across the full trial.
- **Retry rates, whole trial: ARM/START 4.15% (411/9906), GOAL 10.32%
  (512/4962).** ARM/START sits almost exactly on session 13's `MIN_MODEM`
  figure (4.0%) — consistent with the standing read that this side of the
  congestion hit is power-save-independent. GOAL is meaningfully lower
  than session 13's 18.3% but higher than session 15a's (compromised,
  shorter) 9.47%.
- **Sustained, not localized.** Time-binned into sixths: ARM/START retry
  ran 9.0% / 2.8% / 2.2% / 2.5% / 3.1% / 5.6%; GOAL ran 16.4% / 7.8% /
  8.5% / 7.1% / 8.2% / 14.1%. Elevated at both ends, real throughout the
  middle — genuine sustained stress across the whole ~6h trial, not one
  isolated episode (session 15's pattern) or a front-loaded confound
  (session 7's). Mean RSSI -65.4dBm (range -82 to -55), in line with prior
  sessions — not a signal-strength confound either.
- **Recovery rate is the strongest evidence for the ack-path fix**: of the
  923 distinct events that needed at least one retry, only 8 exhausted all
  retry attempts and were genuinely dropped (99.1% recovered). This is the
  clean, sustained-load confirmation item 1 has been waiting on since
  session 10 — the widened timeout is doing real work, not just avoiding
  drops in a short or partially-compromised window.
- **The 5002ms `WEBSOCKETS_TCP_TIMEOUT` signature recurred 25 times** (of
  ~~158~~ total `wsClient.loop()` stalls >50ms), ~~spread across the trial
  rather than clustered into the acute 2-minute-scale episodes `MIN_MODEM`
  produced in sessions 11/13~~. 34 WS disconnects total, both boards
  combined. **This is the clean confirmation of session 15a's tentative
  finding**: the severe stall signature is a real, recurring `NONE`
  property under sustained two-spammer load, not a rare one-off. Despite
  that, every stall and disconnect recovered automatically with no
  operator intervention and no corrupted result (16 stale-GOAL rejections,
  all handled correctly by the existing guard — see that issue below).

  **Correction, 2026-08-07 (raw-log recount against the actual
  `[WS Pump] wsClient.loop() blocked` canary lines in
  `hesperus-start-16.log`/`hesperus-goal-16.log`).** The "158 total
  stalls" figure doesn't match the raw logs: actual count is **79** (45
  start-board, 34 goal-board) — the source of the original 158 figure
  wasn't identified, flagged rather than silently corrected without
  explanation. More significantly, the distribution is clustered, not
  spread: **49 of the 79 events (27 of them ≥4000ms) fall inside one
  ~9.7-minute episode, T=244443571–245020561ms, starting ~9 seconds into
  the log capture** — i.e. essentially the very start of the trial, not
  mid-run. Within that episode, start- and goal-board large stalls
  interleave almost metronomically (~2.6-2.9s apart — e.g. goal 5002ms,
  start 5002ms, goal 5002ms, start 5002ms...), and consecutive same-board
  stalls repeat at a near-exact **~5513ms** cadence for 6-7 cycles running
  (5002ms block + ~500ms retry-loop overhead) — a fixed reconnect-retry
  period, not random spacing. Cross-checked independently against
  cerberus's own WS disconnect log (34 total, confirming that count is
  correct): **19 of the 34 disconnects land inside the same opening
  window.** Outside it: ~21 minutes of silence, then ~2.5h of only small
  (<1.5s) isolated blips, then two much smaller flare-ups (2-3 events
  each) at T≈258.47M and T≈263.32M–264.28M, separated by hours of near-
  quiet. **Reading**: this episode is comparable in kind to `MIN_MODEM`'s
  acute 2-minute-scale episodes (sessions 11/13) — just front-loaded at
  the very start of the trial rather than occurring mid-run, and ~5x
  longer. The tight cross-board interleaving during the episode points at
  a shared external condition (both radios contending with the same bad
  channel window simultaneously) rather than independent per-board
  coincidences. Does not change the race-outcome, recovery-rate, or
  smoke-test-pass conclusions elsewhere in this session's writeup (all
  independently re-verified and still correct) — only the "evenly spread,
  unlike `MIN_MODEM`" characterization, which is superseded by this
  finding.
- **Not done this session**: the session 9/10-style per-event round-trip
  trace (hesperus `[WS-ACK-RECV]` vs. cerberus `[WS-ACK] sent=`) that would
  show *why* each of the 8 genuine drops happened, the way sessions 9/10
  established the mechanism in the first place. The aggregate recovery
  rate above is solid evidence the fix works; it isn't a re-verification
  of the underlying mechanism, which wasn't in question here.
- **Reading**: closes out the "genuinely clean confound-free `NONE` trial"
  gap that items 1 and 2 in the outstanding-work list were both blocked
  on. Confirms the ack-path fix under real sustained load, and confirms
  `NONE` passes the two-spammer+BT smoke-test bar (graceful degradation,
  full automatic recovery, no corruption) — while also confirming, more
  robustly than session 15a could, that `NONE` is not immune to the severe
  stall mechanism either. Does not touch the separate `MIN_MODEM`-stays-
  unadopted decision, which was never contingent on `NONE`'s own result.

### Issue: Displayed race time vs. true TSF time

**[RESOLVED]**
*(was Observation #6; Recommendation 4)*

**Observation.** Cerberus's `race-timer.h` starts and stops its `run_sw`
`Stopwatch` using cerberus's own local `millis()`, captured at the moment
it processes each `SystemEvent` — not the `tsf_us` timestamp carried in the
event payload. This means the *displayed* run time differs from the true
TSF-computed elapsed time by exactly `L_goal − L_start` (the **difference**
between the two legs' network latencies, not either one individually, and
not their sum). If latency happened to be identical on both legs, this
error would cancel to zero even though the display itself runs a constant
offset behind the real event. Real latency is not constant (see the
connection-latency issue above), so asymmetry between the two legs injects
directly, and visibly, into the displayed number — a spectator-facing
appearance problem, not a data-accuracy problem: the true elapsed time was
already recoverable precisely from `tsf_us` differences regardless.

**Confirmation.** Validated via `ares-pulse-generator`'s `trial_four_runs`
(four back-to-back runs of known 2000/3000/4000/5000ms duration) rather
than by injecting artificial asymmetric latency as originally proposed —
using real gate hardware/network latency directly caught a real design
flaw (below) that synthetic injection likely wouldn't have surfaced as
clearly.

**Resolution.** First attempt: backdate `run_sw` itself at both `START` and
`GOAL` (via `Stopwatch::restart(timestamp)`/`stop(timestamp)`) so the
committed time came out exact. It did — but the live display, ticking in
real time from a backdated start, then had to keep counting past the true
finish for as long as the `GOAL` message's own network leg took to arrive,
and visibly snapped backward the instant it did. That read worse to a
spectator than the original problem (a display that's merely a bit late is
far less alarming than one that runs, then suddenly rewinds).

**What shipped instead**: `run_sw` stays exactly as it was before this
work — plain receipt-time `restart()`/`stop()`, no backdating — so the live
display is smooth and monotonic, just consistently latency-late (the
original, milder problem). Separately, cerberus records the `START`
event's `tsf_us` (`g_run_start_tsf_us` in `race-timer.h`) and, on `GOAL`,
computes the committed time directly as `round((GOAL.tsf_us −
START.tsf_us) / 1000)` — exact to the millisecond, completely independent
of `run_sw` and unaffected by either leg's latency. The display then shows
that exact committed value from the moment the run ends (`RaceState::GOAL`)
instead of `run_sw`'s own frozen reading, so the only visible "snap" left
is the small residual return-leg jitter (single digits to a few tens of
ms) rather than a whole network round trip. Falls back to `run_sw.time()`
unchanged for a locally-buttoned run, which has no `tsf_us` at all and no
network hop to correct for.

**Verification.** `trial_four_runs` confirmed exact 2000/3000/4000/5000ms
committed results. Committed times stayed exact throughout the later WS
bring-up bench suite too, confirming this fix is unaffected by the
transport change.

### Issue: Stale event misattribution across race attempts

**[RESOLVED — reject-only scope]**
*(was Observation #7, "most serious finding"; Recommendation 5)*

**Observation.** The race state machine assumes events arrive in logical
order (`ARM` → `START` → `GOAL`) and has no way to tell which race
*attempt* an event belongs to. Pathological scenario: a `GOAL` event is
delayed (by retries or connect-phase trouble) long enough that a new
attempt is armed and started before the stale `GOAL` finally arrives. If
it lands while cerberus is back in `ARMED`, it's silently dropped (`ARMED`
only reacts to `START`/`RESTART`) — the true result is lost, but the *new*
attempt isn't corrupted. If it lands while cerberus is `RUNNING` on the
*next* attempt, it was accepted **unconditionally** — `RaceState::RUNNING`'s
handler treated any `GOAL` at face value — silently ending the new run
early with a bogus committed time. Nothing distinguished "this GOAL
belongs to the current attempt" from "this is a stale message from a
previous one." A structural gap in the event contract, not a display
cosmetic — persistent connections and retry reduce the probability of this
scenario substantially but don't eliminate it structurally.

**Confirmation.** `tools/testing/ws_send_event.py` gained an optional
`--tsf-us` override so a `GOAL` with an arbitrarily old `tsf_us` can be
sent on demand — reproduces exactly what a sufficiently-delayed real
message would look like on arrival, without needing to actually hold
anything back in flight. This was run 2026-07-31 against the already-landed
fix (below) rather than pre-fix behaviour, since the fix shipped first —
confirming the *fix*, not just the original bug. Confirming the original
unfixed bug this way separately wasn't judged necessary: the code-reading
finding above plus this same tool's confirmation of the fix's correctness
together cover both directions.

**Resolution.** Considered but not (yet) built: an explicit run/attempt
identifier in the event contract — tag each armed attempt with a
monotonically increasing id, include it in the payload, reject
`START`/`GOAL` events that don't match the currently armed attempt. This
is the only option that makes the scenario provably impossible rather than
merely improbable, but has the highest implementation cost (touches the
event schema on both boards and the state machine's acceptance logic) —
still recommended as a follow-on once the lower-effort mitigation below has
had time to prove (or not) its own sufficiency.

**Implemented instead (reject-only scope), 2026-07-31**
(`cerberus-gate-controller/src/race/race-timer.h`, the `RaceState::RUNNING`
`GOAL` branch): `tsf_us` is already a shared, ordered clock across boards,
so staleness can be detected without any new field — a `GOAL` whose
`tsf_us` precedes the *current* attempt's own recorded `START.tsf_us`
cannot possibly belong to the current attempt, since that attempt's clock
only starts counting forward from its own start. A `GOAL` is now rejected
(logged as `[RACE] rejected stale GOAL: tsf_us=... < start_tsf_us=...`,
state stays `RUNNING`, nothing committed) whenever its `event_tsf_us` is
less than `g_run_start_tsf_us`. On review, a ring-buffer of recent attempts
— originally thought necessary for this comparison — turned out **not**
to be needed for reject-only scope: `g_run_start_tsf_us` is a single scalar
always overwritten by the most recent `START`, and `tsf_us` is monotonic
across every attempt, so comparing only against the *current* attempt's
start already catches a stale event regardless of how many attempts were
abandoned in between. A ring buffer would still be needed for a fancier,
still-unimplemented follow-on — retroactively completing an abandoned run
from a late `GOAL` instead of merely rejecting it — which remains a genuine
complement to an explicit attempt-id (not a substitute, and not a gap in
this fix's current scope: it's an enhancement, not a missing piece of what
was promised). Native unit tests added (`test_race_timer.cpp`) covering
the stale-reject case and the `<` vs `<=` boundary (an exactly-equal `tsf`
still commits). Builds clean (`pio test -e native`, `pio run -e
cerberus-cyd2usb-diymalls-ili9341`).

**Verification.** Bench-confirmed 2026-07-31 on real hardware. Sequence:
`NEW_MOUSE` → `ARM` → `START` (real `tsf_us`, e.g. `1785522630871972`) →
`GOAL --tsf-us 1`. Cerberus's own log:
```
[WS] DATA ... {"event":"START","tsf_us":1785522630871972,...}
[WS] DATA ... {"event":"GOAL","tsf_us":1,...}
[RACE] rejected stale GOAL: tsf_us=1 < start_tsf_us=1785522630871972
EVT: GOAL, NEOKEY_BUTTON, PRESSED, tsf=59521406 local=59521406 us
```
The crafted stale `GOAL` was rejected and logged; `race_state` stayed
`RUNNING`; nothing committed. A genuine `GOAL` (real NeoKey button press)
immediately afterward committed normally (`16201ms`).

**Real-world recurrence, sessions 12-13 (2026-08-05).** First observed
outside synthetic `--tsf-us` testing: session 12 (single-spammer
`MIN_MODEM`), 1 occurrence; session 13 (two-spammer+BT `MIN_MODEM` smoke
test), 3 occurrences. All four were a genuine congestion-delayed GOAL
(2-5 retry attempts, up to ~2.4s to resolve) arriving after the pulser's
fast next-run ARM/START had already gone through — the guard rejected
each one correctly, but the true result was still lost, not recovered.
In every case the trigger was the trial protocol's unrealistically fast
goal-to-rearm cycling (session 12: confirmed operator artifact,
sub-1-second gap no real run can produce), not a normal-cadence failure.
**Decision, 2026-08-05: stay with reject-only scope, formally deferred.**
The full attempt-id + ring-buffer mechanism (tag each attempt, retroactively
attribute and commit a late GOAL to the superseded attempt it actually
belongs to, rather than just reject it) is real added complexity — a
payload schema change on both boards, a ring buffer of recent attempts on
cerberus instead of a single scalar, multi-attempt-back matching, and an
unresolved UX question (where does a retroactively-completed result even
surface once the operator has moved on two attempts later). Weighed
against that cost: **all four real firings to date trace to conditions
outside the pass bar** — session 12's was a confirmed test-protocol
artifact (sub-1-second goal-to-rearm, which no real run can produce), and
session 13's three were under the deliberately-adversarial two-spammer+BT
smoke test, not single-spammer. Zero occurrences under the actual accepted
operating condition. Same "improbable, not impossible" reasoning that
justified shipping reject-only scope over the full design in the first
place — left documented as an option, revisited only if a real-world
(non-artifact, single-spammer-or-milder) occurrence shows up, not
otherwise.

### Issue: Duplicate triggers from gapped robot structure

**[Reassessed 2026-08-07 — deprioritized, see outstanding-work #4]**
*(was part of Observation #9; Recommendation 8)*

**Observation.** A robot with a gapped/slotted structure can break one
gate's beam more than once during what should count as a single crossing.
`DEBOUNCE_US` (50ms, ISR-level) suppresses electrical/mechanical bounce,
but a structural gap can plausibly be wider than that, generating
genuinely separate, correctly-timestamped triggers for what should be one
logical event. The race state machine already tolerates this once it's out
of `RUNNING` (a later duplicate is dropped by state, not corrupted), so
this isn't a correctness bug today — ~~but needlessly sending/queueing
extra events adds avoidable network-side pressure for no benefit, since
only the first trigger of a crossing is ever wanted for a race time~~ **—
that "avoidable network-side pressure" framing was written under HTTP's
per-event connection cost and doesn't hold under WS; see the reassessment
below.**

**Confirmation.** `ares-pulse-generator`'s `trial_double_trigger` (two
`GOAL` pulses on the same pin, edges 150ms apart, 100 trials). HTTP
baseline (`test-data/trial-double-trigger-20260630-1604*.txt`): of 98
cleanly-paired trials, the first trigger's latency averaged 267.3ms (stdev
5.9ms, matching the general baseline) and the second averaged 371.2ms
(stdev 6.0ms) — a consistent **~104ms** queueing delay, the same mechanism
as the ARM/START case below, scaled up because 150ms of spacing overlaps
more of the ~267ms send cycle than ARM/START's 200ms does. Open question at
the time: 198 of the expected 200 events arrived — one confirmed genuine
drop via `gate_us` (the very first trial's second edge simply missing, its
first edge having an unusually slow ~816ms cold-start connection that may
have tied up the worker, mechanism not fully confirmed); the second missing
event a lone trailing trigger with no partner, most likely just the log
capture ending before the response came back, not confirmed either.

**Re-run under WebSockets, 2026-07-31**
(`test-data/trial-double-trigger-ws-20260631-1104*.txt`): same 100 trials,
150ms apart. **All 200/200 events arrived** — no drops, resolving the open
question above in WS's favour (the HTTP baseline's drop/ambiguous-trailing
-event was specific to per-event connection cost, not reproduced here).
First-trigger latency — mean 7.7ms, median 6.6ms, stdev 3.9ms.
Second-trigger latency — mean 8.5ms, median 7.5ms, stdev 2.4ms. The ~104ms
queueing offset is gone (down to **~0.7ms**). One first-trigger outlier at
41.6ms (isolated, paired second-trigger unaffected) plus a handful of
smaller 10-20ms spikes scattered through the run — see the WS-jitter issue
below, not investigated further here.

**Resolution.** ~~Not yet implemented. Proposed: a gate-side post-trigger
lock-out (~300ms) — deactivate a sensor for a short window after it fires,
on top of the existing 50ms electrical debounce — would suppress these at
the source. Cheap to add, does no harm once persistent connections make
per-event overhead small (they now do).~~ **Not being pursued — see
Reassessed, 2026-08-07, below.**

**Two open concerns, 2026-07-31 (mooted by the reassessment below, kept
for the record rather than deleted):**
- **The ~300ms figure is arbitrary.** It's only justified as "distinct
  from and longer than the 50ms electrical debounce" — not derived from
  any measured robot gap width or crossing speed. Worth a better estimate
  grounded in real robot geometry/speed before implementing.
- **This changes the failure mode, not just the traffic volume.** Today, a
  genuine duplicate is tolerated by being *ignored* on arrival — the event
  still reaches cerberus, it's just a no-op once the state machine is out
  of `RUNNING`. A source-side lock-out is qualitatively different: the
  second event is never sent at all. If the window is too long, a real
  second crossing (two robots close together, a robot re-entering) is
  silently dropped instead of harmlessly ignored — trading a visible
  non-issue today for a potentially invisible one. Worth explicitly
  working out what that failure looks like (and how it'd be noticed)
  before picking a window width.

**Reassessed, 2026-08-07.** The original observation's premise — that
extra events are "avoidable network-side pressure for no benefit" — was
written when per-event transport was HTTP (a fresh TCP connection per
trigger, ~267ms baseline latency). This issue's own WS re-run, already
recorded above, shows that premise no longer applies: 200/200 duplicate
events arrived cleanly at ~7-8ms latency, no queueing, no drops. Under
that transport, a redundant trigger costs almost nothing to send and is
already handled correctly (harmlessly ignored once out of `RUNNING`).
Combined with multiple triggers from one robot being rare in practice,
building a source-side lock-out to suppress them is solving a problem
that, under the current transport, barely costs anything to leave alone —
if anything, a duplicate is a free extra delivery attempt, closer to a
reliability feature than a problem. Deprioritized, not formally closed (a
genuinely gapped robot could still exist and this reasoning would need
revisiting if one shows up in practice). The lock-out design (and its two
open concerns above) is not being pursued.

**Verification.** N/A — not being pursued (see Reassessed, 2026-08-07,
above), not merely not-yet-implemented. No planned re-run.

### Issue: ARM/START shared-board queueing

**[RESOLVED — no separate action needed beyond persistent connections]**
*(was part of Observation #9)*

**Observation.** One hesperus board can serve both `ARM` and `START`
gates; a robot can cross the `ARM` gate and then the `START` gate as little
as ~200ms apart. Both sensors share one board's `networkQueue`, so this
routinely (not just occasionally) queued the `START` event behind the
`ARM` event's in-flight send cycle — at ~230-270ms per cycle, a 200ms gap
was squarely inside the range where the second event queues.

**Confirmation.** `ares-pulse-generator`'s `trial_arm_then_start`, 99
trigger pairs, edges 200ms apart. HTTP baseline
(`test-data/arm-then-start-test-20260630-1522*.txt`): `ARM` latency — mean
266.6ms, median 266.2ms, stdev 3.4ms — matches the solo-trigger baseline
exactly. `START` latency — mean 319.7ms, median 318.8ms, stdev 6.3ms —
consistently ~53ms higher than `ARM` on essentially every pair. The
tightness of both stdevs (3-6ms) confirmed this was a near-deterministic
queueing offset from `START` waiting out the remainder of `ARM`'s in-flight
send cycle, not ordinary network jitter.

**Re-run under WebSockets, 2026-07-31**
(`test-data/arm-then-start-test-ws-20260631-1045*.txt`): same 100 pairs,
200ms apart. `ARM` — mean 6.7ms, median 5.8ms, stdev 2.0ms. `START` — mean
8.2ms, median 6.7ms, stdev 3.9ms. The `ARM`/`START` offset drops from
~53ms (HTTP) to **~1.5ms**. Unlike the HTTP baseline, no cold-connection
outlier appears at the first pair — steady-state latency from pair 1
onward. One isolated `START` outlier at 37.7ms (pair 39 of 100) — see the
WS-jitter issue below.

**Resolution.** No separate fix needed beyond the persistent-connections
issue above, already shipped. Order was always preserved regardless (FIFO
drain, `ARM`'s full cycle completes before `START`'s begins), so this never
risked `START` arriving before `ARM` or otherwise confusing the state
machine — it only ever delayed *when* `START`'s request landed, never
*what* timestamp it carried, since `START.tsf_us` is captured at the true
trigger instant regardless of transmission time. This delay never touched
the committed `GOAL.tsf_us − START.tsf_us` result (see the displayed-time
issue above, which computes that independently of `run_sw`). The live
display shows this delay as an ordinary part of its receipt-time lag by
design.

**Verification.** Covered by the data above (same re-run also serves as
this issue's own bench confirmation).

### Issue: AP radio interruption silently gates triggers for up to 5 minutes

**[RESOLVED]**
*(was Observation #10; Recommendation 9)*

**Observation.** Found during persistent-connection bring-up bench
testing, while deliberately testing reconnect-after-Wi-Fi-drop — unrelated
to WebSockets itself, this is a pre-existing property of hesperus's
clock-disciplining code (`main.cpp`'s "TIMELINE SANITY AUDIT ENGINE") that
the test happened to expose clearly for the first time.
`MIN_PLAUSIBLE_TSF = 300000000` (`hesperus-timing-gate/src/main.cpp`) is
the threshold a fresh `tsf_observed` reading must clear before hesperus
will trust it as an initial baseline (`has_initial_baseline`) — until that
baseline exists, every trigger is unconditionally dropped
(`[CRITICAL DROP] Baseline missing or un-synchronized. Packet dropped.`),
before ever reaching the network send code. The assumption behind the
threshold was that an implausibly-small TSF value means the Wi-Fi stack
hasn't synced yet (e.g. very early boot) — but **`esp_wifi_get_tsf_time()`
tracks time since the AP's own TSF epoch, not since hesperus associated**,
so anything that resets the AP's TSF resets this for every station on it,
regardless of how briefly.

**Confirmation.** Toggling only the AP's radio off and back on (not a full
router reboot/power-cycle) was enough to reset its TSF epoch. hesperus's
own log shows the exact boundary:
```
[T=297670ms] [PLAUSIBILITY REJECT] TSF 297670304 too low. Wi-Fi stack un-synchronized.
[T=297670ms] [CRITICAL DROP] Baseline missing or un-synchronized. Packet dropped.
[T=302817ms] [INITIALIZED] Valid Baseline Coordinates Locked: 302817313
```
Rejected at TSF=297,670,304 (<300,000,000), accepted 5,147,009us later
(matching the heartbeat timer's ~5147ms period exactly) — recovery is
bounded and self-healing, but takes the *entire* 300-second threshold from
the moment the AP's radio was disrupted, not from whenever hesperus itself
reconnects (hesperus's own Wi-Fi reconnected in ~3.4s in this same test;
TSF wasn't trusted again for another ~4.9 minutes after that). Separately,
this same outage also triggered hesperus's existing "stuck in SYN mode
>10s" watchdog (`main.cpp`'s "PATCH 2", `ESP.restart()`) — a full board
reboot, not just a Wi-Fi radio reset — since a real outage keeps the board
in SYN/extrapolated-time mode well past the 10s threshold; two independent
mechanisms compounding the total time-to-recovery. **Practical
implication**: any AP-side radio interruption — not just a full power
outage — could leave every gate on the network dropping triggers silently
for up to 5 minutes, with no operator-visible indication beyond the serial
debug log. At a real contest this reads as "the gates just stopped
working" for a very long five minutes.

**Resolution.** Decided 2026-07-31, re-examined from first principles
(the original 300-second value's justification isn't documented anywhere
in the code and isn't recalled either): the scenario the gate is actually
trying to guard against is the AP's TSF epoch resetting *mid-run*. On this
system's single-AP topology, the only plausible way for that to happen is
an AP radio failure/reset — which takes down Wi-Fi for every gate on the
network simultaneously, a total system failure regardless of what
hesperus's TSF logic does. A magnitude gate that stays shut for 5 minutes
doesn't protect against that (nothing left to protect at that point); it
only adds unnecessary downtime on top of it, and a much smaller, more
common trigger (a brief AP radio blip well short of a full outage) already
demonstrates this. The residual risk a gate might still be defending
against — a genuinely tiny/implausible `tsf_observed` value trusted right
after reconnect — isn't plausible for a single, non-mesh AP: the client
radio's own reconnection already takes several seconds, during which the
AP's TSF clock (if running at all) will have advanced well past any
near-zero danger zone.

**Decision: trust `tsf_observed` immediately on a fresh Wi-Fi association
event** rather than gating on the value's absolute magnitude at all.
Implemented 2026-07-31 (`hesperus-timing-gate/src/main.cpp`, the
initial-baseline gate at `!has_initial_baseline`): the `tsf_observed >=
MIN_PLAUSIBLE_TSF` check is replaced with `WiFi.status() == WL_CONNECTED`,
matching the connectivity check already used elsewhere in the file — since
this branch only ever runs while no baseline exists yet, checking current
connectivity right there achieves "trust once actually connected" without
needing a separate `WiFi.onEvent` handler/flag. Scoped narrowly to this
one gate — a second, separate use of `MIN_PLAUSIBLE_TSF` exists in the
"escape hatch" SYN-mode recovery heuristic (PATCH 1, `main.cpp:401-415`)
and was deliberately left untouched, not being what this issue documents
as the bug.

**Verification.** The original plan was a second ESP32 as a soft AP, fully
under test control, to check whether there is *any* way to take an AP's
radio down (even briefly) without resetting its TSF epoch. No spare ESP32
was available, so this was superseded the same day by a direct test: the
real venue AP's radio was toggled off and back on directly while collecting
logs from cerberus and the GOAL-board hesperus unit. **Bench-confirmed,
2026-07-31.** hesperus's GOAL board logged `[INITIALIZED] Valid Baseline
Coordinates Locked: 2408999` — a TSF value far below the old
`MIN_PLAUSIBLE_TSF` (300,000,000) that would previously have been rejected
outright — accepted immediately because the new gate only checks
`WiFi.status() == WL_CONNECTED`, not magnitude. This confirmed the soft-AP
assumption above didn't need to be separately proven: the real AP's
radio-only toggle did reset its TSF epoch (matching the original finding)
and the new code recovered from it immediately.

Full recovery sequence observed: losing AP sync tripped the existing
"PATCH 2" `[ROLLOVER FAULT]` watchdog after 10s stuck in `DISCIPLINED SYN`
mode, forcing a full `ESP.restart()` (expected, independent of this fix).
Post-reboot, the separate 15s "Wi-Fi link dead" watchdog cycled at least 3
times (~45s+) while the AP radio was still coming back up, consistent with
its normal ~30s recovery. Once reconnected: `[NETWORK] Link Active!` at
T=1136ms, mDNS resolved at T=2051ms, baseline locked at T=2775ms — **under
2 seconds after Wi-Fi actually came back**, not the old 5-minute wait.
Cerberus itself (never rebooted, just lost/regained Wi-Fi) reconnected in
~916ms and had both gates' WS clients back within a few seconds. One new,
unexplained data point from this same test: cerberus logged
`[E][ESPmDNS.cpp:148] addService(): Failed adding service http.tcp.`
immediately after reconnecting (non-fatal, mDNS started cleanly the very
next line) — see the WS-jitter issue below, flagged not investigated
further.

**Unexplained recurrence, 2026-08-03** (`test-data/spam-tests/{cerberus-6,
hesperus-start-6,hesperus-goal-6}.log`, the 5000-run no-spammer baseline
trial — see the acceptance-criteria section's results). The 5000 runs
themselves were flawless (5000/5000 ARM/START/GOAL, zero retries, zero
drops, one single WS disconnect/reconnect in the entire ~6-hour test). But
~64-84 minutes *after* the last logged race — no triggers in flight, both
boards just sitting connected and idle — both hesperus boards independently
logged `[AUDIT ALERT] Temporal Disruption!` (drift 515-814us) and dropped
into `[DISCIPLINED SYN]` extrapolated-TSF mode; the goal board's persisted
past 10s and tripped the same `[ROLLOVER FAULT]` reboot watchdog described
above, recovering cleanly within seconds (fresh boot, reconnect, valid
baseline re-locked). Same mechanism as the resolved bug above, but the
*trigger* this time is unidentified: confirmed with the user that the AP
showed nothing amiss and the beacon spammer was not running at the time.
Whatever caused the AP's TSF to hiccup (or caused hesperus's own reading of
it to) is unknown — logged here as an open, low-priority, self-healing
curiosity rather than investigated further, consistent with how the
WS-jitter issue below treats similarly rare, non-committed-time-affecting
blips. Worth re-checking if it recurs.

**Recurred, 2026-08-04** (session 8's single-spammer 5000-run trial, see
the acceptance-criteria section's "Results, session 8") — same idle-only
signature, ~65 minutes after the last race this time, goal board only. New
this session: `[AUDIT ALERT] Temporal Disruption!` also fired 6 further
times *during* active running (5 goal-board, 1 start-board), each a single
rejected sample with immediate self-correction and no reboot or operational
impact — one of the six is fully explained by an 8.7-minute operator pause
mid-trial (confirmed with the user; see "Results, session 8"), but the
other five occur with no identified trigger nearby. Still self-healing and
still not investigated further, but now established as something that
happens during normal operation too, not just post-trial idle.
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

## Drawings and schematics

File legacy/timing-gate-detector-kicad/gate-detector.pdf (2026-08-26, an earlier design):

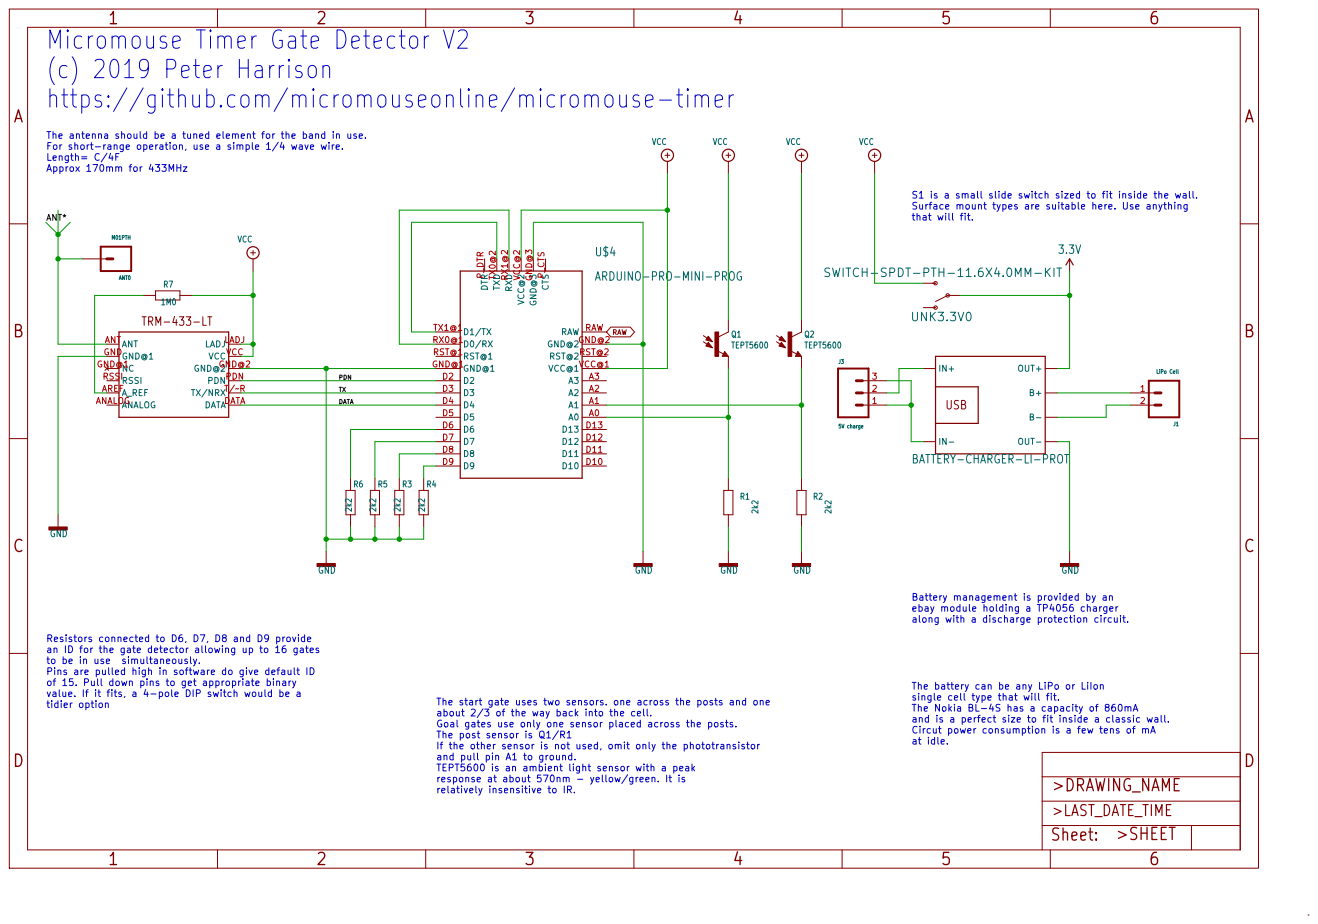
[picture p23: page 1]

at idle. Micromouse Timer Gate Detector V2
(c) 2019 Peter Harrison
https://github.com/micromouseonline/micromouse-timer

that will fit. The antenna should be a tuned element for the band in use. For short-range operation, use a simple 1/4 wave wire.

S1 is a small slide switch sized to fit inside the wall. Surface mount types are suitable here. Use anything

ARDUINO-PRO-MINI-PROG R7

ebay module holding a TP4056 charger
along with a discharge protection circuit.

Resistors connected to D6, D7, D8 and D9 provide
an ID for the gate detector allowing up to 16 gates
to be in use simultaneously.
Pins are pulled high in software do give default ID
of 15. Pull down pins to get appropriate binary
value. If it fits, a 4-pole DIP switch would be a
tidier option

The battery can be any LiPo or LiIon
single cell type that will fit.
The Nokia BL-4S has a capacity of 860mA
and is a perfect size to fit inside a classic wall.
Circut power consumption is a few tens of mA

The start gate uses two sensors. one across the posts and one
about 2/3 of the way back into the cell.
Goal gates use only one sensor placed across the posts.
The post sensor is Q1/R1
If the other sensor is not used, omit only the phototransistor
and pull pin A1 to ground.
TEPT5600 is an ambient light sensor with a peak
response at about 570nm - yellow/green. It is
relatively insensitive to IR.

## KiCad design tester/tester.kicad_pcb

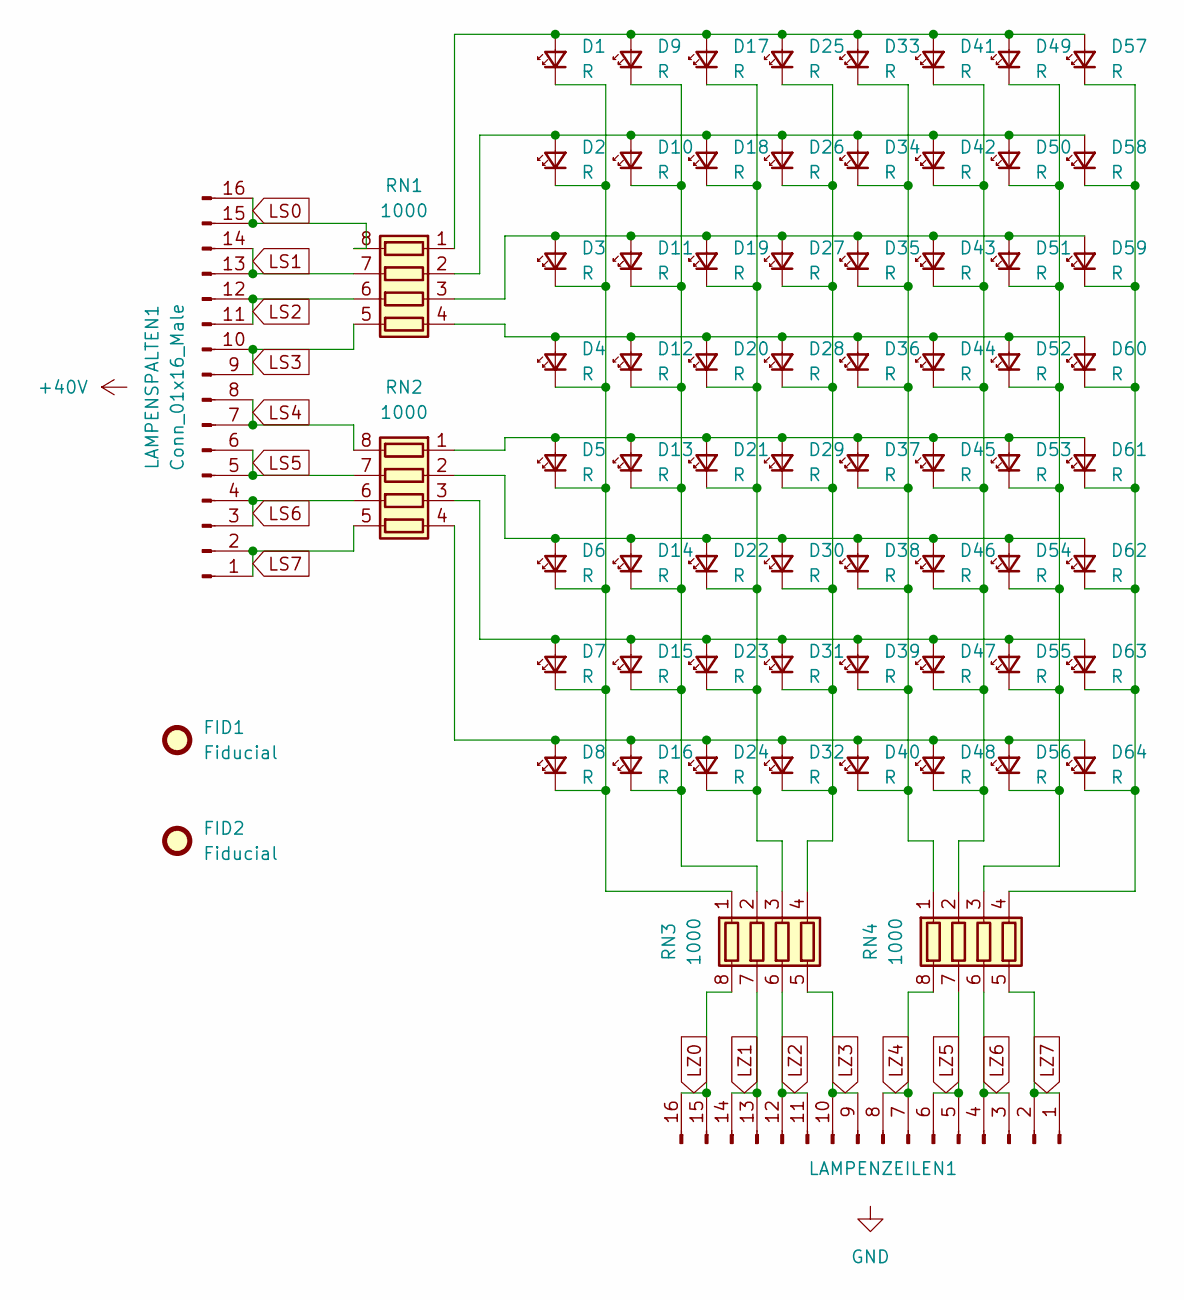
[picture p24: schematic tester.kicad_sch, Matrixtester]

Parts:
D1, D2, D3, D4, D5, D6, D7, D8, D9, D10, D11, D12, D13, D14, D15, D16, D17, D18, D19, D20, D21, D22, D23, D24, D25, D26, D27, D28, D29, D30, D31, D32, D33, D34, D35, D36, D37, D38, D39, D40, D41, D42, D43, D44, D45, D46, D47, D48, D49, D50, D51, D52, D53, D54, D55, D56, D57, D58, D59, D60, D61, D62, D63, D64: R; LED_0603_1608Metric_Pad1.05x0.95mm_HandSolder
FID1: Fiducial; Fiducial_Cross_1.5mm_Mask2mm
FID2: Fiducial; Fiducial_0.5mm_Mask1.5mm
LAMPENSPALTEN1: Conn_01x16_Male; Lumberg_MSF_B16B-MSF-A_1x16_P2.50mm_Vertical
LAMPENZEILEN1: Conn_01x16_Pin; Lumberg_MSF_B16B-MSF-A_1x16_P2.50mm_Vertical
RN1, RN2, RN3, RN4: 1000; R_Array_Concave_4x0603

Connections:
LS0: LAMPENSPALTEN1.15, LAMPENSPALTEN1.16, RN1.8 (R1.2)
LS1: LAMPENSPALTEN1.13, LAMPENSPALTEN1.14, RN1.7 (R2.2)
LS2: LAMPENSPALTEN1.11, LAMPENSPALTEN1.12, RN1.6 (R3.2)
LS3: LAMPENSPALTEN1.9, LAMPENSPALTEN1.10, RN1.5 (R4.2)
LS4: LAMPENSPALTEN1.7, LAMPENSPALTEN1.8, RN2.8 (R1.2)
LS5: LAMPENSPALTEN1.5, LAMPENSPALTEN1.6, RN2.7 (R2.2)
LS6: LAMPENSPALTEN1.3, LAMPENSPALTEN1.4, RN2.6 (R3.2)
LS7: LAMPENSPALTEN1.1, LAMPENSPALTEN1.2, RN2.5 (R4.2)
LZ0: LAMPENZEILEN1.15, LAMPENZEILEN1.16, RN3.8 (R1.2)
LZ1: LAMPENZEILEN1.13, LAMPENZEILEN1.14, RN3.7 (R2.2)
LZ2: LAMPENZEILEN1.11, LAMPENZEILEN1.12, RN3.6 (R3.2)
LZ3: LAMPENZEILEN1.9, LAMPENZEILEN1.10, RN3.5 (R4.2)
LZ4: LAMPENZEILEN1.7, LAMPENZEILEN1.8, RN4.8 (R1.2)
LZ5: LAMPENZEILEN1.5, LAMPENZEILEN1.6, RN4.7 (R2.2)
LZ6: LAMPENZEILEN1.3, LAMPENZEILEN1.4, RN4.6 (R3.2)
LZ7: LAMPENZEILEN1.1, LAMPENZEILEN1.2, RN4.5 (R4.2)
unnamed: D1.2 (A), D9.2 (A), D17.2 (A), D25.2 (A), D33.2 (A), D41.2 (A), D49.2 (A), D57.2 (A), RN1.1 (R1.1)
unnamed: D1.1 (K), D2.1 (K), D3.1 (K), D4.1 (K), D5.1 (K), D6.1 (K), D7.1 (K), D8.1 (K), RN3.1 (R1.1)
unnamed: D2.2 (A), D10.2 (A), D18.2 (A), D26.2 (A), D34.2 (A), D42.2 (A), D50.2 (A), D58.2 (A), RN1.2 (R2.1)
unnamed: D9.1 (K), D10.1 (K), D11.1 (K), D12.1 (K), D13.1 (K), D14.1 (K), D15.1 (K), D16.1 (K), RN3.2 (R2.1)
unnamed: D3.2 (A), D11.2 (A), D19.2 (A), D27.2 (A), D35.2 (A), D43.2 (A), D51.2 (A), D59.2 (A), RN1.3 (R3.1)
unnamed: D4.2 (A), D12.2 (A), D20.2 (A), D28.2 (A), D36.2 (A), D44.2 (A), D52.2 (A), D60.2 (A), RN1.4 (R4.1)
unnamed: D5.2 (A), D13.2 (A), D21.2 (A), D29.2 (A), D37.2 (A), D45.2 (A), D53.2 (A), D61.2 (A), RN2.1 (R1.1)
unnamed: D6.2 (A), D14.2 (A), D22.2 (A), D30.2 (A), D38.2 (A), D46.2 (A), D54.2 (A), D62.2 (A), RN2.2 (R2.1)
unnamed: D7.2 (A), D15.2 (A), D23.2 (A), D31.2 (A), D39.2 (A), D47.2 (A), D55.2 (A), D63.2 (A), RN2.3 (R3.1)
unnamed: D8.2 (A), D16.2 (A), D24.2 (A), D32.2 (A), D40.2 (A), D48.2 (A), D56.2 (A), D64.2 (A), RN2.4 (R4.1)
unnamed: D17.1 (K), D18.1 (K), D19.1 (K), D20.1 (K), D21.1 (K), D22.1 (K), D23.1 (K), D24.1 (K), RN3.3 (R3.1)
unnamed: D25.1 (K), D26.1 (K), D27.1 (K), D28.1 (K), D29.1 (K), D30.1 (K), D31.1 (K), D32.1 (K), RN3.4 (R4.1)
unnamed: D33.1 (K), D34.1 (K), D35.1 (K), D36.1 (K), D37.1 (K), D38.1 (K), D39.1 (K), D40.1 (K), RN4.1 (R1.1)
unnamed: D41.1 (K), D42.1 (K), D43.1 (K), D44.1 (K), D45.1 (K), D46.1 (K), D47.1 (K), D48.1 (K), RN4.2 (R2.1)
unnamed: D49.1 (K), D50.1 (K), D51.1 (K), D52.1 (K), D53.1 (K), D54.1 (K), D55.1 (K), D56.1 (K), RN4.3 (R3.1)
unnamed: D57.1 (K), D58.1 (K), D59.1 (K), D60.1 (K), D61.1 (K), D62.1 (K), D63.1 (K), D64.1 (K), RN4.4 (R4.1)

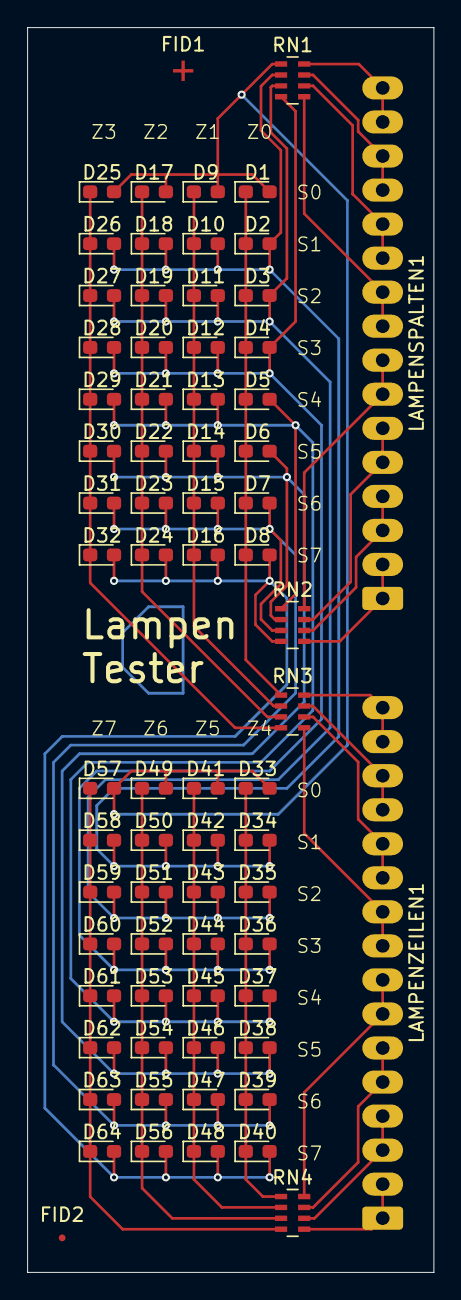
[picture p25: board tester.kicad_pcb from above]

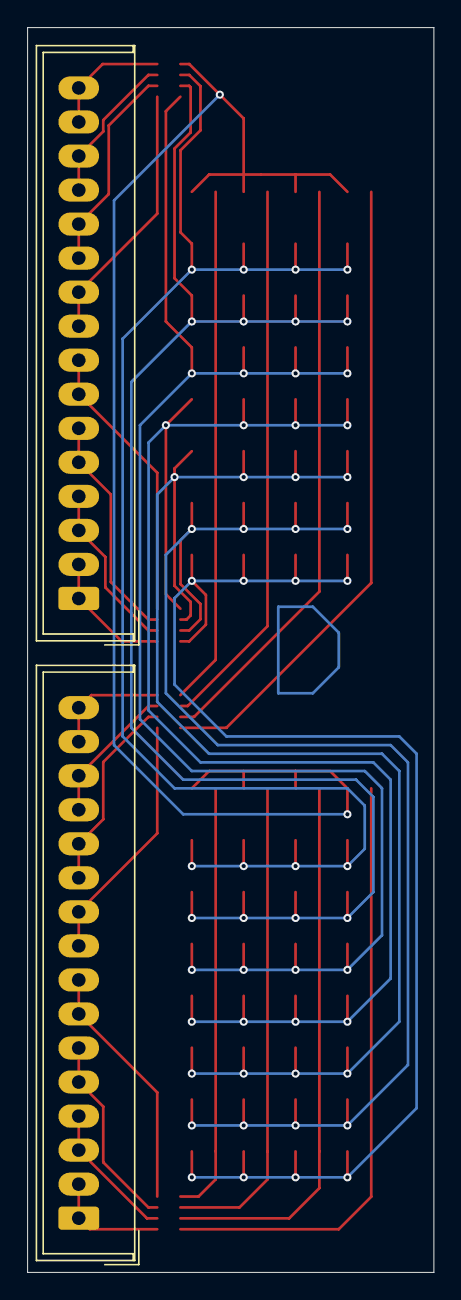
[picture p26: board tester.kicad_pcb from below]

Board: 2 copper layers, 29.8 x 91.4 mm, 72 parts (2 on the bottom side), 32 nets.

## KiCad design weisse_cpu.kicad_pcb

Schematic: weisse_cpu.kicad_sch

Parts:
AUSWERFER+SPERRMAG1: Conn_01x06_Pin; PinHeader_1x06_P2.54mm_Vertical
BATTERIE2: Battery_Cell; Batterie
C1, C76, C110, C130, C131, C159, C160, C161: C; C_Rect_L9.0mm_W2.5mm_P7.50mm_MKT
C2, C3, C49: C; CP_Radial_Tantal_D4.5mm_P2.50mm
C4, C5, C6, C7, C8, C9, C10, C11, C143, C144, C145, C146, C147, C148, C149, C150, C151, C152, C153, C154, C155, C156, C157, C158: C; C_Axial_L3.8mm_D2.6mm_P7.50mm_Horizontal
C20, C21, C22, C23, C24, C25, C26, C27: C; C_Rect_L7.0mm_W2.0mm_P5.00mm
C48: C; CP_Radial_Tantal_D4.5mm_P5.00mm
D1, D2, D4, D5, D6, D7, D8, D10, D11, D12, D13, D14, D15, D16, D17, D18, D19, D25, D26, D28, D29, D50, D51, D52, D73, D74, D75, D76, D77, D78, D79, D80, D81, D82, D83, D84, D85, D86, D87, D88, D89, D90, D91, D92, D93, D94, D95, D96, D97, D98, D99, D100, D101, D102, D103, D104, D105, D106, D107, D108, D109, D110, D111, D112: D; D_A-405_P7.62mm_Horizontal
D3, D27: D; BigDiode
DM1, DM2: DAN_801; SIP9_Housing
EINGAENGE1: Conn_01x08_Male; PinHeader_1x08_P2.54mm_Vertical
GONG1: Conn_01x02_Pin; PinHeader_1x02_P2.54mm_Vertical; not fitted
ICA2: LM324; DIP-14_W7.62mm
ICA3: PAL20L8; DIP-24_W15.24mm
ICA7: 4066; DIP-14_W7.62mm
ICA8: 40106; DIP-14_W7.62mm
ICA9: CNY17-1; DIP-6_W7.62mm
ICB2: 8085; DIP-40_W15.24mm
ICB4: 74LS245; DIP-20_W7.62mm
ICB5: 74LS373; DIP-20_W7.62mm
ICB8: ICM7555xP; DIP-8_W7.62mm
ICB9, ICB10: 4066; DIP-14_W7.62mm
ICC3: 74LS04; DIP-14_W7.62mm
ICC4: 74LS00; DIP-14_W7.62mm
ICC5: 2764; DIP-24_W15.24mm
ICC6: CXK5816PN-12L; DIP-24_W15.24mm
ICC8: 74LS42; DIP-16_W7.62mm
ICC10: 4066; DIP-14_W7.62mm
ICD3: 74LS257; DIP-16_W7.62mm
ICD4: 74LS244; DIP-20_W7.62mm
ICD6: 27128; DIP-28_W15.24mm
ICD8: CD4051B; DIP-16_W7.62mm
ICD10: 4066; DIP-14_W7.62mm
ICE2: 8256; DIP-40_W15.24mm
ICE4: 74125; DIP-14_W7.62mm
ICE5: 74LS42; DIP-16_W7.62mm
ICE6: 27128; DIP-28_W15.24mm
ICE10: 4066; DIP-14_W7.62mm
ICF2: LM324; DIP-14_W7.62mm
ICF3: 4028; DIP-16_W7.62mm
ICF4-2: 4013; DIP-14_W7.62mm
ICF5: 74LS42; DIP-16_W7.62mm
ICF8: CD4051B; DIP-16_W7.62mm
ICF10: 4066; DIP-14_W7.62mm
ICG1, ICG2, ICG4, ICG4-1: LM324; DIP-14_W7.62mm
ICG3: 4051; DIP-16_W7.62mm
ICG5: DIP-40_W15.24mm
ICG8-1: 74LS290; DIP-14_W7.62mm
ICG8-2: 4040; DIP-16_W7.62mm
ICG9: DIP-16_W7.62mm
ICG10-1, ICG10-2: 4066; DIP-14_W7.62mm
ICH1: 4098; DIP-16_W7.62mm
ICH2: LM324; DIP-14_W7.62mm
ICH3: 4040; DIP-16_W7.62mm
ICH4-1: ULN2004A; DIP-16_W7.62mm
ICH4-2: 4520; DIP-16_W7.62mm
ICH5: 74LS138; DIP-16_W7.62mm
ICH6: 74AHC273; DIP-20_W7.62mm
ICH8: CD74HC4067M; SOIC-24W_7.5x15.4mm_P1.27mm
ICH10: 4066; DIP-14_W7.62mm
ICJ5, ICJ6: 74AHC273; DIP-20_W7.62mm
ICK4: 4013; DIP-14_W7.62mm
ICK5, ICK6, ICK7, ICK8, ICK11: LM324; DIP-14_W7.62mm
ICL4, ICL6, ICL9: 4093; DIP-14_W7.62mm
ICL5, ICL7: LM324; DIP-14_W7.62mm
ICL8: 4013; DIP-14_W7.62mm
ICL10: NE556; DIP-14_W7.62mm
ICL11: Opamp_Quad; DIP-14_W7.62mm
LAMPENSPALTEN1: Conn_01x16_Male; PinHeader_1x16_P2.54mm_Vertical
LAMPENZEILEN1: Conn_01x16_Pin; PinHeader_1x16_P2.54mm_Vertical
LAUTSPRECHER1: Conn_01x06_Pin; PinHeader_1x06_P2.54mm_Vertical
LED1, LED2, LED3, LED4, LED5: LED; LED_D5.0mm
LEISTUNGSAUSGAENGE1: Conn_01x10_Pin; PinHeader_1x10_P2.54mm_Vertical; not fitted
LEISTUNGSNETZ1: Conn_01x08_Male; PinHeader_1x08_P2.54mm_Vertical
LEUCHTZIFFERNANZEIGE1: Conn_01x12_Pin; PinHeader_1x12_P2.54mm_Vertical
MATRIX-EINGAENGE1: Conn_01x06_Pin; PinHeader_1x06_P2.54mm_Vertical; not fitted
MUENZANNAHME1: Conn_01x20_Pin; PinHeader_1x20_P2.54mm_Vertical
Q1: Crystal; Crystal_AT310_D3.0mm_L10.0mm_Vertical
Q2: Crystal; Crystal_HC18-U_Vertical
R1, R2, R10, R11, R12, R13, R27, R28, R29: 1,2k 5%; R_Axial_DIN0414_L11.9mm_D4.5mm_P20.32mm_Horizontal
R3, R17: R; R_Axial_DIN0204_L3.6mm_D1.6mm_P7.62mm_Horizontal
R4, R5, R6, R7: R; R_Axial_DIN0207_L6.3mm_D2.5mm_P10.16mm_Horizontal
R15, R20, R21, R123: 1 kΩ ±5%; R_Axial_DIN0207_L6.3mm_D2.5mm_P10.16mm_Horizontal
R16, R86, R150: 100 kΩ ±5%; R_Axial_DIN0207_L6.3mm_D2.5mm_P10.16mm_Horizontal
R22, R84, R124: 10 kΩ ±5%; R_Axial_DIN0207_L6.3mm_D2.5mm_P10.16mm_Horizontal
R23: 320 kΩ ±5%; R_Axial_DIN0207_L6.3mm_D2.5mm_P10.16mm_Horizontal
R40: 15 2%; BigResistor
R41, R65, R66, R90, R100: R; BigResistor
R82: 3 kΩ ±5%; R_Axial_DIN0207_L6.3mm_D2.5mm_P10.16mm_Horizontal
R83: 180 Ω ±5%; R_Axial_DIN0207_L6.3mm_D2.5mm_P10.16mm_Horizontal
R85: 27 kΩ ±5%; R_Axial_DIN0207_L6.3mm_D2.5mm_P10.16mm_Horizontal
R121: 220 kΩ ±5%; R_Axial_DIN0207_L6.3mm_D2.5mm_P10.16mm_Horizontal
R122: 1 MΩ ±5%; R_Axial_DIN0207_L6.3mm_D2.5mm_P10.16mm_Horizontal
R129: 1 kΩ ±5%; R_Axial_DIN0309_L9.0mm_D3.2mm_P15.24mm_Horizontal
R130: 51; R_Axial_DIN0414_L11.9mm_D4.5mm_P20.32mm_Horizontal
R135: 100 ±5%; R_Axial_DIN0414_L11.9mm_D4.5mm_P20.32mm_Horizontal
R136, R137: 200 Ω ±5%; R_Axial_DIN0414_L11.9mm_D4.5mm_P20.32mm_Horizontal
R140: 220 Ω ±5%; R_Axial_DIN0207_L6.3mm_D2.5mm_P10.16mm_Horizontal
R148: 3,3M 5%; R_Axial_DIN0207_L6.3mm_D2.5mm_P10.16mm_Horizontal
RM2, RM20: R_Network04; R_Array_SIP5
RM3, RM5, RM7, RM11, RM12, RM13, RM21, RM50, RM56, RM57, RM58, RM66, RM80, RM82, RM84: R_Network08; R_Array_SIP9
RM4, RM6, RM8, RM10, RM81, RM83, RM85: R_Pack08; DIP-16_W7.62mm
RN1: R_Network08; R_Array_SIP9
SERIELLE_DATEN1: Conn_01x08_Pin; PinHeader_1x08_P2.54mm_Vertical
SERVICEANZEIGE+TASTATUR1: Conn_01x20_Male; PinHeader_1x20_P2.54mm_Vertical
SIGNALNETZ1: Conn_01x06_Male; PinHeader_1x06_P2.54mm_Vertical
SW1: SW_DIP_x04; SW_DIP_SPSTx04_Slide_9.78x12.34mm_W7.62mm_P2.54mm
TASTEN1: Conn_01x06_Pin; PinHeader_1x06_P2.54mm_Vertical
TR1, TR2, TR10, TR11, TR12, TR25, TR26: BDX34B; TO-220-3_Vertical
TR3, TR14, TR15, TR16, TR30, TR31, TR33, TR34, TR85: BC237; TO-92_Inline
TR13: BDX54C; TO-220-3_Vertical
TR27: BD140; TO-126-3_Vertical
TR29, TR65, TR66: BD139; TO-126-3_Vertical
TR32: BD679; TO-126-3_Vertical
TR40: BC557; TO-92_Inline
TR55, TR56, TR70, TR71, TR72, TR73, TR80, TR81, TR82, TR83, TR95, TR96, TR97: Q_NPN_Darlington_BCE; TO-220-3_Vertical
TR84, TR87: NMOS; BigTransistor
TR86: BC327; TO-92_Inline
TUERSCHALTER+SPIELZAEHLER1: Conn_01x04_Pin; PinHeader_1x04_P2.54mm_Vertical
TY1, TY2, TY5, TY6, TY7, TY8, TY15, TY16: TIC126; TO-220-3_Vertical
WALZENANSTEUERUNG1: Conn_01x20_Pin; PinHeader_1x20_P2.54mm_Vertical
ZUSATZTASTEN1: Conn_01x08_Pin; PinHeader_1x08_P2.54mm_Vertical
ZUSATZWALZEN1: Conn_01x12_Pin; PinHeader_1x12_P2.54mm_Vertical; not fitted

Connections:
+5V: LEUCHTZIFFERNANZEIGE1.3, SERIELLE_DATEN1.1, SERVICEANZEIGE+TASTATUR1.2, SIGNALNETZ1.5, SIGNALNETZ1.6
+12V: C161.1, EINGAENGE1.1, LAUTSPRECHER1.2, LEUCHTZIFFERNANZEIGE1.4, MUENZANNAHME1.4, SERIELLE_DATEN1.8, SIGNALNETZ1.4, TASTEN1.6, TUERSCHALTER+SPIELZAEHLER1.3, ZUSATZTASTEN1.2
+15V: SIGNALNETZ1.3
+24V: LAUTSPRECHER1.1, LEISTUNGSAUSGAENGE1.10, LEISTUNGSNETZ1.4, LEISTUNGSNETZ1.5, MUENZANNAHME1.2, SERIELLE_DATEN1.4, WALZENANSTEUERUNG1.12
+48V: AUSWERFER+SPERRMAG1.1, EINGAENGE1.6, GONG1.1, LEISTUNGSNETZ1.6, LEISTUNGSNETZ1.7, LEISTUNGSNETZ1.8, R40.2, SERIELLE_DATEN1.2, TUERSCHALTER+SPIELZAEHLER1.4, WALZENANSTEUERUNG1.14
A0: ICB5.2 (O0), ICC5.8 (A0), ICC6.8 (A0), ICD6.10 (A0), ICE6.10 (A0), RM58.9 (R8)
A1: ICB5.5 (O1), ICC5.7 (A1), ICC6.7 (A1), ICD6.9 (A1), ICE6.9 (A1), RM58.8 (R7)
A2: ICB5.6 (O2), ICC5.6 (A2), ICC6.6 (A2), ICD6.8 (A2), ICE6.8 (A2), RM58.7 (R6)
A3: ICB5.9 (O3), ICC5.5 (A3), ICC6.5 (A3), ICD6.7 (A3), ICE6.7 (A3), RM58.6 (R5)
A4: ICB5.12 (O4), ICC5.4 (A4), ICC6.4 (A4), ICD6.6 (A4), ICE6.6 (A4), RM58.5 (R4)
A5: ICB5.15 (O5), ICC5.3 (A5), ICC6.3 (A5), ICD6.5 (A5), ICE6.5 (A5), RM58.4 (R3)
A6: ICB5.16 (O6), ICC5.2 (A6), ICC6.2 (A6), ICD6.4 (A6), ICE6.4 (A6), RM58.3 (R2)
A7: ICB5.19 (O7), ICC5.1 (A7), ICC6.1 (A7), ICD6.3 (A7), ICE6.3 (A7), RM58.2 (R1)
A8: ICC5.23 (A8), ICC6.23 (A8), ICD6.25 (A8), ICE6.25 (A8), RM57.2 (R1)
A9: ICC5.22 (A9), ICC6.22 (A9), ICD6.24 (A9), ICE6.24 (A9), RM57.3 (R2)
A10: ICC5.19 (A10), ICC6.19 (A10), ICD6.21 (A10), ICE6.21 (A10), RM57.6 (R5)
A11: ICC5.21 (A11), ICD6.23 (A11), ICE6.23 (A11), RM57.4 (R3)
A12: ICD6.2 (A12), ICE6.2 (A12)
A13: ICD6.26 (A13), ICE6.26 (A13)
AD0: ICB2.12 (AD0), ICB4.2 (A0), ICB5.3 (D0)
AD1: ICB2.13 (AD1), ICB4.3 (A1), ICB5.4 (D1)
AD2: ICB2.14 (AD2), ICB4.4 (A2), ICB5.7 (D2)
AD3: ICB2.15 (AD3), ICB4.5 (A3), ICB5.8 (D3)
AD4: ICB2.16 (AD4), ICB4.6 (A4), ICB5.13 (D4)
AD5: ICB2.17 (AD5), ICB4.7 (A5), ICB5.14 (D5)
AD6: ICB2.18 (AD6), ICB4.8 (A6), ICB5.17 (D6)
AD7: ICB2.19 (AD7), ICB4.9 (A7), ICB5.18 (D7)
D0: ICB4.18 (B0), ICC5.9 (D0), ICC6.9 (I/O1), ICD6.11 (D0), ICE6.11 (D0), ICG5.12 (DB0)
D1: ICB4.17 (B1), ICC5.10 (D1), ICC6.10 (I/O2), ICD6.12 (D1), ICE6.12 (D1), ICG5.13 (DB1)
D2: ICB4.16 (B2), ICC5.11 (D2), ICC6.11 (I/O3), ICD6.13 (D2), ICE6.13 (D2), ICG5.14 (DB2)
D3: ICB4.15 (B3), ICC5.13 (D3), ICC6.13 (I/O4), ICD6.15 (D3), ICE6.15 (D3), ICG5.15 (DB3)
D4: ICB4.14 (B4), ICC5.14 (D4), ICC6.14 (I/O5), ICD6.16 (D4), ICE6.16 (D4), ICG5.16 (DB4), RM57.5 (R4)
D5: ICB4.13 (B5), ICC5.15 (D5), ICC6.15 (I/O6), ICD6.17 (D5), ICE6.17 (D5), ICG5.17 (DB5), RM57.7 (R6)
D6: ICB4.12 (B6), ICC5.16 (D6), ICC6.16 (I/O7), ICD6.18 (D6), ICE6.18 (D6), ICG5.18 (DB6), RM57.9 (R8)
D7: ICB4.11 (B7), ICC5.17 (D7), ICC6.17 (I/O8), ICD6.19 (D7), ICE6.19 (D7), ICG5.19 (DB7), RM57.8 (R7)
GND: C159.2, C160.2, C161.2, D73.1 (K), D74.1 (K), D75.1 (K), D76.1 (K), D77.1 (K), D78.1 (K), D79.1 (K), D80.1 (K), EINGAENGE1.7, ICB5.10 (GND), ICB9.7 (VSS), ICB10.7 (VSS), ICC3.7 (GND), ICC4.7 (GND), ICC6.12 (GND), ICC10.7 (VSS), ICD3.8 (GND), ICD6.14 (GND), ICD10.7 (VSS), ICE6.14 (GND), ICE10.7 (VSS), ICF10.7 (VSS), ICG5.20 (Vss), ICG8-1.7 (GND), ICG8-2.8 (VSS), ICG9.1 (Vss), ICG10-1.14 (VDD), ICG10-2.7 (VSS), ICH1.8 (VSS), ICH8.12 (GND), ICH10.7 (VSS), ICK11.11 (V-), ICL8.7 (VSS), ICL9.5, ICL9.6, ICL9.7 (Vss), ICL10.7 (GND), LEUCHTZIFFERNANZEIGE1.1, R137.1, SERVICEANZEIGE+TASTATUR1.1, SIGNALNETZ1.1, SIGNALNETZ1.2, WALZENANSTEUERUNG1.1, ZUSATZTASTEN1.1
GNDPWR: LAUTSPRECHER1.4, LEISTUNGSAUSGAENGE1.2, LEISTUNGSNETZ1.1, LEISTUNGSNETZ1.2, LEISTUNGSNETZ1.3, MUENZANNAHME1.1, R41.2, R65.1, R66.1, R90.2, R100.1, SERIELLE_DATEN1.7, WALZENANSTEUERUNG1.13
unnamed: C76.2, R82.1, R83.1
unnamed: D1.2 (A), D2.2 (A), D10.2 (A), D11.2 (A), D12.2 (A), D13.2 (A), D25.2 (A), D26.2 (A)
unnamed: D1.1 (K), D2.1 (K), D10.1 (K), D11.1 (K), D12.1 (K), D13.1 (K), D25.1 (K), D26.1 (K), R40.1, RN1.1 (common), TR1.3 (E), TR2.3 (E), TR10.3 (E), TR11.3 (E), TR12.3 (E), TR13.3 (E), TR25.3 (E), TR26.3 (E)
unnamed: D4.2 (A), LAMPENZEILEN1.15, LAMPENZEILEN1.16, TY1.2 (A)
unnamed: D5.2 (A), LAMPENZEILEN1.13, LAMPENZEILEN1.14, TY2.2 (A)
unnamed: C4.2, C5.2, C6.2, C7.2, C8.2, C9.2, C10.2, C11.2, D6.2 (A)
unnamed: D6.1 (K), R4.2
unnamed: D7.2 (A), ICA2.3 (+), R148.1
unnamed: D8.2 (A), LED4.2 (A)
unnamed: D14.2 (A), LAMPENZEILEN1.11, LAMPENZEILEN1.12, TY5.2 (A)
unnamed: D4.1 (K), D5.1 (K), D14.1 (K), D15.1 (K), D16.1 (K), D17.1 (K), D28.1 (K), D29.1 (K), TR29.2 (C)
unnamed: D15.2 (A), LAMPENZEILEN1.9, LAMPENZEILEN1.10, TY6.2 (A)
unnamed: D16.2 (A), LAMPENZEILEN1.7, LAMPENZEILEN1.8, TY7.2 (A)
unnamed: D17.2 (A), LAMPENZEILEN1.5, LAMPENZEILEN1.6, TY8.2 (A)
unnamed: D18.2 (A), R16.2
unnamed: D3.1 (K), D27.1 (K), TR29.1 (E)
unnamed: D28.2 (A), LAMPENZEILEN1.3, LAMPENZEILEN1.4, TY15.2 (A)
unnamed: D29.2 (A), LAMPENZEILEN1.1, LAMPENZEILEN1.2, TY16.2 (A)
unnamed: D50.2 (A), R41.1, TR55.3 (E), TR56.3 (E)
unnamed: D51.2 (A), TR65.3 (B)
unnamed: D52.2 (A), TR66.3 (B)
unnamed: D85.1 (K), D86.1 (K), D87.1 (K), D88.1 (K)
unnamed: D89.1 (K), D90.1 (K), D91.1 (K), D92.1 (K), D93.1 (K), D94.1 (K), D95.1 (K), D96.1 (K)
unnamed: D97.1 (K), D98.1 (K), D99.1 (K), D100.1 (K), D102.1 (K), D103.1 (K), D104.1 (K)
unnamed: D105.1 (K), D106.1 (K), D107.1 (K), D108.1 (K), D110.1 (K), D111.1 (K)
unnamed: ICA2.5 (+), R148.2
unnamed: ICB2.1 (X1), R20.1
unnamed: ICC4.3, ICC4.4, ICC4.5
unnamed: ICE2.32 (P1.7), RM11.3 (R2)
unnamed: ICE2.31 (P2.0), RM11.4 (R3)
unnamed: ICE2.30 (P2.1), RM11.5 (R4)
unnamed: ICE2.29 (P2.2), RM21.2 (R1)
unnamed: ICE2.28 (P2.3), RM21.3 (R2)
unnamed: ICE2.27 (P2.4), RM21.4 (R3)
unnamed: ICE2.26 (P2.5), RM21.5 (R4)
unnamed: ICE2.25 (P2.6), RM21.6 (R5)
unnamed: ICE2.24 (P2.7), RM21.7 (R6)
unnamed: ICF2.14, R4.1
unnamed: ICF2.3 (+), RM11.6 (R5)
unnamed: ICF2.2 (-), ICF2.6 (-)
unnamed: ICF2.5 (+), RM11.7 (R6)
unnamed: ICG1.2 (-), ICG1.6 (-), ICG2.2 (-), ICG2.6 (-)
unnamed: ICG4.2 (-), ICG4.6 (-)
unnamed: ICG4.10 (+), ICG5.29 (OUT_B2)
unnamed: ICG9.15 (÷_239), ICH8.8 (I1)
unnamed: ICG9.14 (÷_253), ICH8.7 (I2)
unnamed: ICG9.13 (÷_268), ICH8.6 (I3)
unnamed: ICG9.12 (÷_284), ICH8.5 (I4)
unnamed: ICG9.11 (÷_301), ICH8.4 (I5)
unnamed: ICG9.10 (÷_319), ICH8.3 (I6)
unnamed: ICG9.9 (÷_338), ICH8.2 (I7)
unnamed: ICG9.8 (÷_358), ICH8.23 (I8)
unnamed: ICG9.7 (÷_379), ICH8.22 (I9)
unnamed: ICG9.6 (÷_402), ICH8.21 (I10)
unnamed: ICG9.5 (÷_426), ICH8.20 (I11)
unnamed: ICG9.4 (÷_451), ICH8.19 (I12)
unnamed: ICG9.16 (÷_478), ICH8.9 (I0)
unnamed: ICH4-1.16 (O1), R2.1
unnamed: ICH4-1.15 (O2), R10.1
unnamed: ICH4-1.14 (O3), R11.1
unnamed: ICH4-1.13 (O4), R12.1
unnamed: ICH4-1.12 (O5), R13.1
unnamed: ICH4-1.11 (O6), R27.1
unnamed: ICH4-1.10 (O7), R28.1
unnamed: ICH6.5 (Q1), RM56.4 (R3)
unnamed: ICH6.6 (Q2), RM56.3 (R2)
unnamed: ICH6.9 (Q3), RM56.2 (R1)
unnamed: ICL9.8, ICL9.9
unnamed: ICL10.2 (THR), ICL10.6 (TR)
unnamed: ICL11.10 (+), ICL11.12 (+)
unnamed: LAMPENSPALTEN1.1, LAMPENSPALTEN1.2, TR26.2 (C)
unnamed: LAMPENSPALTEN1.3, LAMPENSPALTEN1.4, TR25.2 (C)
unnamed: LAMPENSPALTEN1.5, LAMPENSPALTEN1.6, TR13.2 (C)
unnamed: LAMPENSPALTEN1.7, LAMPENSPALTEN1.8, TR12.2 (C)
unnamed: LAMPENSPALTEN1.9, LAMPENSPALTEN1.10, TR11.2 (C)
unnamed: LAMPENSPALTEN1.11, LAMPENSPALTEN1.12, TR10.2 (C)
unnamed: LAMPENSPALTEN1.13, LAMPENSPALTEN1.14, TR2.2 (C)
unnamed: LAMPENSPALTEN1.15, LAMPENSPALTEN1.16, TR1.2 (C)
unnamed: LED4.1 (K), R82.2
unnamed: LED5.1 (K), R140.2
unnamed: MUENZANNAHME1.6, RM83.8 (R8.1)
unnamed: MUENZANNAHME1.7, RM83.7 (R7.1)
unnamed: MUENZANNAHME1.8, RM83.6 (R6.1)
unnamed: MUENZANNAHME1.9, RM83.5 (R5.1)
unnamed: MUENZANNAHME1.10, RM83.4 (R4.1)
unnamed: MUENZANNAHME1.11, RM83.3 (R3.1)
unnamed: MUENZANNAHME1.12, RM83.2 (R2.1)
unnamed: MUENZANNAHME1.13, RM83.1 (R1.1)
unnamed: MUENZANNAHME1.14, RM85.4 (R4.1)
unnamed: MUENZANNAHME1.15, RM85.5 (R5.1)
unnamed: MUENZANNAHME1.16, RM85.6 (R6.1)
unnamed: MUENZANNAHME1.17, RM85.7 (R7.1)
unnamed: MUENZANNAHME1.18, RM85.8 (R8.1)
unnamed: R22.2, R23.2
unnamed: R84.1, R85.1
unnamed: R135.1, R136.1
unnamed: R136.2, R137.2
unnamed: C5.1, RM3.2 (R1), RM4.15 (R2.2)
unnamed: C6.1, RM3.3 (R2)
unnamed: C7.1, RM3.4 (R3)
unnamed: C8.1, RM3.5 (R4)
unnamed: C11.1, RM3.8 (R7)
unnamed: RM4.14 (R3.2), WALZENANSTEUERUNG1.2
unnamed: RM4.13 (R4.2), WALZENANSTEUERUNG1.3
unnamed: RM4.12 (R5.2), WALZENANSTEUERUNG1.4
unnamed: RM6.2 (R2.1), TASTEN1.1
unnamed: RM6.3 (R3.1), TASTEN1.2
unnamed: RM6.4 (R4.1), TASTEN1.3
unnamed: RM6.5 (R5.1), TASTEN1.4
unnamed: RM8.14 (R3.2), ZUSATZTASTEN1.6
unnamed: RM8.10 (R7.2), ZUSATZTASTEN1.5
unnamed: RM11.9 (R8), RM21.1 (common)
unnamed: DM2.5, R20.2, R21.2, RM13.1 (common)
unnamed: RM81.1 (R1.1), SERVICEANZEIGE+TASTATUR1.10
unnamed: RM81.2 (R2.1), SERVICEANZEIGE+TASTATUR1.9
unnamed: RM81.3 (R3.1), SERVICEANZEIGE+TASTATUR1.8
unnamed: RM81.4 (R4.1), SERVICEANZEIGE+TASTATUR1.7
unnamed: RM81.5 (R5.1), SERVICEANZEIGE+TASTATUR1.11
unnamed: RM81.6 (R6.1), SERVICEANZEIGE+TASTATUR1.12
unnamed: ICG10-1.5, RM81.11 (R6.2)
unnamed: RM81.7 (R7.1), SERVICEANZEIGE+TASTATUR1.13
unnamed: ICG10-1.12, RM81.10 (R7.2)
unnamed: RM81.8 (R8.1), SERVICEANZEIGE+TASTATUR1.14
unnamed: ICG10-1.6, RM81.9 (R8.2)
unnamed: C143.1, RM82.2 (R1)
unnamed: C144.1, RM82.3 (R2)
unnamed: C145.1, RM82.4 (R3)
unnamed: C146.1, RM82.5 (R4)
unnamed: C147.1, RM82.6 (R5)
unnamed: C148.1, RM82.7 (R6)
unnamed: C149.1, RM82.8 (R7)
unnamed: C150.1, RM82.9 (R8)
unnamed: C151.1, RM84.2 (R1)
unnamed: C152.1, RM84.3 (R2)
unnamed: C153.1, RM84.4 (R3)
unnamed: C154.1, RM84.5 (R4)
unnamed: C155.1, RM84.6 (R5)
unnamed: C156.1, RM84.7 (R6)
unnamed: C157.1, RM84.8 (R7)
unnamed: C158.1, RM84.9 (R8)
unnamed: ICK11.1, SERVICEANZEIGE+TASTATUR1.3
unnamed: ICK11.7, SERVICEANZEIGE+TASTATUR1.4
unnamed: R1.2, TR1.1 (B)
unnamed: R2.2, TR2.1 (B)
unnamed: R10.2, TR10.1 (B)
unnamed: R11.2, TR11.1 (B)
unnamed: R12.2, TR12.1 (B)
unnamed: R13.2, TR13.1 (B)
unnamed: R27.2, TR25.1 (B)
unnamed: R28.2, TR26.1 (B)
unnamed: R29.1, TR27.3 (B)
unnamed: R1.1, TR32.2 (C)
unnamed: TR70.3 (E), TR71.3 (E), TR72.3 (E), TR73.3 (E), TR80.3 (E), TR81.3 (E)
unnamed: TR82.3 (E), TR83.3 (E), TR95.3 (E), TR96.3 (E)
unnamed: R123.1, TR84.1 (D)
unnamed: R124.1, TR84.2 (G)
unnamed: R124.2, TR84.3 (S), TR87.3 (S)
unnamed: TY1.1 (K), TY2.1 (K), TY5.1 (K), TY6.1 (K)
unnamed: TY7.1 (K), TY8.1 (K), TY15.1 (K), TY16.1 (K)
unnamed: ICG1.14, WALZENANSTEUERUNG1.15

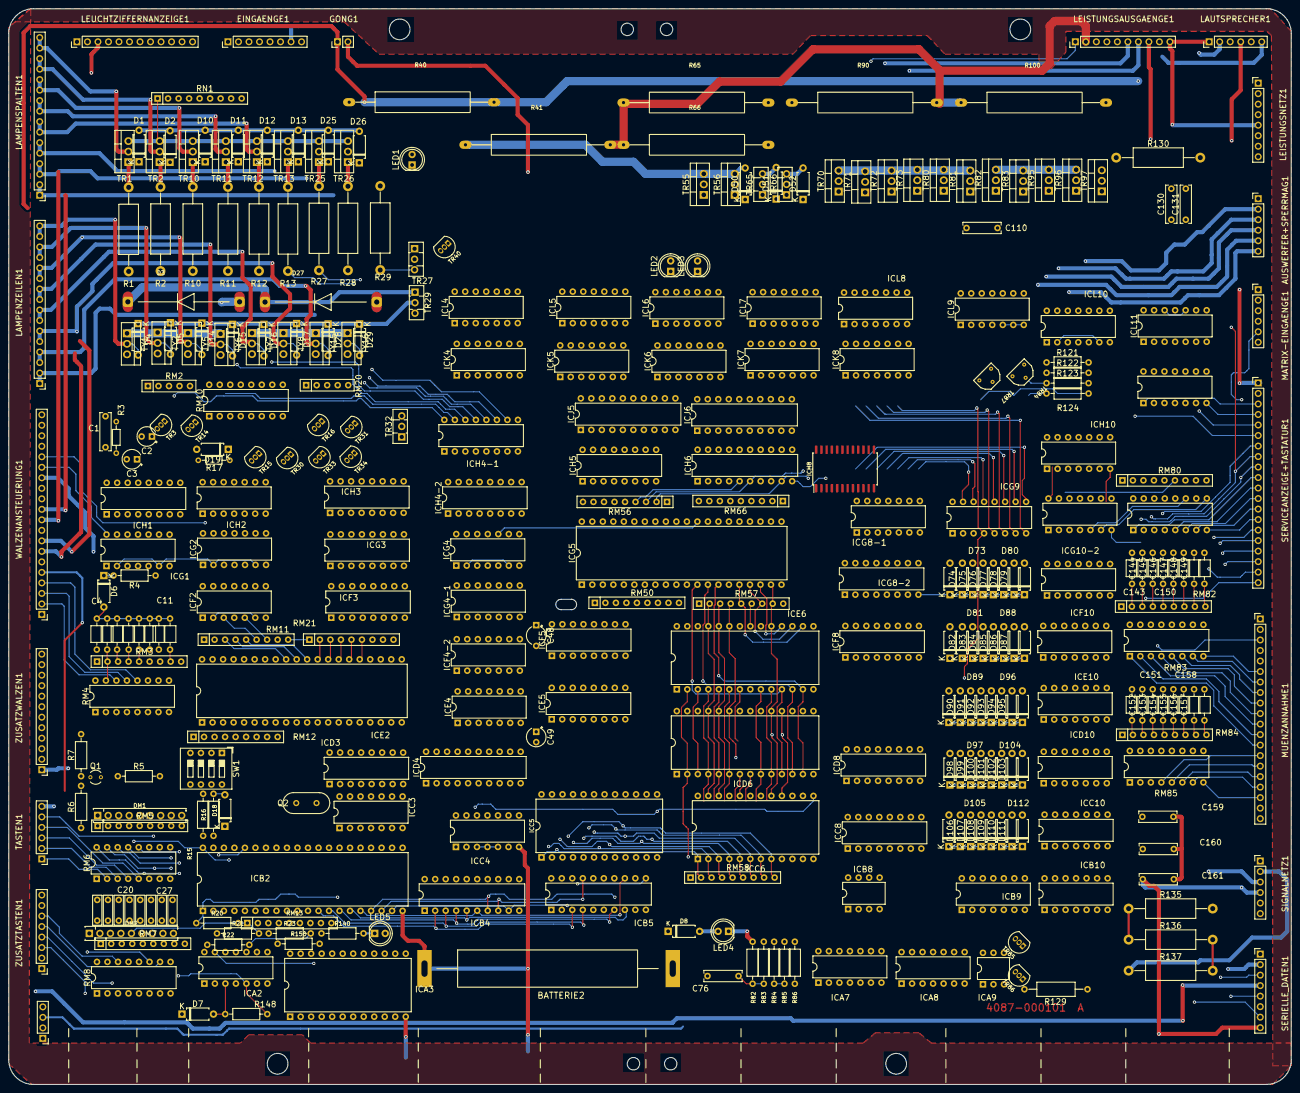
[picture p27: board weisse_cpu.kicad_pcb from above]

Board: 2 copper layers, 310.0 x 260.0 mm, 325 parts (0 on the bottom side), 196 nets.

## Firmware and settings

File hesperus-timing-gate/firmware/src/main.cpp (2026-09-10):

// #include "esp_wifi.h"
#include <Adafruit_NeoPixel.h>
#include <ArduinoJson.h>
#include <ESPmDNS.h>
#include <WebSocketsClient.h>
#include <WiFi.h>

#include "esp_wifi.h"

#include "beam-sensor.h" // dual-EMA reflective/occlusion beam-break detector
#include "board-role.h" // BoardRole, role -> event-name mapping
#include "boards.h" // contains the board MAC addresses to look up the identifiers
#include "cli.h"    // serial command line interface
#include "debug-log.h"            // TSF-timestamped debug_println/debug_printf
#include "network-health-stats.h" // NVS-persisted stall/drop/disconnect counters
#include "provisioning-commands.h" // `wifi`/`role` serial commands
#include "secrets.h" // these are the network credentials neede to connect to the AP
#include "wifi-credentials.h" // NVS-persisted wifi creds from the `wifi` command

#if HAS_HTTP
#include "net/debug-http-server.h" // on-demand /logs, /status diagnostics endpoint
#endif

// --- Hardware Pin Configuration ---
// STATUS_LED and NEOPIXEL_COLOR_ORDER come from the per-board build_flags in
// platformio.ini/boards.ini - do not hardcode a pin/order here, it varies
// per target (e.g. GPIO21/NEO_RGB on ESP32-S3-Zero, GPIO48/NEO_GRB on the
// S3 Super Mini).
Adafruit_NeoPixel led(1, STATUS_LED, NEOPIXEL_COLOR_ORDER + NEO_KHZ800);

char gate_id[16];

// Power/link status indicator LEDs, active-low. RED on at power-up, GREEN on
// once Wi-Fi is connected (RED off); reverts to RED on disconnect. Sole
// owner of these two pins is statusLedTask, below (see led_set()/
// led_flash()) -- do not digitalWrite() them from anywhere else, or the two
// writers will race on the same GPIOs.
const int LED_RED_PIN = 10;
const int LED_GREEN_PIN = 11;

// --- RED/GREEN indicator LED control queue ---
// LedTarget/LedCommand/LedControlMsg, statusLedQueue and statusLedTask
// (defined further down, near ledDiagnosticTask) let any code turn either
// LED on/off "at will" (led_set()) or force one on for a bounded number of
// 100ms ticks then revert to its steady state (led_flash()) -- e.g. to
// signal a one-off event without disturbing the ongoing connection-status
// indication. Named distinctly from the unrelated NeoPixel
// ledQueue/ledDiagnosticTask/ledTaskHandle below (different LEDs, different
// subsystem).
enum class LedTarget { RED, GREEN };
enum class LedCommand { SET_ON, SET_OFF, FLASH };

struct LedControlMsg {
  LedTarget target;
  LedCommand command;
  uint8_t flash_ticks; // only used when command == FLASH; ticks of 100ms each
};

QueueHandle_t statusLedQueue;
TaskHandle_t statusLedTaskHandle = NULL;

// Non-blocking; mirrors ledQueue's xQueueSend(...,0) + logged-overflow
// convention used elsewhere in this file.
bool led_set(LedTarget target, bool on) {
  LedControlMsg msg{target, on ? LedCommand::SET_ON : LedCommand::SET_OFF, 0};
  if (xQueueSend(statusLedQueue, &msg, 0) != pdTRUE) {
    debug_println("[QUEUE OVERFLOW] statusLedQueue full; LED set dropped.");
    return false;
  }
  return true;
}

// Forces `target` to the OPPOSITE of its current steady state for `ticks` *
// 100ms, then reverts to its steady state (whatever led_set() last set it to
// -- may change during the flash, which is picked up correctly since steady
// state and the flash countdown/value are tracked independently per LED in
// statusLedTask). E.g. calling this on RED (currently off) and GREEN
// (currently on) back-to-back swaps them for the flash's duration.
bool led_flash(LedTarget target, uint8_t ticks) {
  LedControlMsg msg{target, LedCommand::FLASH, ticks};
  if (xQueueSend(statusLedQueue, &msg, 0) != pdTRUE) {
    debug_println("[QUEUE OVERFLOW] statusLedQueue full; LED flash dropped.");
    return false;
  }
  return true;
}

// Channel A / channel B -- see board-role.h for how these map to ARM/START/
// GOAL depending on the board's provisioned role. Sourced from the
// analogue dual-EMA detector (see beam-sensor.h and
// ARM_SENSOR_PIN/START_SENSOR_PIN below) rather than a digital edge.
// ARM_SENSOR_PIN/START_SENSOR_PIN themselves come from the per-board
// build_flags in platformio.ini/boards.ini (same convention as STATUS_LED
// above) -- they vary per target.

BoardRole board_role = BoardRole::UNSET;
Cli cli;

int state = 1;

enum EventType { TRIGGER_A, TRIGGER_B, HEARTBEAT };

struct GateEvent {
  EventType type;
  uint64_t tsf_observed;    // Volatile native Wi-Fi TSF timeline
  uint64_t processor_clock; // Monotonic internal 64-bit microsecond uptime
};

/// ISR-to-task handoff for a trigger edge (NETWORK-TIMING-LOG.md "ISR
/// calling esp_wifi_get_tsf_time()" issue) -- carries only what's safe to
/// capture directly in an ISR (the event type and the ISR-safe
/// esp_timer_get_time() processor clock). The real TSF read happens in
/// tsfCaptureTask(), in task context, where blocking briefly on the WiFi
/// driver's internal lock is legal instead of fatal.
struct PendingCapture {
  EventType type;
  uint64_t processor_clock;
};

// Tracking Memory Management
GateEvent last_good_state = {HEARTBEAT, 0, 0};
bool has_initial_baseline = false;

/** --- Dynamic Clock Disciplining Parameters --- */
double clock_alpha = 1.00000000; // Dynamic drift scaling factor
bool alpha_calibrated = false;   // Explicit state flag
const double EMA_ALPHA = 0.10;   // Weights 10% new sample, 90% history
uint64_t cal_prev_tsf = 0;
uint64_t cal_prev_proc = 0;

const uint64_t DRIFT_MARGIN_US = 500;
const uint64_t MIN_PLAUSIBLE_TSF = 300000000;

// --- WS ACK/RETRY (NETWORK-TIMING-LOG.md status section item 1) ---
// Blocking, single-in-flight retry: uploadWorkerTask waits for cerberus's
// ack before dequeuing the next networkQueue event, matching the existing
// one-worker/one-event-at-a-time architecture exactly (no pending-events
// table needed). WS_ACK_TIMEOUT_MS is comfortably above the ~5-15ms typical
// WS round trip measured during rec. 1's bring-up, generous against the
// occasional ~40ms single-event jitter spike also seen there.
const uint32_t WS_ACK_TIMEOUT_MS =
    500; // per-attempt base: resend if no ack within this --
         // raised from 300, 2026-08-04 session 10: end-to-end
         // instrumentation on both boards (cerberus's
         // pending/space, hesperus's [WS-ACK-RECV]) traced every
         // retry in a two-spammer+BT trial and found none were
         // lost -- each was the original ack arriving fine on a
         // round trip (258-458ms) that simply outran the old
         // 240-360ms window under heavy channel congestion
         // (neither board's own processing was slow -- cerberus's
         // dispatch stayed <15ms and wsPumpTask's own
         // wsClient.loop() canary logged only one >50ms stall in
         // the whole trial, uncorrelated with these events -- so
         // the time is most likely spent on-air/at the WiFi MAC
         // layer itself, not in either board's software). 500ms
         // clears the observed 458ms worst case with margin.
const uint32_t WS_ACK_TIMEOUT_JITTER_MS =
    100; // +/- randomised against the base above (see below) --
         // kept at the same ~20% of base as before (was 60/300)
         // -- 2026-08-03 beacon-spam stress testing (session 3)
         // found cerberus's own ack dispatch reliably fast
         // (<15ms) even under heavy congestion, yet acks still
         // failed to arrive back in time; a fixed retry schedule
         // means both gate boards' retries (or retries vs. ARES's
         // own periodic traffic) can lock-step and collide
         // repeatedly on an already-congested channel -- jitter
         // breaks that synchronisation. Deliberately widening the
         // interval under congestion (not shortening it) rather
         // than retrying faster into contention.
const uint8_t WS_MAX_SEND_ATTEMPTS =
    10; // raised from 5, 2026-08-03 session 3 -- extra attempts
        // only ever fire on a timeout, so a healthy send (the
        // normal case) pays none of this cost; only the tail
        // under congestion gets more chances
const uint32_t WS_ACK_WAIT_TICK_MS =
    5; // real vTaskDelay between poll iterations -- see below
const uint32_t WS_ACK_OVERALL_DEADLINE_MS =
    5200; // hard wall-clock cap, applies even while disconnected
          // -- without this a real Wi-Fi outage would park
          // uploadWorkerTask on one stale event for the whole
          // outage while fresh events overflow-drop from
          // networkQueue behind it. Raised from 3200 to 5200,
          // 2026-08-04, alongside WS_ACK_TIMEOUT_MS's 300->500 --
          // scaled proportionally so WS_MAX_SEND_ATTEMPTS's 10
          // attempts still fit inside the deadline (10x500=5000,
          // +200ms margin, same margin the original 3200 left
          // over 10x300=3000) rather than quietly shrinking to
          // ~7 attempts' worth of real-loss recovery depth as a
          // side effect of the per-attempt timeout increase.
          // Real-race events are sparse (one every 20+ seconds)
          // and networkQueue is depth 10, so this remains
          // comfortably inside that budget.

// --- CERBERUS DISCOVERY (mDNS) ---
// Resolved once after Wi-Fi connects and cached for the rest of this boot --
// the venue IP won't change mid-contest, so there's no need to re-query
// mDNS for every event.
IPAddress cerberus_ip;
bool cerberus_ip_valid = false;

// --- PERSISTENT CONNECTION TO CERBERUS (NETWORK-TIMING-LOG.md rec. 1) ---
// One connection opened per boot (see loop()'s g_ready edge-detection) and
// held open across every subsequent event, replacing the old per-event
// HTTPClient connect+POST+close cycle.
//
// .loop() is pumped exclusively by wsPumpTask (below) -- confirmed via
// NETWORK-TIMING-LOG.md's "wsClient.loop() blocking under congestion"
// investigation that a single .loop() call can itself block for several
// seconds (internal TCP reconnect under RF interference), which used to
// silently blow past uploadWorkerTask's own 300ms/2000ms ack/retry bounds
// since those were only checked *between* .loop() calls on the same task.
// wsClient itself isn't safe to call from two tasks without a mutex, so
// every call site (this task's .loop(), and uploadWorkerTask's/loop()'s
// .sendTXT()/.isConnected()/.begin()/.enableHeartbeat()/.onEvent()) goes
// through ws_client_mutex -- see the wsXxxBounded() helpers below.
WebSocketsClient wsClient;

// ws_client_mutex: guards every call into wsClient. wsPumpTask holds it for
// the full duration of each .loop() call (the one place allowed to block for
// however long a stall runs); every other caller takes it with a short
// bounded timeout via the wsXxxBounded() helpers below and treats a failed
// acquisition as "skip this attempt / not connected" rather than blocking --
// the only way that timeout fires is wsPumpTask being mid-stall, which the
// 2026-08-02 stress test showed coincides with a genuine outage anyway, so
// "not connected" is the right conclusion, reached without blocking.
SemaphoreHandle_t ws_client_mutex = xSemaphoreCreateMutex();
const uint32_t WS_MUTEX_SEND_TIMEOUT_MS = 20;
const uint32_t WS_MUTEX_SETUP_TIMEOUT_MS = 50;

/// @brief Resolves cerberus.local via mDNS and caches the result. Safe to
/// call repeatedly (e.g. retried from uploadWorkerTask) until it succeeds --
/// each call is a fresh query, not a re-use of a stale failure.
void resolveCerberus() {
  IPAddress ip = MDNS.queryHost("cerberus");
  if (ip != IPAddress(0, 0, 0, 0)) {
    cerberus_ip = ip;
    cerberus_ip_valid = true;
    debug_printf("[MDNS] cerberus.local -> %s\n", ip.toString().c_str());
  } else {
    debug_println("[MDNS] cerberus.local not found");
  }
}

static int consecutive_audit_failures = 0;

// Ack-tracking state for the WS retry mechanism, guarded by ws_ack_state_mutex
// as one atomic (received flag, tsf) unit. Used to run on the assumption that
// wsClient.onEvent()'s callback and uploadWorkerTask's wait loop shared a
// task; now that .loop() (and so this callback) runs exclusively on
// wsPumpTask while uploadWorkerTask reads it from a different task, that
// assumption no longer holds -- g_ws_ack_tsf_us in particular is a uint64_t,
// a non-atomic two-word read/write on this 32-bit hardware, so a torn read
// is a real (if narrow-consequence) possibility without the mutex. Use
// wsTakeAckIfReceived()/wsClearAck() (below) rather than touching these
// directly.
bool g_ws_ack_received = false;
uint64_t g_ws_ack_tsf_us =
    0; // last acked tsf_us, compared by value against the pending send
// TSF-timeline (debug_timestamp_ms(), same clock cerberus's own [WS-ACK]
// recv/dispatch/sent timestamps use) capture time of the ack above --
// NETWORK-TIMING-LOG.md "acks not arriving back at hesperus in time"
// issue, added 2026-08-04 once cerberus-side instrumentation ruled out
// AsyncTCP write-completion lag on cerberus's own end: this is the
// matching receive-side timestamp needed to see where the remaining time
// actually goes, directly comparable to cerberus's sent= with no NTP/offset
// needed. debug_timestamp_ms() itself is a cheap esp_wifi_get_tsf_time()
// read, not I/O, so it's safe to call here despite the latency-sensitive
// context below -- unlike a debug_printf/Serial write, which is
// deliberately NOT done in this handler (see its own comment).
uint64_t g_ws_ack_recv_t_ms = 0;
SemaphoreHandle_t ws_ack_state_mutex = xSemaphoreCreateMutex();

/// @brief wsClient.onEvent() handler -- receives cerberus's per-event ack
/// ({"ack_tsf_us": ...}, see net/http-server.h's ws_event_handler() on that
/// repo) so uploadWorkerTask's send-and-wait loop knows an event landed.
/// Also clears a stale ack flag on disconnect so a reconnect mid-wait can't
/// leave old bookkeeping lying around into the next connection.
///
/// Fires synchronously nested inside wsPumpTask's wsClient.loop() call, which
/// holds ws_client_mutex for the duration -- this handler must only ever take
/// ws_ack_state_mutex, never ws_client_mutex (a non-recursive FreeRTOS mutex
/// already held by the same task would deadlock). It has no reason to call
/// back into wsClient, so keep it that way. Deliberately does no logging of
/// its own for the same reason: a debug_printf() here would add a
/// serial_write_mutex take + blocking Serial write directly into
/// wsPumpTask's call stack, the exact latency-critical path the
/// wsClient.loop()-blocking fix exists to protect -- the receive timestamp
/// captured below is cheap to take here, but its logging is deferred to
/// uploadWorkerTask (see wsTakeAckIfReceived()'s call site), which already
/// does its own unhurried Serial I/O for "[WS Worker] Sent/Resent" today.
void wsClientEventHandler(WStype_t type, uint8_t *payload, size_t length) {
  if (type == WStype_TEXT) {
    JsonDocument doc;
    if (deserializeJson(doc, payload, length) == DeserializationError::Ok) {
      uint64_t recv_t_ms = debug_timestamp_ms();
      xSemaphoreTake(ws_ack_state_mutex, portMAX_DELAY);
      g_ws_ack_tsf_us = doc["ack_tsf_us"] | 0ULL;
      g_ws_ack_recv_t_ms = recv_t_ms;
      g_ws_ack_received = true;
      xSemaphoreGive(ws_ack_state_mutex);
    }
  } else if (type == WStype_DISCONNECTED) {
    xSemaphoreTake(ws_ack_state_mutex, portMAX_DELAY);
    g_ws_ack_received = false;
    xSemaphoreGive(ws_ack_state_mutex);
    // Plain RAM increment only, no I/O -- see network-health-stats.h's
    // header comment for why NVS writes never happen at an increment site.
    g_network_health.disconnect_count++;
    g_network_health_dirty = true;
  }
}

/// @brief Bounded-timeout wrapper around wsClient.isConnected(). Returns
/// false (treated as "not connected") if ws_client_mutex can't be acquired
/// within timeout_ms -- the only way that happens is wsPumpTask being
/// mid-stall in .loop(), which the 2026-08-02 stress test showed coincides
/// with a genuine outage, so this isn't a false negative, just an early one.
bool wsIsConnectedBounded(uint32_t timeout_ms) {
  if (xSemaphoreTake(ws_client_mutex, pdMS_TO_TICKS(timeout_ms)) != pdTRUE) {
    return false;
  }
  bool connected = wsClient.isConnected();
  xSemaphoreGive(ws_client_mutex);
  return connected;
}
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
void loop() {
  static uint32_t last_connected_time = millis();
  static uint32_t last_reconnect_attempt = millis();
  static uint32_t last_cerberus_attempt = 0;
  static uint32_t syn_mode_start_time = 0; // Tracks duration of fallback timing
  static bool was_connected = false;
  static bool ws_was_ready =
      false; // g_ready edge-detection, opens wsClient once per readiness

  uint32_t current_time = millis();

  // Ahead of the reboot-capable watchdog below, so a dirty counter from a
  // stall/drop this same iteration is persisted before any possible restart.
  network_health_flush_if_dirty();

  // --- PATCH 2: EXTENDED SYN-MODE WATCHDOG ---
  // If the gate is trapped in synthetic time for >10 s, the Wi-Fi
  // recovery mechanism has stalled. Reboot to force a clean restart.
  if (global_is_stuck_in_syn) {
    if (syn_mode_start_time == 0) {
      syn_mode_start_time = current_time; // Start the clock on the breakdown
    } else if (current_time - syn_mode_start_time > 10000) {
      // If the gate is stuck calculating synthetic time for more than 10
      // seconds, the hardware clock register has hit an overflow boundary.
      // Clear stacks and reboot.
      debug_println("[ROLLOVER FAULT] Trapped in synthetic time loop for 10s. "
                    "Forcing hardware reboot...");
      delay(500);
      ESP.restart();
    }
  } else {
    syn_mode_start_time = 0; // Reset watchdog when operations are normal
  }

  if (WiFi.status() == WL_CONNECTED) {
    if (!was_connected) {
      debug_println("[NETWORK] Link Active! IP: " + WiFi.localIP().toString());
      if (!MDNS.begin(gate_id)) {
        debug_println("[MDNS] failed to start");
      }
#if HAS_HTTP
      MDNS.addService("http", "tcp", 80);
      debug_http_server_init(); // idempotent route registration; .begin()
                                // re-issued every edge -- see
                                // debug-http-server.h's AsyncServer::begin()
                                // note
#endif
      cerberus_ip_valid = false; // re-resolve on this connection
      last_cerberus_attempt = 0; // force an immediate resolve attempt below
      was_connected = true;
      led_set(LedTarget::RED, false); // link up: RED off, GREEN on
      led_set(LedTarget::GREEN, true);
    }
    last_connected_time = current_time;

    // Gates readiness (LED + actual event sending in uploadWorkerTask) on
    // cerberus's IP being resolved -- retried here on a throttled timer
    // rather than every loop() tick, but deliberately doesn't block
    // cli.poll()/the reconnect-watchdog below, so `wifi`/`role` serial
    // reprovisioning and Wi-Fi recovery still work even if cerberus is
    // genuinely unreachable.
    if (!cerberus_ip_valid) {
      led_base = LedBase::SEARCHING;
      g_ready = false;
      if (current_time - last_cerberus_attempt > 1000) {
        resolveCerberus();
        last_cerberus_attempt = current_time;
      }
    } else {
      led_base = LedBase::READY;
      g_ready = true;
      // Edge-triggered: open the persistent connection once per readiness
      // transition, not every loop() tick. wsClient handles its own
      // reconnect loop internally once begun, so this doesn't need to be
      // re-called on every tick while already ready.
      if (!ws_was_ready) {
        // Bounded acquisition -- if wsPumpTask is mid-stall holding
        // ws_client_mutex, ws_was_ready stays false and this is retried on
        // the next loop() tick (10ms later, below) rather than blocking
        // loop() itself for the stall's duration.
        if (xSemaphoreTake(ws_client_mutex,
                           pdMS_TO_TICKS(WS_MUTEX_SETUP_TIMEOUT_MS)) ==
            pdTRUE) {
          wsClient.begin(cerberus_ip.toString(), 80, "/ws");
          wsClient.enableHeartbeat(
              5000, 3000, 2); // 5s ping, 3s pong timeout, disconnect after 2
                              // misses (widened to 5000,3 2026-08-05, reverted
                              // same day -- session 14 showed it makes the
                              // MIN_MODEM stall/disconnect cascade dramatically
                              // worse, not better. NETWORK-TIMING-LOG.md)
          wsClient.onEvent(
              wsClientEventHandler); // receives cerberus's per-event ack
          xSemaphoreGive(ws_client_mutex);
          ws_was_ready = true;
        }
      }
    }
  } else {
    if (was_connected) {
      led_set(LedTarget::RED, true); // link down: RED on, GREEN off
      led_set(LedTarget::GREEN, false);
    }
    was_connected = false;
    cerberus_ip_valid = false;
    led_base = LedBase::OFF;
    g_ready = false;
    // Force a fresh begin() next time readiness is reached -- cerberus may
    // resolve to a different IP after this WiFi drop/rejoin.
    ws_was_ready = false;

    if (current_time - last_connected_time > 15000) {
      debug_println("[WATCHDOG FAULT] Wi-Fi link dead for 15s. Smashing "
                    "network stack...");
      WiFi.disconnect(true, true);
      delay(500);
      debug_println(
          "[WATCHDOG RECOVERY] Re-initializing hardware radio interface...");
      WiFi.begin(connect_ssid, connect_pass);
      last_connected_time = current_time;
      last_reconnect_attempt = current_time;
    } else if (current_time - last_reconnect_attempt > 3000) {
      Serial.print(".");
      last_reconnect_attempt = current_time;
    }
  }

  cli.poll();

  delay(10);
}

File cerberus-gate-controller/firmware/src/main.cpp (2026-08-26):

#include <Arduino.h>
#include <Preferences.h>
#include <WiFi.h>
#include <freertos/task.h>

#include "status-led/status-led.h"

#include "debug-log.h"

#include "display/display.h"
#include "display/lvgl-bridge.h"
#include "display/touch-calibration.h"

#include "gpio-buttons.h"
#include "input-events.h"
#include "neokey-buttons.h"
#include "neokey/neokey-pixels.h"
#include "settings-store.h"

#include "race/race-command-source.h"
#include "race/race-serial-telemetry.h"
#include "race/race-timer-display.h"
#include "race/race-timer.h"
#include "race/system-event-queue.h"

#include "net/http-server.h"
#include "net/mdns.h"
#include "net/messages.h"
#include "net/serial-protocol.h"
#include "net/wifi-credentials.h"
#include "net/wifi-manager.h"
#include "net/wifi-provisioning.h"
#include "version-generated.h"
#include "wifi-scan.h"

// lib/ui/ -- EEZ Studio generated.
#include "ui/screens.h"
#include "ui/ui.h"

StatusLED statusIndicator;
// Non-static: display/display.h declares it extern so
// net/wifi-provisioning.h (and action_on_menu_setup in eez-actions.cpp) can
// draw setup instructions directly to the panel without owning the instance.
LGFX lcd;

// Local Input Polling Task (Core 1). Owns all
// input-device reads (GPIO + NeoKey; touch is polled internally by LVGL's
// own indev, see lvgl_touch_init()); the main task owns the display and
// must never poll a device from here to avoid double-reads.
static void input_poll_task(void *) {
  const TickType_t period = pdMS_TO_TICKS(INPUT_POLL_PERIOD_MS);
  for (;;) {
    poll_gpio_buttons();
    poll_neokey_buttons();
    vTaskDelay(period);
  }
}

// Reflects race_state onto the NeoKey LEDs. Called after every
// race_timer_handle_command() dispatch, regardless of source, so
// Serial/HTTP-driven transitions stay visible on the physical LEDs exactly
// like local button transitions do -- previously this only ran from
// input_event_handler, so a remote command left the LEDs showing whatever
// state a button had last set, even though race_state itself had moved on.
//
// Key 3 (BTN_TOUCH) shows whether the current mouse has been touched
// (mouse_touched, race/race-timer.h -- set by input_event_handler's TOUCH
// short-press block below, cleared by race_timer_enter_new_mouse()), except
// during CALIBRATE, where the gate test (input_event_handler's CALIBRATE
// block) owns it instead as a 4th gate indicator; that's why the switch
// below leaves key 3 alone in the CALIBRATE case and it's set separately
// afterwards, only when not in CALIBRATE. Since that write happens
// unconditionally on every non-CALIBRATE call, it also naturally clears
// whatever gate-test colour CALIBRATE last left there, with no extra
// state/edge-tracking needed.
void neokey_reflect_race_state() {
  switch (race_state) {
    case RaceState::CALIBRATE:
      neokey_set_colour(0, NP_OFF);
      neokey_set_colour(1, NP_OFF);
      neokey_set_colour(2, NP_OFF);
      break;

    case RaceState::NEW_MOUSE:
      neokey_set_colour(0, NP_MAGENTA);
      neokey_set_colour(1, NP_MAGENTA);
      neokey_set_colour(2, NP_MAGENTA);
      break;

    case RaceState::WAITING:
      neokey_set_colour(0, NP_GREEN);
      neokey_set_colour(1, NP_GREEN);
      neokey_set_colour(2, NP_GREEN);
      break;

    case RaceState::ARMED:
      neokey_set_colour(0, NP_GREEN);
      neokey_set_colour(1, NP_OFF);
      neokey_set_colour(2, NP_OFF);
      break;

    case RaceState::RUNNING:
      neokey_set_colour(0, NP_OFF);
      neokey_set_colour(1, NP_GREEN);
      neokey_set_colour(2, NP_OFF);
      break;

    case RaceState::GOAL:
      neokey_set_colour(0, NP_OFF);
      neokey_set_colour(1, NP_OFF);
      neokey_set_colour(2, NP_GREEN);
      break;

    default:
      neokey_set_colour(0, NP_BLUE);
      neokey_set_colour(1, NP_BLUE);
      neokey_set_colour(2, NP_BLUE);
      break;
  }

  if (race_state != RaceState::CALIBRATE) {
    neokey_set_colour(BTN_TOUCH, mouse_touched ? NP_RED : NP_OFF);
  }
}

// As the input event queue is drained, all events pass through here
// for dispatch.
// The events have been copied from the queue so they are valid through
// the lifetime of this function
void input_event_handler(const InputEvent &evt) {
  // TOUCH held -- from NeoKey, or the touch panel's own LVGL long-press
  // (action_on_timer_touch_long posts here too, same as every other
  // producer): return to the main menu. UI navigation only, not a
  // RaceCommand, so it's handled here rather than through
  // BUTTON_COMMAND_MAP. trigger_touch_lockout() debounces the touch panel
  // for 250ms after the switch regardless of which producer triggered it.
  if (evt.id == BTN_TOUCH && evt.type == InputEventType::HELD) {
    trigger_touch_lockout();
    loadScreen(SCREEN_ID_MENU);
  }
  // TOUCH short press, main race screen and RUNNING only -- a host-facing
  // notification to RATS, not a RaceCommand (BUTTON_COMMAND_MAP maps this
  // press to NONE; see its comment in race-command-source.h for why).
  // Gated on the main screen the same way BTN_START's calibration-wizard
  // re-entry below is gated on the menu screen, so this can't fire from the
  // menu. Also gated on RUNNING -- "touched" only means something while the
  // mouse is actually in the maze between START and GOAL, not while idle
  // between runs. Triggered on RELEASED, not PRESSED -- PRESSED fires
  // immediately on press-down, before it's known whether the hold will
  // become a long press (-> main menu above), so acting on it would also
  // register a touch on every long-press-to-menu gesture. RELEASED (posted
  // by neokey-buttons.h) only fires when release happened before the long-
  // press threshold, i.e. it's mutually exclusive with the HELD case above.
  if (evt.id == BTN_TOUCH && evt.type == InputEventType::RELEASED && lv_scr_act() == objects.main &&
      race_state == RaceState::RUNNING) {
    mouse_touched = true;
    serial_send_message(MSG_TOUCH_SHORT_PRESS, 1);
  }
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

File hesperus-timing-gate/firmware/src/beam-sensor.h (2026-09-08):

// ----------------------------------------------------------------------------
//  beam-sensor.h — Dual-EMA beam-break detector.
//
//  Two EMAs of the same raw ADC signal: `fast` (tau ~2ms) tracks the
//  instantaneous reading, `slow` (tau ~1s) tracks the ambient+emitter
//  baseline. A beam-break/occlusion pulls `fast` down toward the ambient-
//  only level much faster than `slow` can follow, so `slow - fast` crossing
//  BEAM_TRIGGER_DROP_COUNTS (falling) / BEAM_REARM_DROP_COUNTS (rising)
//  gives a trigger/re-arm pair with built-in hysteresis. This is an
//  absolute count drop, not a ratio -- it specifically measures the
//  emitter's own contribution being lost, which stays meaningful regardless
//  of the ambient level (a fast/slow *ratio* doesn't: strong ambient can
//  both mask a real occlusion and make a depressed baseline easy to false-
//  trigger on). See detection-mechanism.md for the full writeup.
//
//  Both EMAs are seeded from a burst of real ADC samples at startup
//  (beam_sensor_seed_from_adc()) so readings are valid immediately rather
//  than ramping up from a zeroed start.
//
//  The recovery clamp (slow = max(slow, fast)) runs only while !armed --
//  i.e. only while genuinely recovering from a latched trigger/occlusion,
//  not during ordinary armed operation -- so it still lets `slow` snap back
//  up quickly once light returns after a long occlusion, without letting a
//  brief bright external light source (e.g. a passing robot's own
//  reflected-light sensor) drag `slow` up and cause a false trigger once
//  that source's own pulse ends. It's a no-op during a real occlusion
//  either way, since `fast` is low there and max(slow, fast) doesn't pull
//  slow down.
//
//  A confirm_count requires BEAM_CONFIRM_SAMPLES consecutive samples past
//  the trigger ratio before latching an interrupt, to reject single-sample
//  noise glitches.
//
//  alpha = 1/(F*tau) is derived from BEAM_SAMPLE_RATE_HZ rather than
//  hardcoded, so if the sample rate changes, alpha_fast/alpha_slow are
//  recalculated together automatically, preserving the same time constants.
// ----------------------------------------------------------------------------
#pragma once

#include <Arduino.h>

#include "debug-log.h" // debug_printf

constexpr uint32_t BEAM_SAMPLE_RATE_HZ = 1000; // see main.cpp's timer setup
constexpr float BEAM_TAU_FAST_S = 0.002f;      // ~2ms, tracks the raw signal
constexpr float BEAM_TAU_SLOW_S = 1.0f;        // ~1s, tracks the ambient baseline
constexpr float BEAM_ALPHA_FAST = 1.0f / (BEAM_SAMPLE_RATE_HZ * BEAM_TAU_FAST_S);
constexpr float BEAM_ALPHA_SLOW = 1.0f / (BEAM_SAMPLE_RATE_HZ * BEAM_TAU_SLOW_S);

// ~1% of 12-bit full scale (4095) -- below this the sensor isn't seeing
// usable light at all, so the trigger logic is skipped entirely.
constexpr float BEAM_DARK_FLOOR_COUNTS = 40.0f;

// Minimum drop of `fast` below `slow` (in raw ADC counts) required to latch
// a trigger -- an absolute measure of the emitter's own light being lost,
// not a fast/slow ratio. Bench data shows a properly aimed pair contributes
// at least ~400-500 counts to `slow` once both emitters are on (see
// test-data.md, case C); this sits with margin below that minimum, well
// above what ambient/external-illumination noise alone plausibly moves in
// ~2ms (BEAM_TAU_FAST_S). An absolute threshold also avoids a failure mode
// the old 0.25x ratio had: under strong ambient (test-data.md case D, where
// incandescent ambient reached ~69% of the START channel's own emitter
// contribution), the ratio could fail to cross 0.25 on a *real* occlusion
// at all -- a missed trigger, not just a false one.
constexpr float BEAM_TRIGGER_DROP_COUNTS = 300.0f;

// Re-arm once the drop has recovered back below this -- well under
// BEAM_TRIGGER_DROP_COUNTS so the gap gives the same kind of hysteresis the
// old 0.25/0.75 ratio band did, without which noise sitting right at the
// trigger threshold could chatter.
constexpr float BEAM_REARM_DROP_COUNTS = 100.0f;

// Consecutive samples past the trigger drop required before latching an
// interrupt (~3ms of added latency at BEAM_SAMPLE_RATE_HZ=1000) -- tune
// against real sensor noise on the bench.
constexpr uint8_t BEAM_CONFIRM_SAMPLES = 3;
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

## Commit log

2026-06-16 make sure the input pin is pulled up, not floating
2026-06-16 reset prefious tsf properly when resetting baseline
    [main.cpp]
2026-06-16 correctly reset the audit failure count
    [main.cpp]
2026-06-16 correct erroneous comment about getting stuck in SYN mode
    [main.cpp]
2026-06-16 ensure the anti-drift instant_alpha is constrained when we start to use it
    [main.cpp]
2026-06-16 wire in the code for the second trigger
2026-07-16 add a board inventory
    [esp32_inventory.csv]
2026-07-17 remove arduino support
2026-07-17 button names moved to input-events.h
2026-07-17 add a note about missing gpio buttons
2026-07-17 add a debug print for the input events
2026-07-18 update main menu button colours
2026-07-18 separate the race-timer from the display
2026-07-19 add unit tests for race-timer
2026-07-19 add long press for buttons
2026-07-19 hold ARM for new mouse regardless of state
2026-07-20 stage B complete
2026-07-20 separate the debug printing from the actual timer messages
2026-07-21 cerberus responds correctly to HTTP POST requests
    [main.cpp]
2026-07-27 swap touch buttons for status bar
2026-07-27 add settings switch for verbose serial messages
2026-07-30 all debug print goes through the same queue
2026-07-30 tests and data to back up assertions in timing issues document
    [main.cpp]
2026-07-30 fix up the display syncing with the run time
    [main.cpp, race-timer.h]
2026-07-31 add some reference material for the esp32-s3-super-mini
2026-07-31 prevent misattribution og delayed GOAL events
    [race-timer.h]
2026-07-31 verify retry/dedup fix on hardware
    Confirmed on real cerberus + hesperus: normal ARM/START/GOAL cycles
    unaffected, and a resent duplicate ARM during RUNNING is now recognized
    and skipped instead of wrongly aborting the run.
2026-08-02 create root todo to track issues
2026-08-02 fix debounce on hesperus buttons
    [main.cpp]
2026-08-03 try adding jitter to ack
    [main.cpp]
2026-08-03 fix newly surfaced WDT issue
    [main.cpp]
2026-08-04 closes congestion test and WS jitter
2026-08-05 revert the bad heartbeat change, prepare for no PS session
    [main.cpp]
2026-08-06 session 15 shows that no power saving is still liable to stalls
2026-08-06 add persistent storage and reporting of errors
    [main.cpp]
2026-08-06 add a screen calibration option form the menu
2026-08-06 fix colours on cerberus-ST7789 targets
    [cyd2usb-diymalls-st7789.h]
2026-08-06 add reference docs for QTPy esp32 Pico
    [5395 QT Py ESP32 PICO.step, 5395 QT Py ESP32 PICO.stl]
2026-08-07 add a target for qty-esp32-pico
2026-08-07 touch button sends a touch message to RATS
2026-08-08 calibrate mode responds to remote gates
2026-08-08 cerberus switches to manual mode on loss of WiFi
2026-08-09 add notes for a possible reflective sensor
2026-08-09 verify core 0 has headroom for sensor processing
2026-08-15 touch button sets a flag until new mouse is started
2026-08-15 touch function is on button release
2026-08-17 add the legacy gate detector details
    [gate-detector.kicad_pcb, gate-detector.kicad_sch]
2026-08-26 hesperus-emitter uses deep sleep power saving
2026-08-28 add emitter led datasheet
2026-08-29 emitter cycles through four led states
2026-08-29 add a mechanism for the red/green status leds
2026-08-29 led_flash toggles state
2026-08-30 stream the adc readings
2026-08-30 add optional ADC monitoring
2026-09-06 update the folder structure and import the cerberus case files
    [XDA_blank_rounded_keycaps.3mf, antenna-mount.FCStd, cerberus-case-back.stl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]
2026-09-07 ad the hesperus wall files
    [hesperus-wall-classic-body.stl, hesperus-wall-classic-cap.stl, hesperus-wall-classic-cover-exit-hole.stl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]
2026-09-08 clean up hesperus detector to describe current detection method
2026-09-08 drop support for other boards in hesperus
2026-09-08 consolidate the reflective sensor proposal
2026-09-08 rework detection method to be more robust
    [beam-sensor.h]
2026-09-10 add bill of materials
    [KRONOS-BOM.xls]
2026-09-10 update sensor wall for NB11L battery
    [hesperus-wall-classic-battery-cover.stl, hesperus-wall-classic-body.stl, hesperus-wall-classic-cover-exit-hole-with-hatch.stl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]
2026-09-10 update orcaslicer print file
    [hesperus-wall-parts-classic.3mf]
2026-09-10 update trial notes. switch to 'drop' method for detection
2026-09-12 update the BOM
    [KRONOS-BOM.xls]
2026-09-12 correct exported STLs
    [hesperus-wall-classic-nb11-sliced.stl, hesperus-wall-parts-classic.3mf]
2026-09-15 add the hesperus kicad project
    [ESP32-S3-SuperMini.step, hesperus-detector.kicad_pcb, hesperus-detector.kicad_sch]
2026-09-15 update the 3d print files
    [hesperus-wall-classic-nb11-sliced.stl, hesperus-wall-classic.FCStd, hesperus-wall-parts-classic.3mf]
2026-09-15 slghtly slim the covers
    Just 0.1mm to allow for surface imperfections
2026-09-29 update the 3D print hardware files
2026-09-29 increase the sensor sensitivity
2026-09-30 cerberus boards get unique names
2026-10-11 repair broken test case for mouse exhausting runs
2026-10-12 update the detection filter to reduce false positives
2026-10-12 add beam-trigger diagnostics to gate event messages
    Each trigger message from a gate now carries a diag object: the 15 raw
    samples up to the trigger, the channel's slow baseline, and the other
    channel's drop on the same sample. Cerberus logs it as one [BEAM] line on
    its serial debug log and strips it before the verbose body= line.
